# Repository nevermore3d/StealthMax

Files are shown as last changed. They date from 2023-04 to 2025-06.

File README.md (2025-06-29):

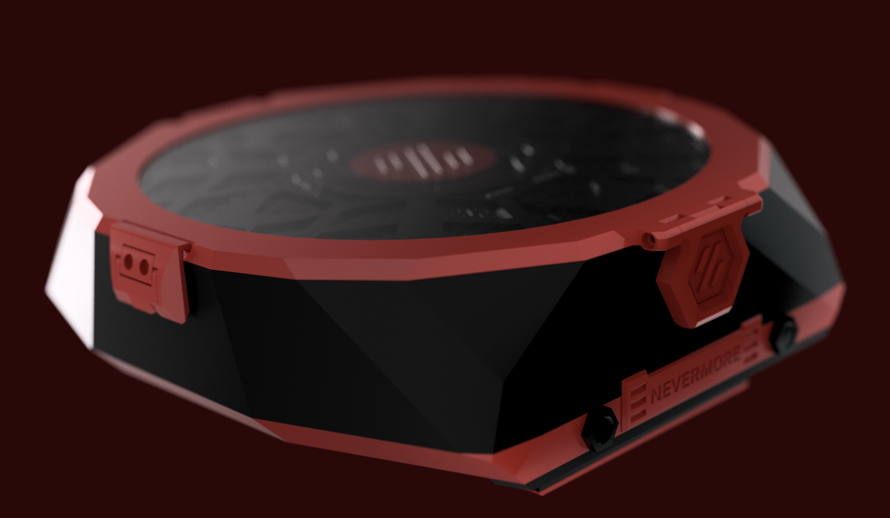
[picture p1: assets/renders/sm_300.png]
StealthMax


# Nevermore StealthMax
The Nevermore StealthMax is an air filter developed for 3D printers.
With its activated carbon and HEPA filtration, it aims to capture harmful fumes and unpleasant odors generated when melting plastics, creating a safer and more pleasant environment for makers.

 

# Table of Contents
1. [About](#1-about)<br>
   .1 [Nevermore3D](#11-nevermore3d)<br>
   .2 [StealthMax](#12-stealthmax)<br>
   .3 [Volatile Organic Compounds (VOCs) and Ultra-Fine Particles (UFPs)](#13-volatile-organic-compounds-vocs)
   
2. [Getting Started](#2-getting-started)<br>
   .1 [Overview](#21-overview)<br>
   .2 [Documentation](#22-documentation)

3. [Bill of Materials (BOM) and Sourcing Guide](#3-bill-of-materials-and-sourcing-guide)<br>
   .1 [StealthMax Kits](#31-stealthmax-kits)<br>
   .2 [Self Sourcing (BOM)](#32-self-sourcing-bom)

4. [Contributing](#4-contributing)<br>
5. [Acknowledgements](#5-acknowledgments)<br>
6. [Showroom](#6-showroom)

# (1) About

##  (1.1) Nevermore3D
Nevermore3D empower the 3D printing community with resources to create their own air filtration systems, promoting a safer and healthier printing environment.

 - ### History
   The project began in 2019 with the [Nevermore Micro](https://github.com/nevermore3d/Nevermore_Micro), a filtration system that has become widely adopted within the Voron community.<br>
   Since then, multiple filtration systems have been developed - with more to come!

    <br>
      

 - ### Nevermore Carbon and other Filtration Media
   When users reported issues of oxidizing and damaging their printers due to bad carbon, we set out to find the most suitable carbon for 3D printing. After consulting leading suppliers, Nevermore3D now offers its own premium carbon of unmatched specifications through selected [resellers](https://github.com/nevermore3d/Reseller).<br>
   Its usally one of the cheapest options in carbon performance/gram as it captures up to 2x its competition, though it might cost more per kilo compared to bulk options; Nevermore Carbon is safe to use in 3D printing environments, offers unbeatable effectiveness targeted at 3D printing VOCs specifically, and every purchase directly contributes to the ongoing development of the Nevermore3D project. Read more on how to evaluate carbon for 3D printing on our [reseller](https://github.com/nevermore3d/Reseller) page!

    - #### Nevermore Carbon
      -   Highly micro-porous and laboratory tested premium activated carbon, from a major European manufacturer
      -   Market-leading VOC adsorption fine tuned for _aromatic hydrocarbons emitted during 3D printing_ such as styrene, benzaldehyde, toluene, benzene, etc. [**CTC >=80**, benzene adsorption capacity up to **0.48g/g**]
      -   Market-leading surface area (storage capacity) of **1250m2/g**!
      -   Vacuum packed for minimal dust generation during shipping.
      -   Vacuum dedusted during the packaging process for immediate use in 3d printers
      -   Available in Regular (750ml, 0.33kg) and XL (2300ml, 1kg)

    - #### Nevermore Scorch
      -   Zeolite-based, highly microporous adsorption medium, enhanced with potassium permanganate (KMnO4).
      -   Chemically transform printer VOC toxins like styrene – a major VOC in ABS and ASA filaments – into harmless potassium benzoate (food additive).
      -   The process is not harmed by high chamber temps, but accelerated, making Nevermore Scorch ideal for heated 3D printer chambers!
      -   Colour changes from bright purple to a dullish gray as it is being spent, giving a visual indication of when it is time to swap filter media!
      -   Available in Regular (750ml, 0.66kg) and XL (2300ml, 2kg)

    - #### Nevermore Boost
      -   Pre-prepared 50/50 mix of Nevermore Carbon and Nevermore Scorch; a less-hassle, best-of-both-worlds printer filtration
      -   Combining the long-life och stellar adsorption capacity of activated carbon with Nevermore Scorch performance in hot surroundings.
      -   Ideal for most users with enclosed 3d printers printing ABS/ASA/PETG/PC in chamber temps of 50C +-10C.

    - #### Nevermore HEPA
      -   Nevermore HEPA Filters

## (1.2) StealthMax
The Nevermore StealthMax improves upon the [Nevermore Max](https://github.com/nevermore3d/Nevermore_Max) with a more warp-resistant frame, smaller size, optional exhaust for cooler printing, and easier assembly.

With its 2-liter carbon basket, it can hold 20 times as much carbon as the Nevermore Micro, and thanks to its innovative dual filtration design, the StealthMax allows for recirculation of filtered air within an enclosed printer to both maintain chamber temperature and further improve filtration efficiency and longevity.

 - #### Dual Filtration
   The StealthMax does not make any compromises and utilizes activated carbon and HEPA filtration:
      
   -   **Activated carbon filter:** This type of filter is designed to absorb volatile organic compounds (VOCs). VOCs are gases emitted during 3D printing, and they can cause irritation to the eyes, nose, and throat. An activated carbon filter can help to reduce odors and improve air quality.

   -   **HEPA (High Efficiency Particulate Air) filter:** This type of filter is effective at capturing tiny particles 2.5um in diameter and below (in 3D printing often _much_ smaller). These particles can - compared to larger PM2.5  particles - have direct toxic effects if inhaled, so a HEPA filter goes a long way to capture both small particles as well as any carbon dust, improving air quality furter in your printing space.

 - #### Recirculation
   The StealthMax and your printer's enclosure function as a closed-loop system, enabling air to recirculate through the filter multiple times. 
   This results in a significantly higher capture rate of harmful particles compared to a single-pass exhaust filter.<br>
   The effectiveness of this process is diminished if the enclosure has leaks, however, opening the exhaust slider creates a slight negative pressure inside the enclosure, thus drawing air in through leaks and maximizing the StealthMax's filtration potential.

 - #### StealthMax S (250)
   Making safer printing more accessible, the StealthMax S was designed for printing on a 250x250mm bed.<br>
   Despite its compact size, the StealthMax S retains impressive filtering capacity thanks to its 1.4-liter carbon basket as well as the benefits of dual filtration.
   [Read more](.../../assets/_unsorted/Stealthmax_S)

## (1.3) Volatile Organic Compounds (VOCs) and Ultra-Fine Particles (UFPs)
When 3D printing, especially with certain types of materials like plastics, various [volatile organic compounds (VOCs)](https://en.wikipedia.org/wiki/Volatile_organic_compound) can be emitted. The specific VOCs produced can vary depending on the type of filament or resin used and the printing conditions. Some common VOCs emitted during 3D printing include:

-  **Styrene**: Commonly emitted when printing with ABS (Acrylonitrile Butadiene Styrene) filament. Styrene exposure has been linked to respiratory issues, irritation of the eyes, nose, and throat, and in some cases, long-term exposure may increase the risk of cancer.
    
-  **Formaldehyde**: Often produced during the thermal decomposition of certain plastics, such as PLA (Polylactic Acid). Formaldehyde exposure can cause irritation of the eyes, nose, and throat, as well as respiratory issues. Prolonged exposure to high levels of formaldehyde has been linked to an increased risk of cancer.
    
-  **Acetaldehyde**: Another byproduct of thermal decomposition, commonly found in emissions from ABS and PLA printing. Acetaldehyde exposure can cause irritation of the eyes, nose, and throat, and may also affect the central nervous system.
    
-  **Acrylonitrile**: Present in emissions from ABS filament, acrylonitrile exposure has been associated with respiratory issues and may increase the risk of certain cancers.
    
-  **Ethylene glycol**: Found in emissions from certain types of resins used in stereolithography (SLA) printing, ethylene glycol exposure can cause irritation of the eyes, skin, and respiratory system.

-  **Butadiene**: Present in ABS-type filaments, as well as rubber additives, long exposures to Butadiene is a known accellerator or cardiovascular disease (heart attacks and strokes), increases the risk of certain cancers, and is suspected to impact fetal development (teratogen).
    
Volatile Organic Compounds (VOCs) can have a range of health effects that vary based on factors such as concentration, duration of exposure, and individual susceptibility. Short-term exposure to high levels of VOCs can cause respiratory tract irritation, headaches, dizziness, and nausea. Prolonged exposure to certain VOCs is associated with more severe health issues, including respiratory problems, an increased risk of cancer, and vascular diseases such as stroke and heart attacks.

Just as individual VOCs can be released into the air, clusters of VOCs, known as **Ultra-Fine Particles (UFPs)**, are also emitted. These particles begin their existence extremely small, with diameters of only 10-15 nm — for comparison, a single VOC molecule is typically about 1 nm, and the grid of a HEPA filter is 20 times larger than a newborn UFP.

If not addressed, these Ultra-Fine Particles gradually coalesce into larger droplets, eventually reaching sizes of about 50-100 nm. At this size, they can be captured by HEPA filters, unless they have already dispersed into the surrounding air. UFPs droplet agglomerates often consist of mixed, room-temperature-viscous VOC oils such as styrene, with some solid components (such as stearic acid, if your chamber is cooler than 70C or so). Unlike larger particles that may accumulate in the airways, breathed UFPs are absorbed by the body—VOC by VOC—similar to inhaled medication, and can exert the same toxic effects as the individual VOCs they contain.

Moreover, carbon porosity is not limited to micropores (carbon pores smaller than 2 nm) but also extends to mesopores (carbon pores 2-50 nm), which can adsorb UFPs before they agglomerate or soak the HEPA. Finally, any carbon dust or larger UFPs bypassing carbon filtering, can be safely collected by the dual integrated HEPA filters of the Stealthmax.

# (2) Getting Started

## (2.1) Overview
Different printers and use cases require different solutions - choose the StealthMax that fits your needs!
 - ### Regular StealthMax (300) or StealthMax S (250)?
   The StealthMax comes in two sizes:
   | | Regular StealthMax (300) | StealthMax S (250) |
   | ---| --- | --- |
   | Min. Req. Bed Size | 300x300mm | 250x250mm|
   | Carbon Capacity | 2.0 liters | 1.4 liters |
   | HEPA Filter | HEPA Filter for Xiaomi Mijia G1 | Nevermore HEPA Filter |
   | Fan | Delta BFB0712HF | Delta KFB0612HAFDB |

 - ### Back Panel Mount or Direct On Panel Mount?
   The are two options for mounting a StealthMax to your printer:
    - #### Back Panel Mount (BPM)
      The Back Panel Mount is designed to be used with Voron printers (in particular Voron 2 and Trident) by utilizing the back panel's cutout and mounting the StealthMax to the top 2020 extrusion.
    - #### Direct On Panel Mount (DOPM)
      Alternatively, the Direct On Panel Mount can be used to mount a StealthMax on pretty much any panel.
	  [Read more](.../../assets/_unsorted/Direct-On-Panel_Mount)

 - ### Basic or Smart?
    - #### Basic
      Simpler to set up, a sensorless StealthMax only requires the appropriate fan, a 12VDC power source (s. [Power Source](#power-source)) and PWM control (e.g. by using your printer's electronics or a Pico).
    - #### Smart
      Thanks to the [Nevermore Controller](#nevermore-controller), a smart StealthMax utilizes VOC, temperature and humidity sensors to monitor air quality and automatically adjust fan speed.

 - ### Add-ons
   Increase the capability of your StealthMax further and explore our range of add-ons:

    - #### CPAP
      Moves the intake closer to the hotend by attaching it directly to the gantry, maximizing VOC capture potential.

    - #### Displays
      [WORK IN PROGRESS / EARLY DEVELOPMENT]<br>
      Upgrade your StealthMax with a GC9A01 or CST816S display to monitor it's effectiveness at a glance.

    - #### Photocatalytic Oxidation (PCO) Filtration
      [WORK IN PROGRESS / EARLY DEVELOPMENT]<br>
      PCO Filtration mimics the sun's natural breakdown of VOCs. Utilizing UVC lights and a TiO2 mesh, it generates hydroxyl radicals to dismantle VOCs into harmless compounds. This method enhances efficiency by addressing stubborn VOCs, maintains cleanliness between prints, and adapts to heat conditions for optimal performance.
      [Read more](.../../assets/_unsorted/PCO)

 - ### User Mods
   Find clever solutions and unique customizations with our collection of [User Mods](/UserMods) contributed by fellow community members.

## (2.2) Documentation
 - ### Manual
   soon<sup>tm</sup><br>
   In the meantime, you may find the [DOPM focused installation documentation](https://github.com/nevermore3d/StealthMax/blob/main/Docs/DOPM/DOPM_Preparation.md) useful.

 - ### Print Guide
   Our interactive [Print Guide](https://bit.ly/NevermoreStealthMaxPrintGuide) helps you find the parts you need to print and lets you download all the required STL files at once.

 - ### Nevermore Controller
   A Raspberry Pi Pico W based controller for the Nevermore3D family of 3D printer filters created and maintained by [@SanaaHamel](https://github.com/SanaaHamel). Compatible with Klipper, it offers automatic fan control and leverages Bluetooth LE technology to reduce wiring needs and allow for multiple device connections.
   [Read more](https://github.com/SanaaHamel/nevermore-controller)

# (3) Bill of Materials and Sourcing Guide

#### Power Source
The StealthMax Kits and Bill of Materials (BOM) do not include a power source.<br>
You will need to choose between one of the following options:
-   A 12V power supply unit (PSU) with a minimum rating of 1.5 Amps.
-   Utilize a voltage-selectable fan port on your printer's electronics (if available).

## (3.1) StealthMax Kits
For those who value convenience and simplicity, kits eliminate the guesswork and ensure you have everything you need.

| Kit | StealthMax Size | Sources |  |  |  |
|---|---|---|---|---|---|
| Basic | 300 (Regular) | UK [OneTwo3D](https://www.onetwo3d.co.uk/product/nevermore-stealthmax-filter-kit-basic/?wpam_id=2) |  |  |  |
| Basic S | 250 (S) | UK [OneTwo3D](https://www.onetwo3d.co.uk/product/nevermore-stealthmax-filter-s-kit-basic/?wpam_id=2) |  |  |  |
| Smart | 300 (Regular) | UK [OneTwo3D](https://www.onetwo3d.co.uk/product/nevermore-stealthmax-filter-kit/?wpam_id=2) | US [FYSETC](https://s.click.aliexpress.com/e/_msl6FbE) | US [Central 3D Printing](https://central3dprinting.com/products/nevermore-stealthmax-kit?ref=NEVERMORE3D) | US [Mandala Rose Works](https://mandalaroseworks.com/products/nevermore-stealthmax-hardware-kit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) | Sweden [3DKATTEN](https://3dkatten.se/en/products/stealthmax-kit?_pos=2&_sid=fafe2628b&_ss=r) |
| Smart S | 250 (S) | UK [OneTwo3D](https://www.onetwo3d.co.uk/product/nevermore-stealthmax-s-filter-kit-advanced/?wpam_id=2) | US [Central 3D Printing](https://central3dprinting.com/products/nevermore-stealthmax-s-hardware-kit?ref=NEVERMORE3D) | US [Mandala Rose Works](https://mandalaroseworks.com/products/nevermore-stealthmax-s-small-hardware-kit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) |  |
| Fasteners | _both_ | UK [OneTwo3D](https://www.onetwo3d.co.uk/product/nevermore-stealthmax-fastener-kit/?wpam_id=2) | | | |
| Printed Parts | 300 (Regular) | UK [JB3D](https://jb3d.uk/product/nevermore-stealthmax/) |  |  |  |
| Printed Parts | 250 (S) | UK [JB3D](https://jb3d.uk/product/nevermore-stealthmax-s-printed-parts-kit/) |  |  |  |

Affiliate links: may earn the Nevermore3D project a small commission (at no extra cost to you).

## (3.2) Self Sourcing (BOM)
For those who find satisfaction in the journey, each meticulously sourced component adds to the story of their creation.

See our interactive [Bill of Materials / Sourcing Guide](https://bit.ly/NevermoreStealthMaxBOM) for a complete list of components.

# (4) Contributing
**We welcome your contributions!** <br>
Report any difficulties, suggest ideas, propose solutions, and create new designs or enhance existing ones.
Whether on GitHub or the [Nevermore Discord](https://discord.gg/H8tZ9fZVQ4), your input is valued and appreciated!



# (5) Acknowledgments
Special thanks for all the help, nudges, support and additions to the project, goes to:
- [@SanaaHamel](https://github.com/SanaaHamel)
- [@FatalBulletHit](https://github.com/FatalBulletHit)
- @TubaToothpasties
- [@Blamm](https://github.com/bartlammers)
- [@Backslash](https://github.com/UnPure)
- [@Exerqtor](https://github.com/Exerqtor)
- [@AdamV3D](https://github.com/AdamV3D)
- [@rajenki](https://github.com/rajenki)

# (6) Showroom
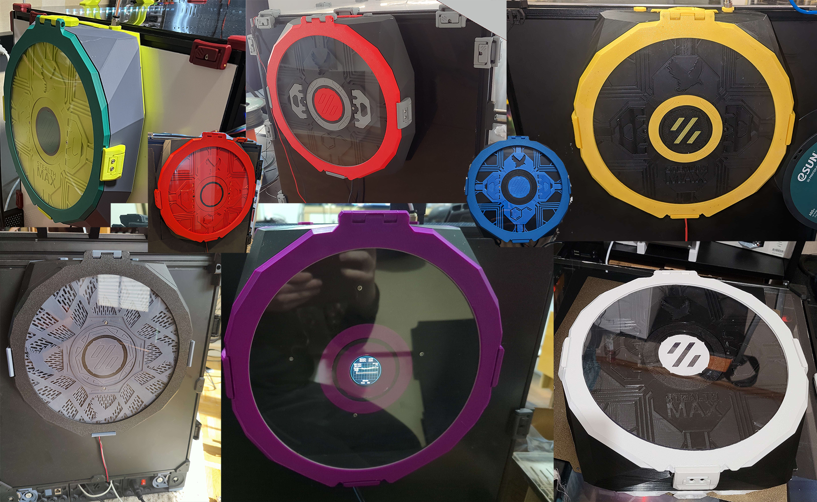
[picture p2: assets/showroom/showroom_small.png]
StealthMax Showroom

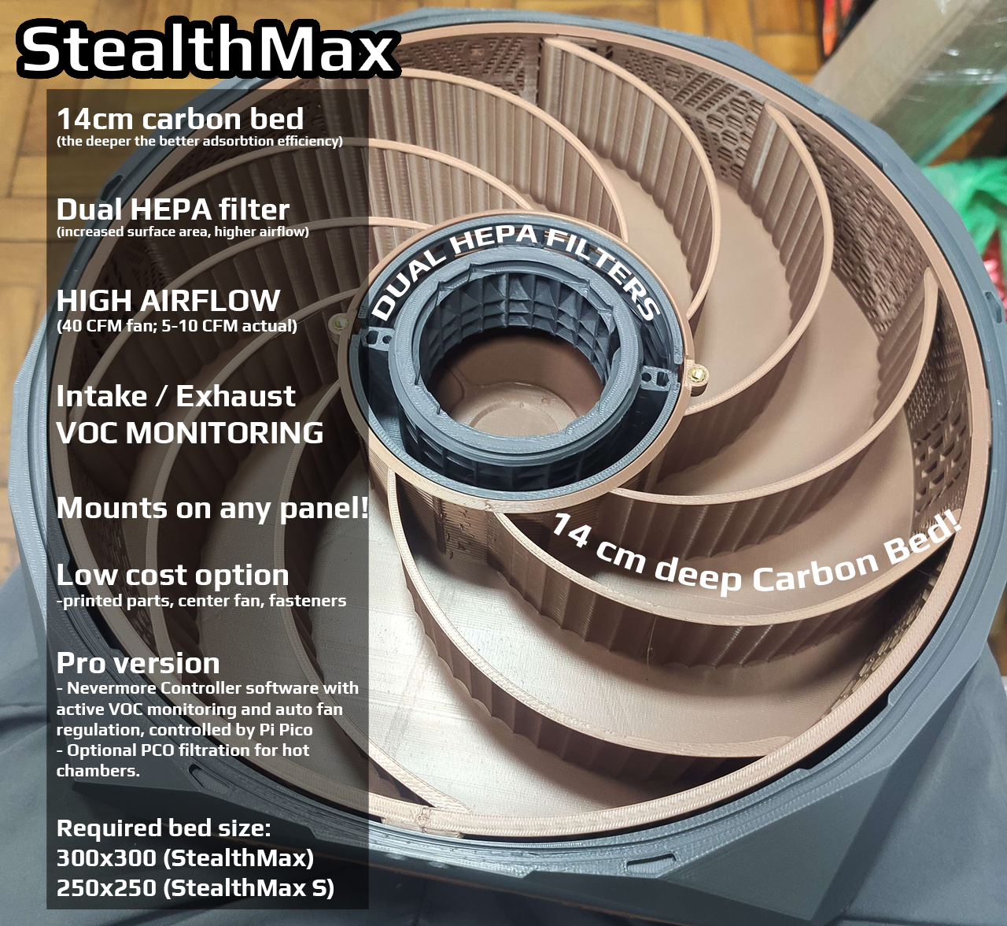
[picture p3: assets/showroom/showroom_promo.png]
StealthMax Promo


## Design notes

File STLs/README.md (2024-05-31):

# Print Guide
Check out our interactive [Print Guide](https://bit.ly/NevermoreStealthMaxPrintGuide)!

For printing tips and tricks, see the [Nevermore StealthMax Wiki](https://github.com/nevermore3d/StealthMax/wiki).

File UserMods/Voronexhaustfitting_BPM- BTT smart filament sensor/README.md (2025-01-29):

Added a bracket for the BTT smart filament sensor V2.  
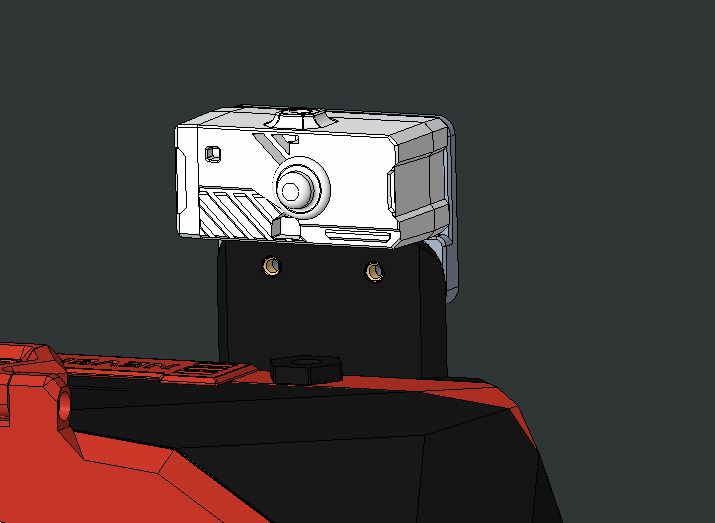
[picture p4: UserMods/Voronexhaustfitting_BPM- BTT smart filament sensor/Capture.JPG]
assembly
  
additionally need 2pcs M3 heat set insert and 5pcs M3 SHCS screws.

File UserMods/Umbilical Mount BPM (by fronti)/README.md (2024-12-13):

I couldn't get a decent umbilical passthrough working for my Stealthmax S, so i merged the Back Panel Mount with [Another Umbilical Toolhead](https://www.printables.com/model/411846-another-toolhead-umbilical-for-voron-24).

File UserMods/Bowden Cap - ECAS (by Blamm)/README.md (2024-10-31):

ECAS Bowden Cap

A custom version of the [Bowden Cap](/STLs/1_FlowChamber/1.3b_BowdenCap_Open.stl) designed to accomodate an ECAS coupler.
To be used for alternative cable routing through the Bowden Cap together with the [Cable Entry Cap (Closed)](/STLs/1_FlowChamber/1.4b_CableEntryCap_Closed.stl).

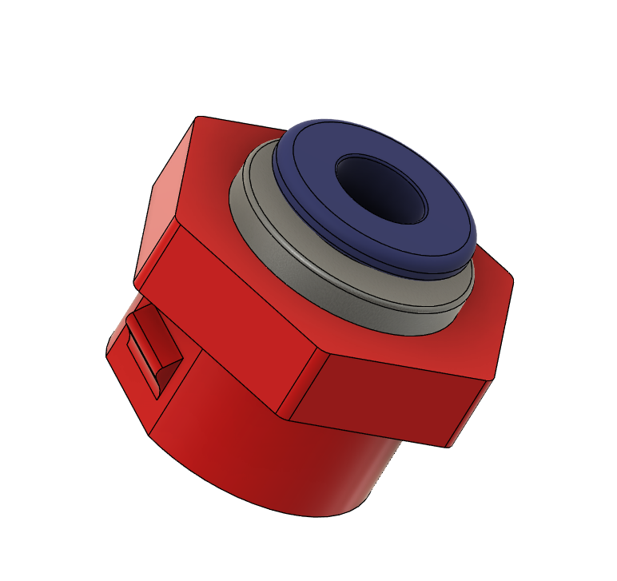
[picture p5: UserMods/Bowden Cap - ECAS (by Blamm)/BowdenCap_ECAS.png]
ECAS Bowden Cap


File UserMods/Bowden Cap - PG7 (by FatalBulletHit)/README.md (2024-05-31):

A custom version of the [Bowden Cap](/STLs/1_FlowChamber/1.3b_BowdenCap_Open.stl) designed to accomodate a PG7 cable gland with strain relief.<br>
To be used for alternative cable routing through the Bowden Cap together with the [Cable Entry Cap (Closed)](/STLs/1_FlowChamber/1.4b_CableEntryCap_Closed.stl).

Sources: [Bimed cable gland, PG7](https://www.traceparts.com/en/product/automationdirect-bimed-cable-gland-pg7-thread-type-polyamide-black-accepts-3-to-65mm-diameter-cable-ip68-with-strain-relief-pac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)

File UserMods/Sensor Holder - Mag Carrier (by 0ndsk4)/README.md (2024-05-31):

Idea was to have a detachable screen for the SMS type layout with no center hub. Only problem is 4-pin is not enough (if not a I2c screen that can daisy chain on the sensor connection).
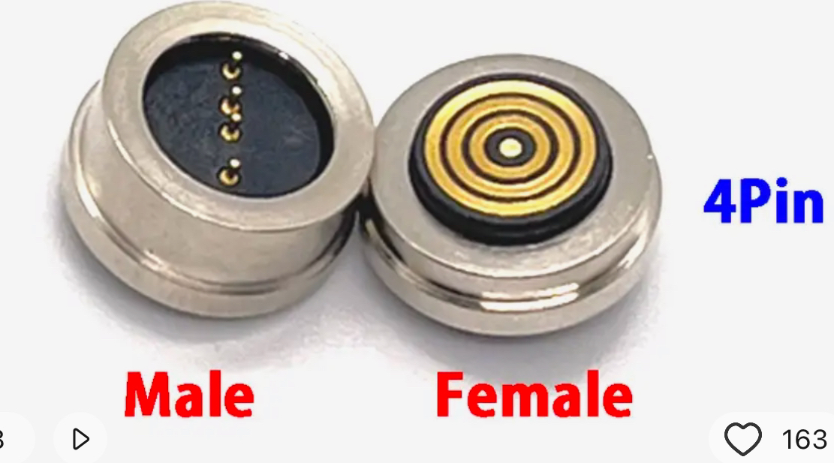
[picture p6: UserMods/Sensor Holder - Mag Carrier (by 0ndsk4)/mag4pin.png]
Magnetic 4 Pin Connector


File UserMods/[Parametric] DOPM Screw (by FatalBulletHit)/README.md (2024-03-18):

A parametric version of the default [Direct On Panel Mount Screw](/STLs/0_Mount/0b_DirectOnPanelMount/0b.1_DirectOnPanelMountScrew_DOPM.stl) for panels thicker than 3mm.

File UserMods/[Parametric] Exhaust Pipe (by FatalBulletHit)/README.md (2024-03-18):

A parametric version of the default [Exhaust Pipe](/STLs/0_Mount/0b_DirectOnPanelMount/0b.2_ExhaustPipe_DOPM.stl) for panels thicker than 3mm.

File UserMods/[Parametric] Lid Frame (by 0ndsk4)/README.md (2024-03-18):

A parametric version of the default [Lid Frame](/STLs/3_Lid/StealthMax/M_3.0_LidFrame.stl) and [Lid Panel Holder](/STLs/3_Lid/StealthMax/M_3.1_LidPanelHolder.stl) for non standard lid panels.

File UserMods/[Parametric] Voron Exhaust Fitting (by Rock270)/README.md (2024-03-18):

**Parametric exhaust fitting by Rock270**

This is a parametric clone of the default [Voron Exhaust Fitting (Back Panel Mount)](/STLs/0_Mount/0a_BackPanelMount/StealthMax/M_0a.0_VoronExhaustFitting_BPM.stl) for use on panels of thicknesses larger than 4mm. If you wish to use this, instead of printing "M_0a.0_VoronExhaustFitting_BPM.stl", print one "M_VoronExhaustFitting_BPM_Xmm" with the desired panel thickness.

If you wish to use a panel thickness not supplied, simply open "Parametric Exhaust Fitting BPM (by Rock270)" and modify the "panel_thickness" parameter.

Use the following information to get your new screw sizes.

Current affected screws
```
M3x10 x4
M3x12 x7
M3x25 x2
```

Each screw length is to be increased by panel_thickness-4.

New screws
```
4x: M3x(6+panel_thickness) (Threads into heat set inserts in the flow chamber, followed by empty air. Probably ok to be long by a few mm)
7x: M3x(8+panel_thickness) (Threads into 11mm holes in the flow chamber, probably ok to be short by a few mm)
2x: M3x(21+panel_thickness) (Important, these hold the filter/panel to frame. Try to get these in the correct length)
```

Example:
I want a 14mm panel. I will need:
```
4x: M3x20 SHCS
7x: M3x22 SHCS
2x: M3x35 SHCS
```
In the default configuration, the M3x12 screws thread directly into an 11mm hole in the voron exhaust fitting. As 22mm is an odd screw size, M3x20 SHCS screws will suffice for these screws. 35mm and 20mm are common screw lengths so no changes are needed.

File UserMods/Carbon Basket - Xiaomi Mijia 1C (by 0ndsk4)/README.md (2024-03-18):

A basket for the Xiaomi Mijia 1C HEPA filter. Enjoy with caution, has the tendency to break apart if tabs are not removed:
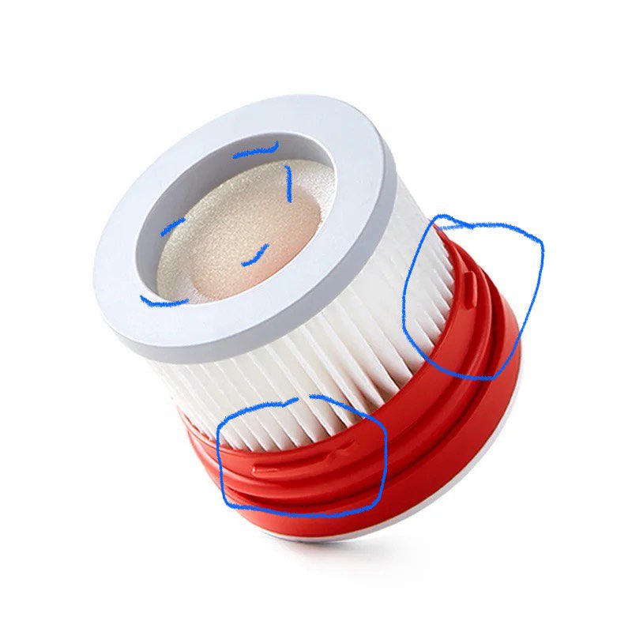
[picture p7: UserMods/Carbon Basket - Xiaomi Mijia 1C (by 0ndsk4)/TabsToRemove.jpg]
TabsToRemove


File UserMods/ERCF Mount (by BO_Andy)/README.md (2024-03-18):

A mount for the [Enraged Rabbit Carrot Feeder MMU](https://github.com/Enraged-Rabbit-Community/ERCF_v2) that allows the MMU to be positioned above a back panel mounted StealthMax.

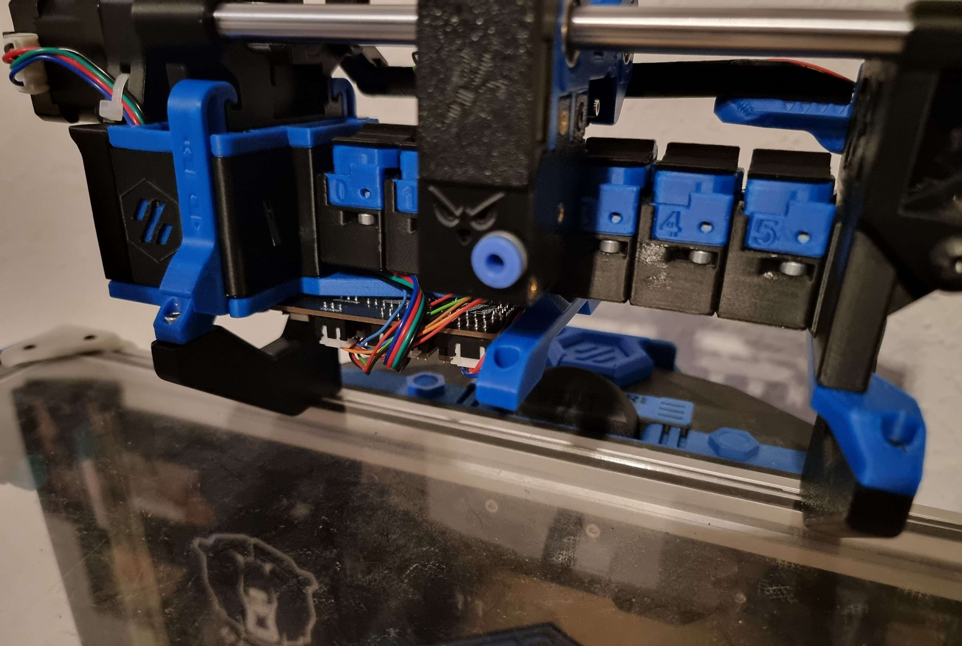
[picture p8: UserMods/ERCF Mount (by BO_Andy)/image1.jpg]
ERCF_Mount

<BR>
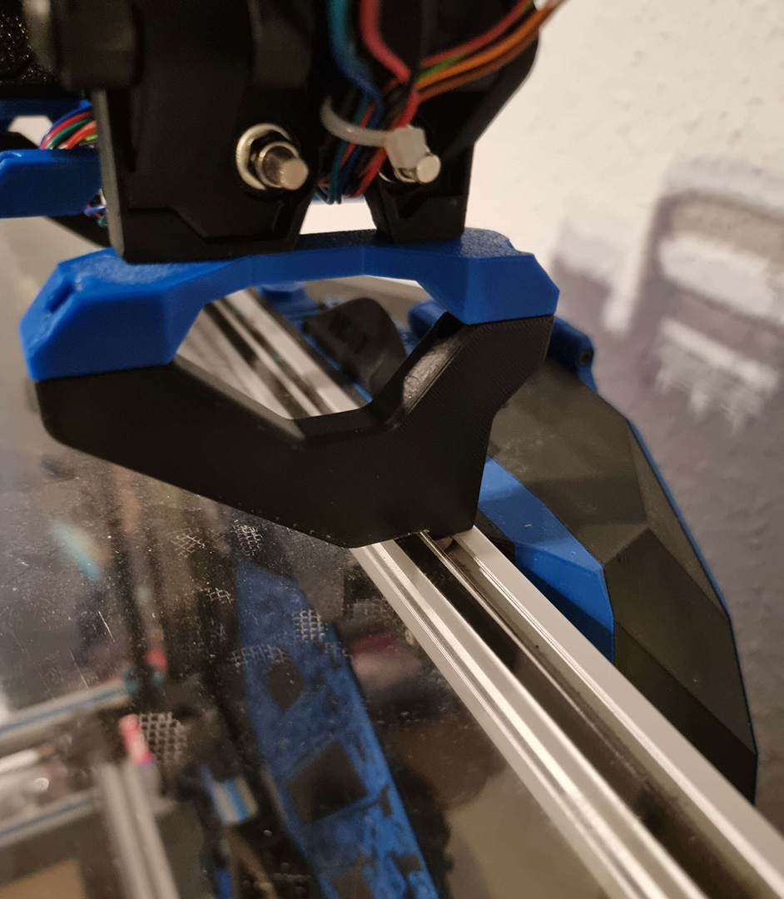
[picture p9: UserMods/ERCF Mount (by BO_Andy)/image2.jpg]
ERCF_Mount


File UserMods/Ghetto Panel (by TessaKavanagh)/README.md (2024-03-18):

A printed alternative to the acrylic panel used in the lid.

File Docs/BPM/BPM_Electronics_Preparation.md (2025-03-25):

# Back Panel Mount (BPM) Smart Electronics Preparation

These are instructions for the StealthMax (300) Smart Back Panel Mount (BPM). The majority of this part is borrowed from the DOPM documentation but with replaced images for continuity.

## Parts Required

Printed parts:
- 1x [1.4a_CableEntryCap_M8Barrel.stl](../../STLs/1_FlowChamber/1.4a_CableEntryCap_M8Barrel.stl)

Hardware:
- Raspberry Pi Pico W
- Female Dupont pins
- Male JST-PH 2.0 pins
- 1x M8 threaded DC connector
- 1x Matek Systems MBEC6S/MBEC2A
- 2x BME280
- 2x SGP40/SGP30
- 3x right angle 4-pin male header
- 1x right angle 5-pin male header
- 2x straight 4-pin male header
- 5x 4-pin female DuPont connector housing
- 1x 4-pin JST-PH 2.0 male pin/female connector housing

Tools:
- DuPont crimping tool
- JST crimping tool

## Back Panel Mount (BPM) Smart Electronics Preparation

1. With the Raspberry Pi Pico W accessible, start by flashing the latest controller firmware on it according to the [Nevermore Controller Setup Guide](https://github.com/SanaaHamel/nevermore-controller#guide-setup). In short:
   - Download the latest Nevermore Controller uf2 binary.
   - Connect the Raspberry Pi Pico W via USB Micro to a computer while holding down the BOOTSEL button.
   - Copy the downloaded .uf2 binary to the RPI-RP2 drive.
     - The Raspberry Pi Pico W will automatically reboot afterward.
   - SSH into your printer's Klipper host (e.g. a regular Raspberry Pi).
   - Install the Nevermore Controller Klipper module.
     - Restart your Klipper host if you enabled Bluetooth during the installation process.
   - Add the [minimal example configuration](https://github.com/SanaaHamel/nevermore-controller#klipper-config-minimal) to your printer.cfg.
   - We'll add the Nevermore macros from the Nevermore Controller Setup Guide to the relevant print start/end macros, and calibrate the sensors at a later stage.

1. Remove the nut from the M8 threaded DC connector and solder 75mm red and black 24 AWG wires to it. Apply a small section of heat shrink tubing to both leads, then slide the cables through the [1.4a_CableEntryCap_M8Barrel.stl](/STLs/1_FlowChamber/1.4a_CableEntryCap_M8Barrel.stl) and thread in the M8 threaded DC connector securely. Adding heatshrink over the soldered joints would be a good idea at this point.
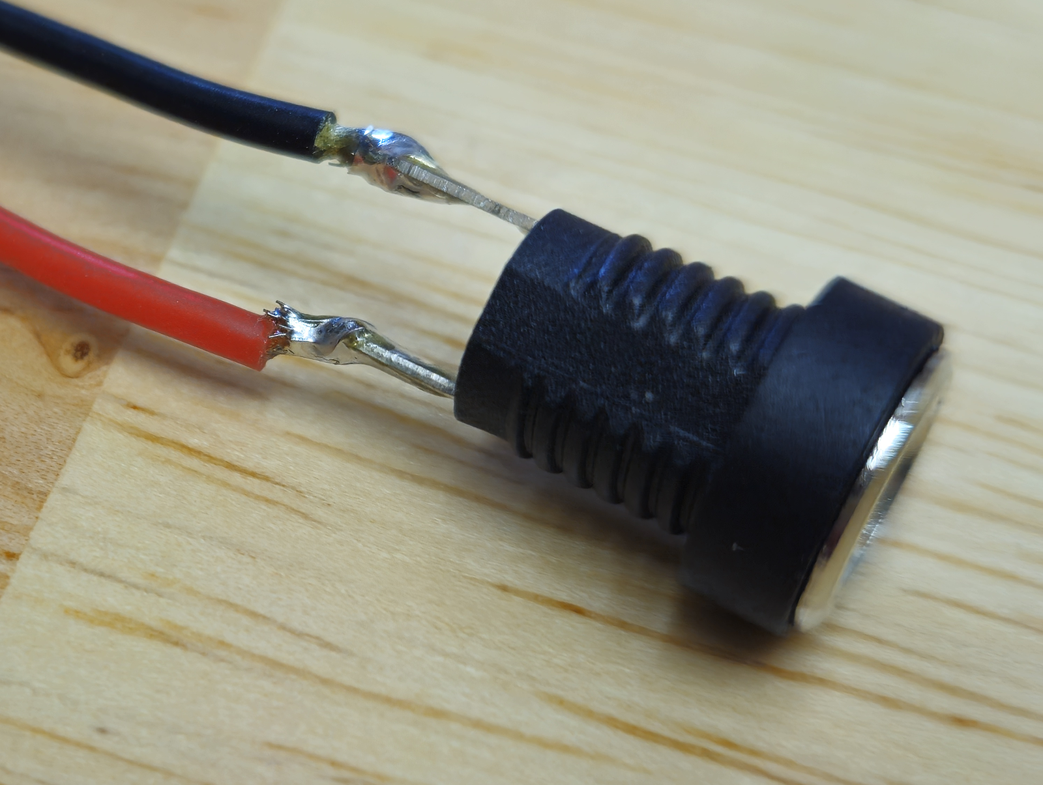
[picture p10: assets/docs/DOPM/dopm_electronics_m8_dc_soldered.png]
M8 threaded DC connector soldered

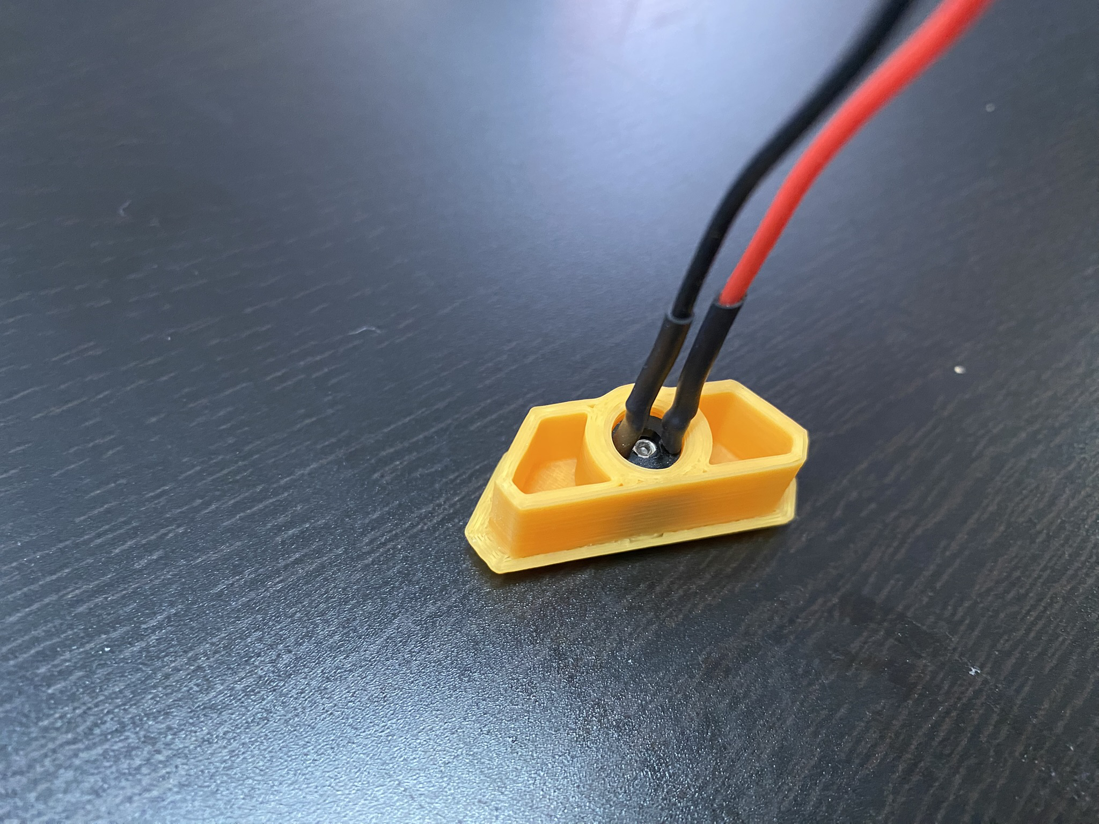
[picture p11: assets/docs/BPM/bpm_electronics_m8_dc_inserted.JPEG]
M8 threaded DC connector inserted


1. Solder a right angle 4-pin male header to the Matek Systems MBEC6S/MBEC2A buck converter.
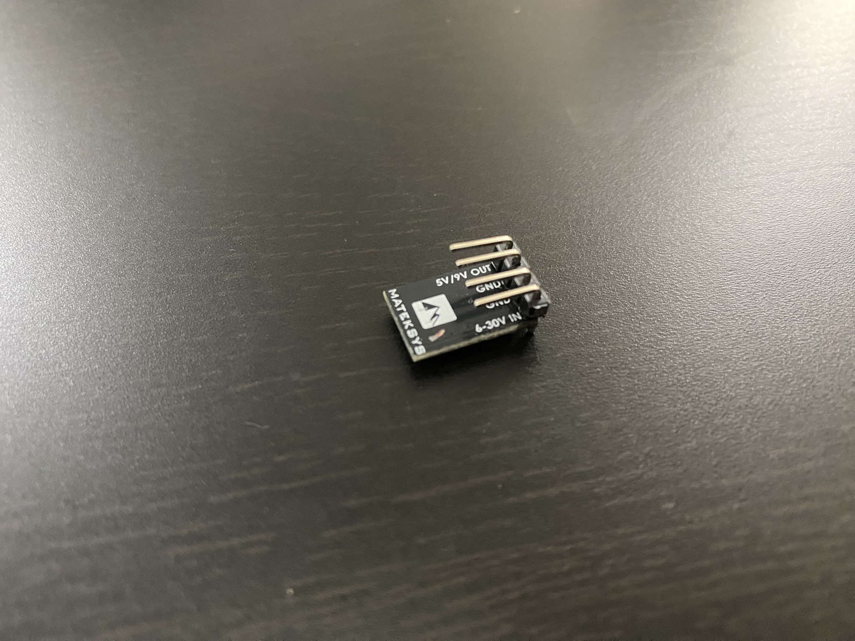
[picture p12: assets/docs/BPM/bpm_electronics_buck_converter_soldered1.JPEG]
Matek Systems MBEC6S/MBEC2A buck converter soldered

Matek Systems MBEC6S/MBEC2A buck converter soldered

1. Solder the straight 4-pin male header to each of the BME280 PCBs.
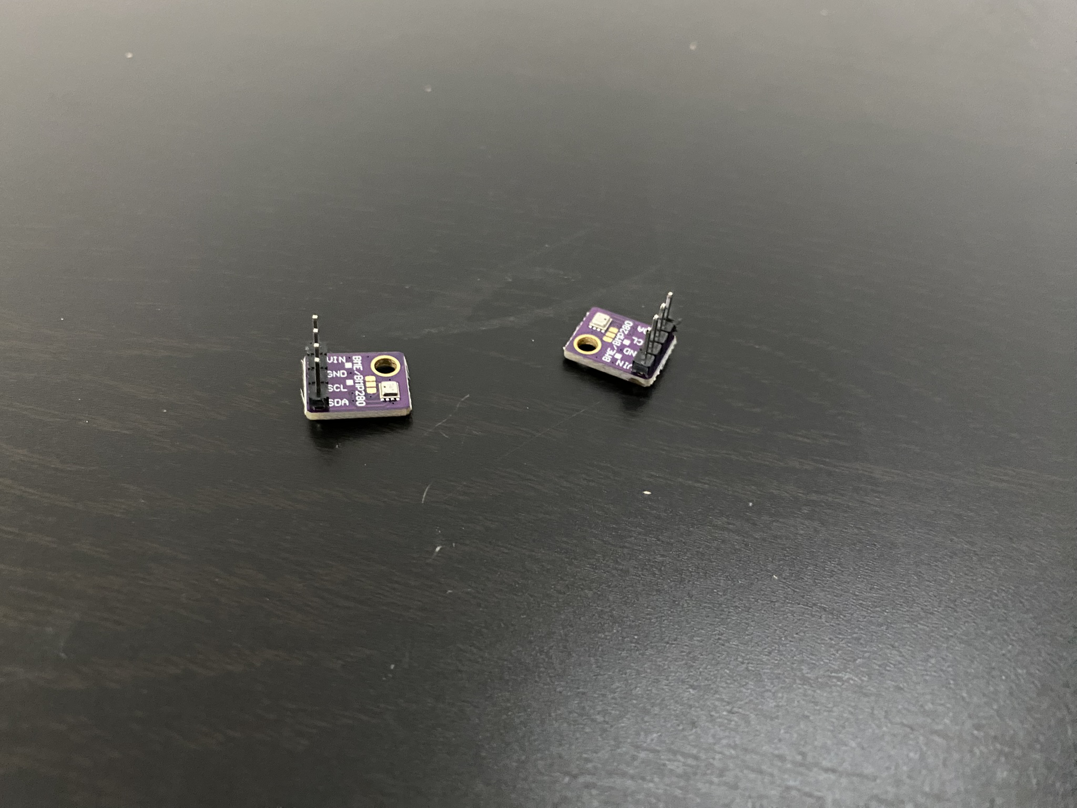
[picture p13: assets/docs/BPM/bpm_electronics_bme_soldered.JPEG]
BME280 PCBs soldered


1. Add the SGP40/SGP30 PCBs on top of each of the pins soldered to the BME280 PCBs and solder it from the other side. Take extra care to not leave excess solder here, as it may interfere with the DuPont connector later.
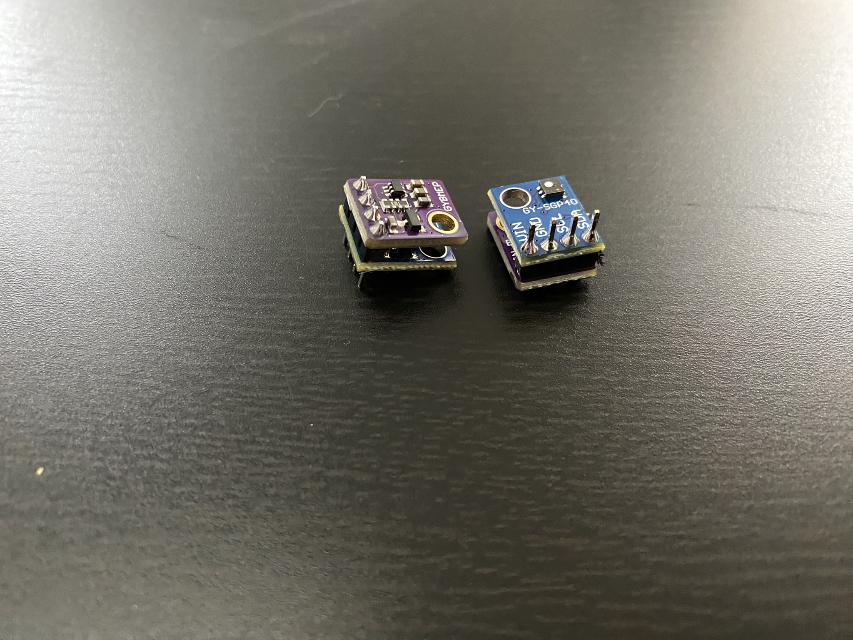
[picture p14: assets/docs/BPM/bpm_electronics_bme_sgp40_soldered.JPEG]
SGP40 PCBs soldered

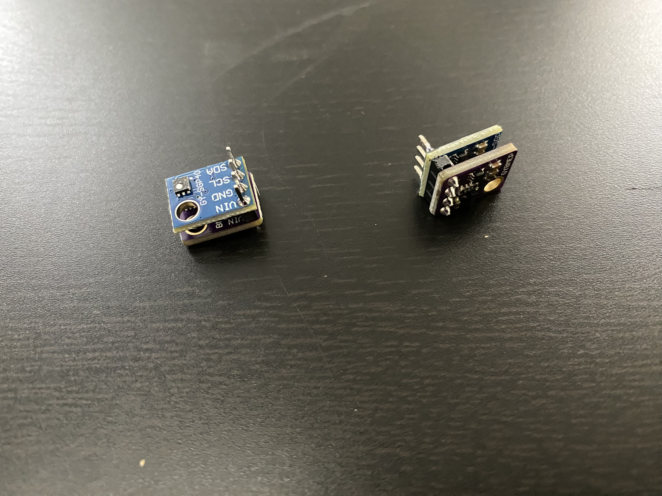
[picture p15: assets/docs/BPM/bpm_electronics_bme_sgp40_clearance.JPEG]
BME280 SGP40 pins clearance


1. Solder 2x right angle 4-pin male header and 1x right angle 5-pin male header to the Raspberry Pi Pico W.
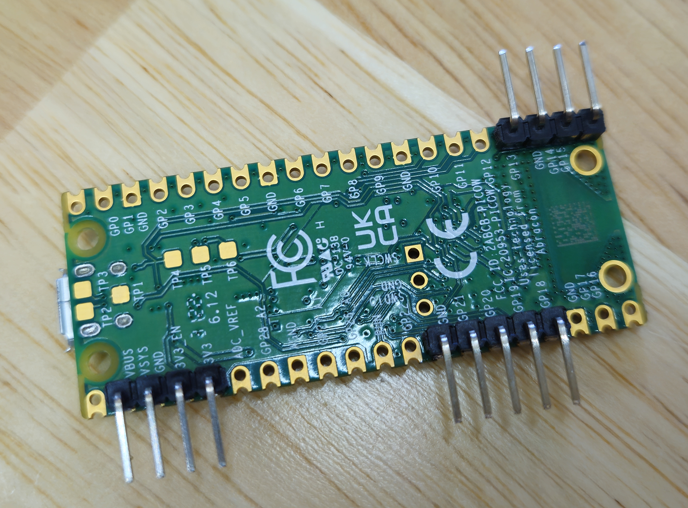
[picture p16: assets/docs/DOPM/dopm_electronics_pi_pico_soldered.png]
Raspberry Pi Pico W soldered


1. Crimp 4 DuPont female pins to the 325mm yellow, pink, black, and green 26 AWG wires. Insert the crimped wires into a 4-pin DuPont connector housing.
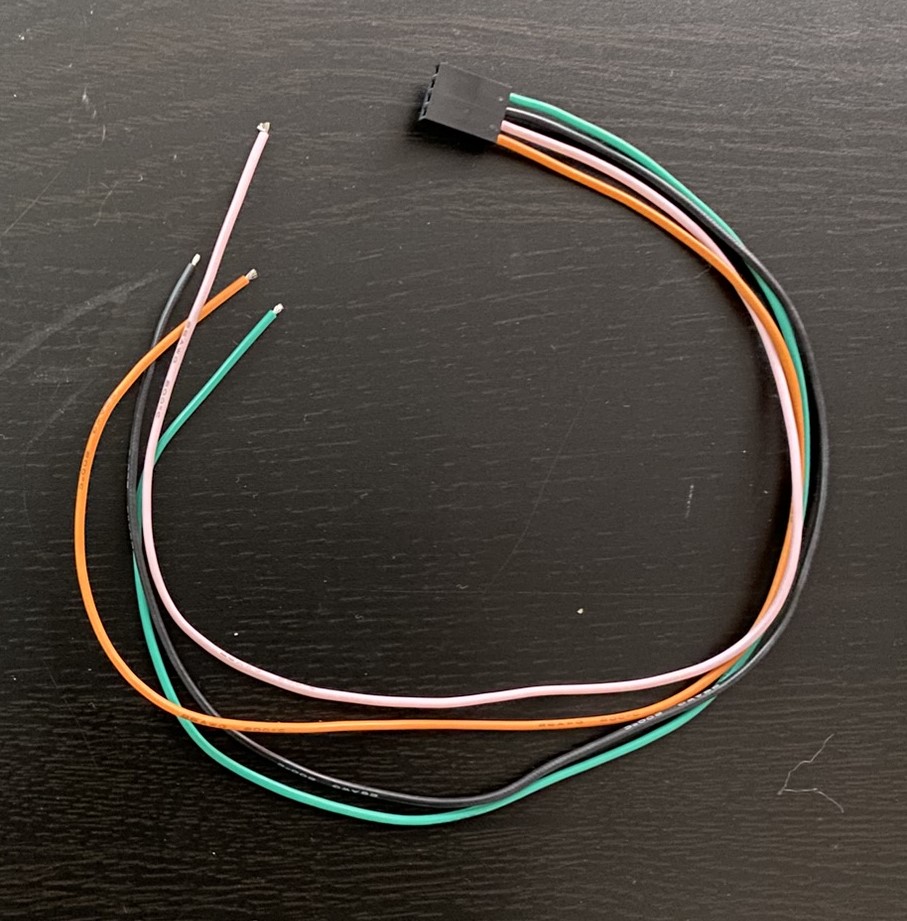
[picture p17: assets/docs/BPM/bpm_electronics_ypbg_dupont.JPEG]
Yellow/Pink/Black/Green DuPont connector


1. Crimp 4 DuPont female pins to the 300mm blue, gray, black, and green 26 AWG wires. Insert the crimped wires into a 4-pin DuPont connector housing.
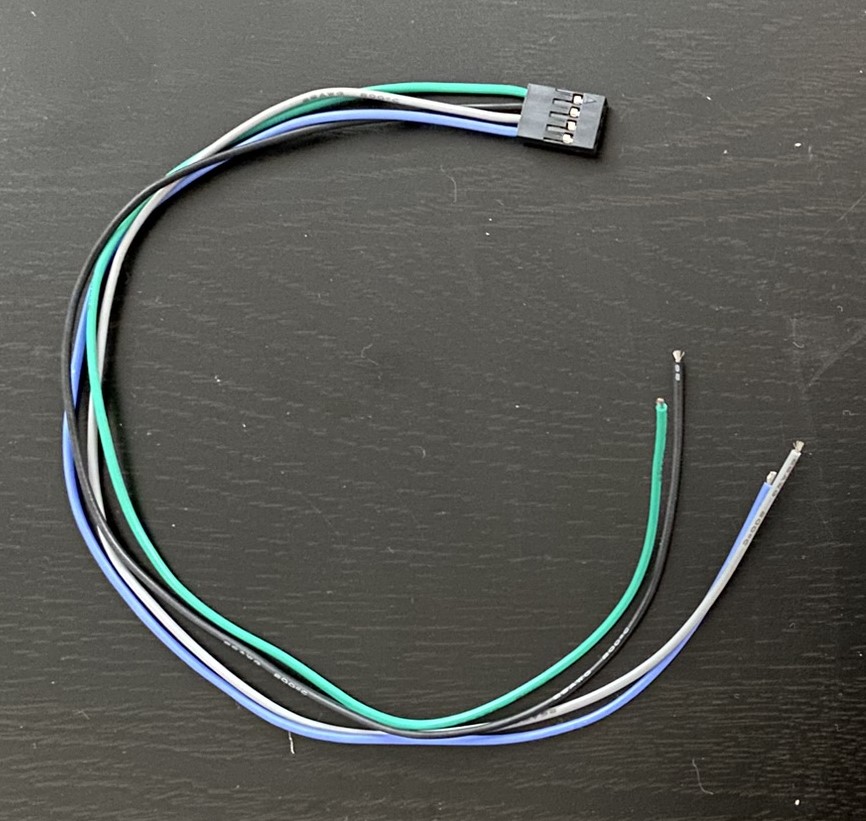
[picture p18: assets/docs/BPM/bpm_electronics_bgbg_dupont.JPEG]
Blue/Gray/Black/Green DuPont connector


1. Crimp 2 DuPont female pins to the other end of the blue and gray wires from step 7, and yellow and pink wires from step 8. Do not crimp the black and green wires yet on either cable harness.
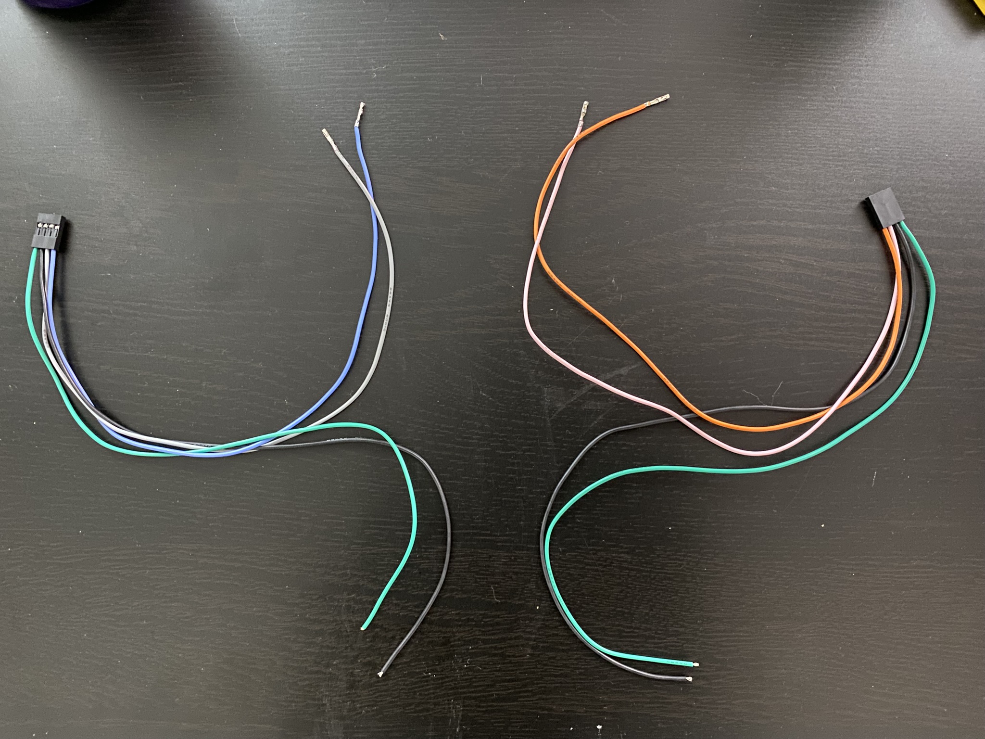
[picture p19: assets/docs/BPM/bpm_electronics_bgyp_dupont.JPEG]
Blue/Gray/Yellow/Pink DuPont pins


1.  Crimp 2 DuPont female pins to the 100mm violet and brown 26 AWG wires.
2.  Crimp 4 JST-PH 2.0 male pins to the 100mm violet and brown 26 AWG wires, and 200mm black and red 24 AWG wires. Insert the crimped violet and brown wires into a 4-pin DuPont connector housing, and the crimped violet, brown, red, and black wires into a 4-pin JST-PH 2.0 connector housing. There is a good example of this in the DOPM guide.
    - If you do not have JST-PH 2.0 male pins/female housing, solder the violet, brown, red, and black wires directly to a JST-PH 2.0 male housing, or a pre-crimped JST-PH 2.0 male pins/female housing assembly. If soldering, heatshrink is recommended to prevent shorts. (This is what this guide will show)
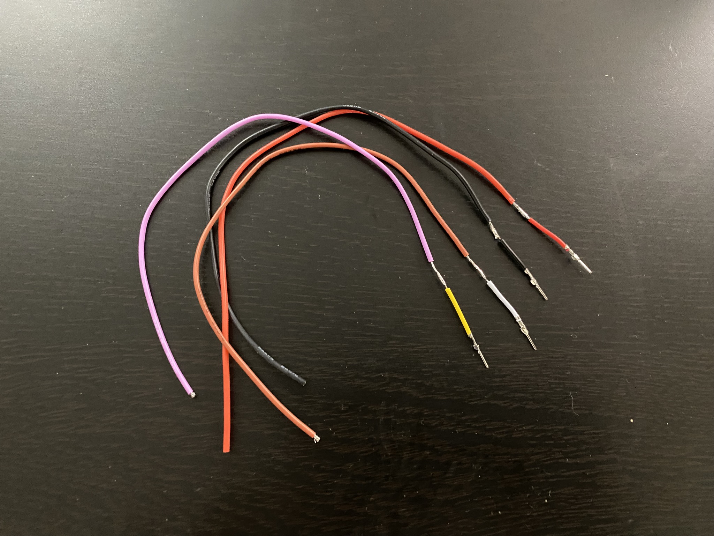
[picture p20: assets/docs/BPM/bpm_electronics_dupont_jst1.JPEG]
DuPont JST-PH harness Soldering

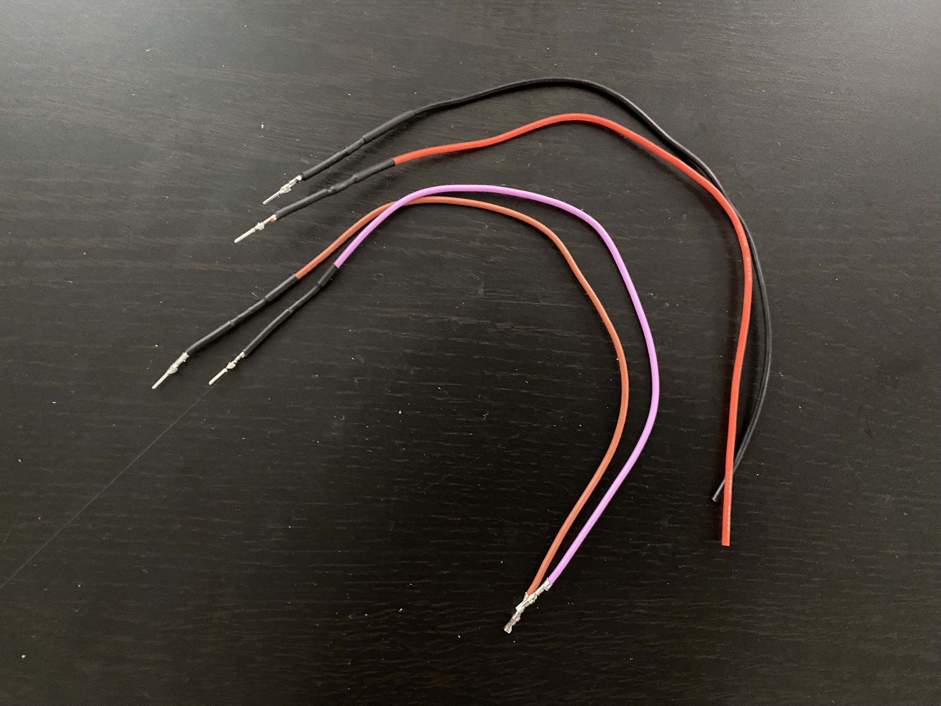
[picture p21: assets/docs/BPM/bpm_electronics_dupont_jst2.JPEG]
DuPont JST-PH harness Heatshrink

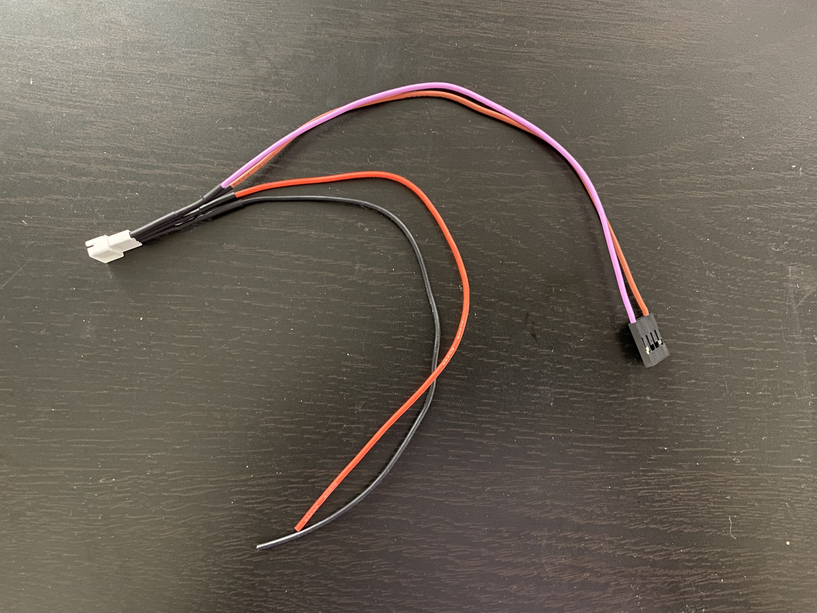
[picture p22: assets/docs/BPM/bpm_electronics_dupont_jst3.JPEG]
DuPont JST-PH harness


1.  Crimp 2 DuPont female pins to the red and black wires from step 11 and the red and black wires from step 2. Two wires into one DuPont pin is a tight fit, but it can be done with some patience.
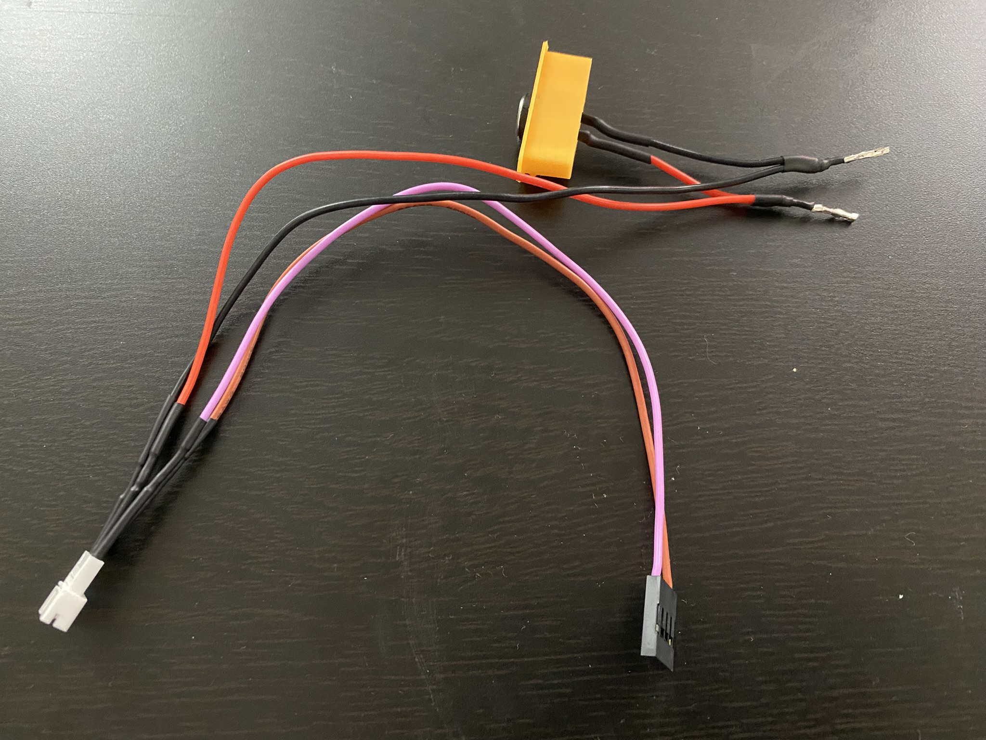
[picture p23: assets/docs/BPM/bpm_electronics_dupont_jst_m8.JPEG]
DuPont JST-PH M8 harness


1.  Insert the double-crimped red and black wires into a 4-pin DuPont connector housing.
    
1.  4 DuPont female pins to the 50mm red and black 24 AWG wires (both ends). Insert the crimped wires into a 4-pin DuPont connector housing and the other ends into the remaining slots of the DuPont connector housing of step 13. 
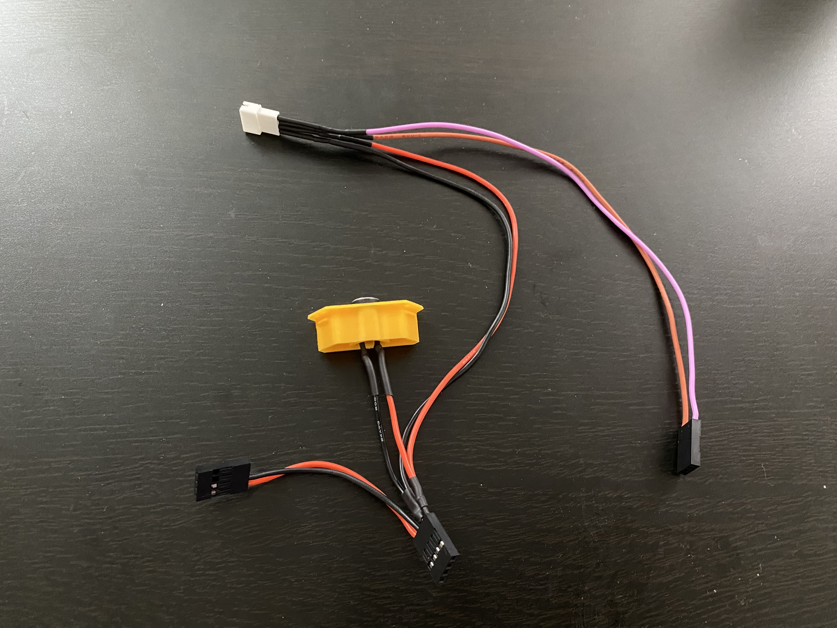
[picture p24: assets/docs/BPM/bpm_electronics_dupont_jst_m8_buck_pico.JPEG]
Dupont JST-PH M8 buck converter Pi Pico harness


[Next: Back Panel Mount (BPM) Flow Chamber Assembly >](BPM_Flow_Chamber_Assembly.md)

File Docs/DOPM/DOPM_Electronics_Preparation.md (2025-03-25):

# Direct On Panel Mount (DOPM) Smart Electronics Preparation

These are instructions for the StealthMax (300) Smart Direct On Panel Mount (DOPM).

## Parts Required

Printed parts:
- 1x [1.4a_CableEntryCap_M8Barrel.stl](/STLs/1_FlowChamber/1.4a_CableEntryCap_M8Barrel.stl)

Hardware:
- Raspberry Pi Pico W
- Female Dupont pins
- Male JST-PH 2.0 pins
- 1x M8 threaded DC connector
- 1x Matek Systems MBEC6S/MBEC2A
- 2x BME280
- 2x SGP40/SGP30
- 3x right angle 4-pin male header
- 1x right angle 5-pin male header
- 2x straight 4-pin male header
- 5x 4-pin female DuPont connector housing
- 1x 4-pin JST-PH 2.0 male pin/female connector housing

Tools:
- DuPont crimping tool
- JST crimping tool

## Direct On Panel Mount (DOPM) Smart Electronics Preparation

1. With the Raspberry Pi Pico W accessible, start by flashing the latest controller firmware on it according to the [Nevermore Controller Setup Guide](https://github.com/SanaaHamel/nevermore-controller#guide-setup). In short:
   - Download the latest Nevermore Controller uf2 binary.
   - Connect the Raspberry Pi Pico W via USB Micro to a computer while holding down the BOOTSEL button.
   - Copy the downloaded .uf2 binary to the RPI-RP2 drive.
     - The Raspberry Pi Pico W will automatically reboot afterward.
   - SSH into your printer's Klipper host (e.g. a regular Raspberry Pi).
   - Install the Nevermore Controller Klipper module.
     - Restart your Klipper host if you enabled Bluetooth during the installation process.
   - Add the [minimal example configuration](https://github.com/SanaaHamel/nevermore-controller#klipper-config-minimal) to your printer.cfg.
   - We'll add the Nevermore macros from the Nevermore Controller Setup Guide to the relevant print start/end macros, and calibrate the sensors at a later stage.

2. Remove the nut from the M8 threaded DC connector and solder 75mm red and black 24 AWG wires to it. Apply a small section of heat shrink tubing to both leads, then slide the cables through the [1.4a_CableEntryCap_M8Barrel.stl](/STLs/1_FlowChamber/1.4a_CableEntryCap_M8Barrel.stl) and thread in the M8 threaded DC connector securely.
M8 threaded DC connector soldered
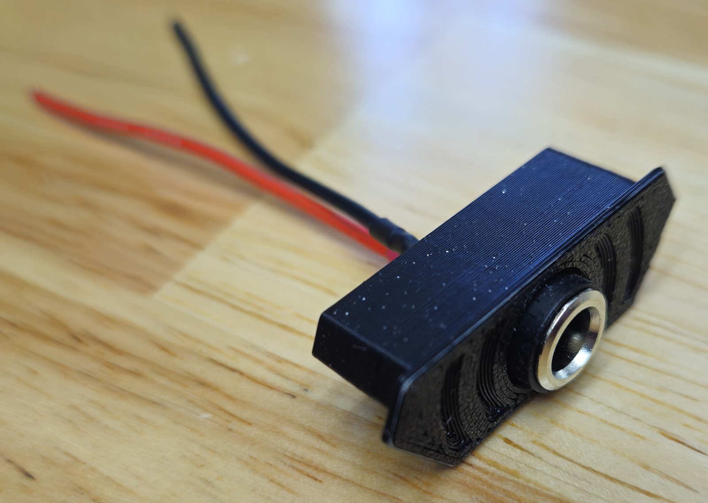
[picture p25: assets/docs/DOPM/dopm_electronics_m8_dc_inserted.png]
M8 threaded DC connector inserted


3. Solder a right angle 4-pin male header to the Matek Systems MBEC6S/MBEC2A buck converter.
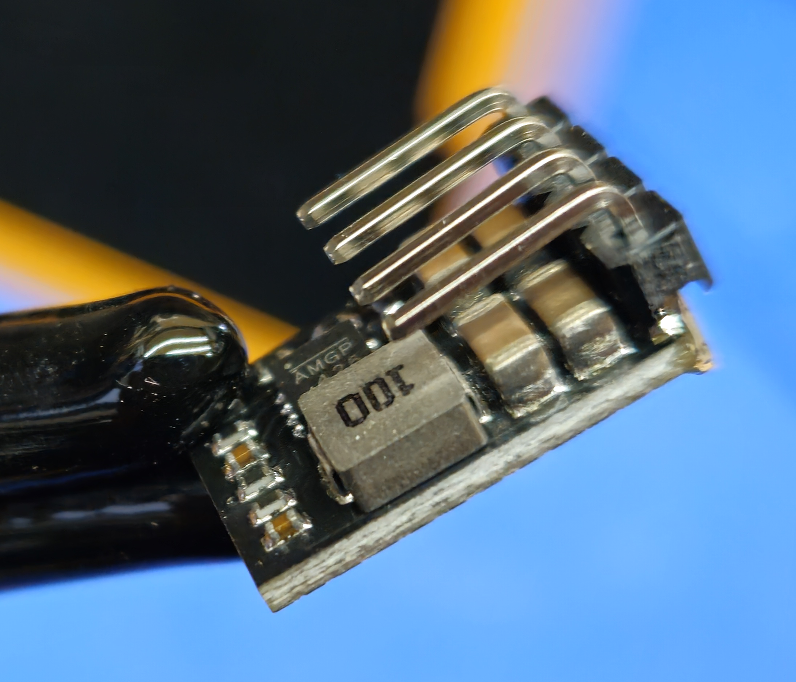
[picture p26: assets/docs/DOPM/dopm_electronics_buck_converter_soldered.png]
Matek Systems MBEC6S/MBEC2A buck converter soldered


4. Solder the straight 4-pin male header to each of the BME280 PCBs.
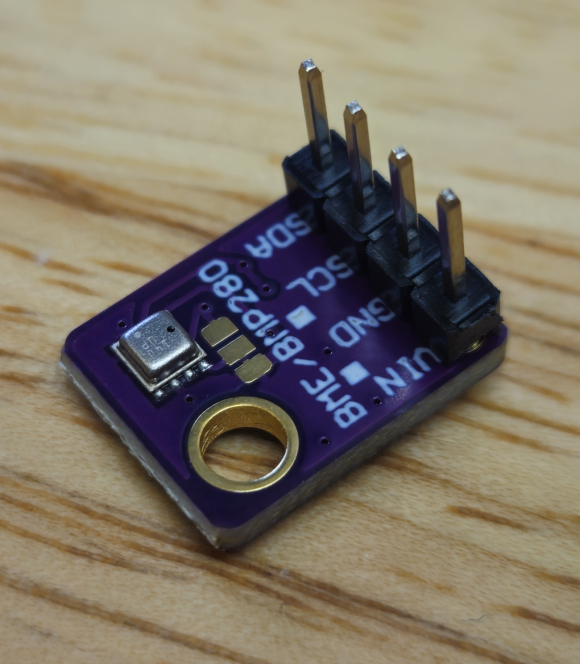
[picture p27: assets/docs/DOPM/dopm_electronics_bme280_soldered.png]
BME280 PCBs soldered


5. Add the SGP40/SGP30 PCBs on top of each of the pins soldered to the BME280 PCBs and solder it from the other side. Take extra care to not leave excess solder here, as it may interfere with the DuPont connector later.
SGP40 PCBs soldered
BME280 SGP40 pins clearance

6. Solder 2x right angle 4-pin male header and 1x right angle 5-pin male header to the Raspberry Pi Pico W.
Raspberry Pi Pico W soldered

7. Crimp 4 DuPont female pins to the 325mm yellow, pink, black, and green 26 AWG wires. Insert the crimped wires into a 4-pin DuPont connector housing.
Yellow/Pink/Black/Green DuPont connector

8. Crimp 4 DuPont female pins to the 300mm blue, gray, black, and green 26 AWG wires. Insert the crimped wires into a 4-pin DuPont connector housing.
Blue/Gray/Black/Green DuPont connector

9. Crimp 2 DuPont female pins to the other end of the blue and gray wires from step 7, and yellow and pink wires from step 8. Do not crimp the black and green wires yet on either cable harness.
Blue/Gray/Yellow/Pink DuPont pins

10. Crimp 2 DuPont female pins to the 100mm violet and brown 26 AWG wires.
11. Crimp 4 JST-PH 2.0 male pins to the 100mm violet and brown 26 AWG wires, and 200mm black and red 24 AWG wires. Insert the crimped violet and brown wires into a 4-pin DuPont connector housing, and the crimped violet, brown, red, and black wires into a 4-pin JST-PH 2.0 connector housing. 
    - If you do not have JST-PH 2.0 male pins/female housing, solder the violet, brown, red, and black wires directly to a JST-PH 2.0 male housing, or a pre-crimped JST-PH 2.0 male pins/female housing assembly.
DuPont JST-PH harness

12. Crimp 2 DuPont female pins to the red and black wires from step 11 and the red and black wires from step 2. Two wires into one DuPont pin is a tight fit, but it can be done with some patience.
DuPont JST-PH M8 harness

13. Insert the double-crimped red and black wires into a 4-pin DuPont connector housing.
DuPont JST-PH M8 buck converter harness
    
14. Crimp 4 DuPont female pins to the 50mm red and black 24 AWG wires (both ends). Insert the crimped wires into a 4-pin DuPont connector housing and the other ends into the remaining slots of the DuPont connector housing of step 13. 
Dupont JST-PH M8 buck converter Pi Pico harness

[Next: Direct On Panel Mount (DOPM) Flow Chamber Assembly >](DOPM_Flow_Chamber_Assembly.md)

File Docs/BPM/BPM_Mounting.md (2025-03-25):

# Back Panel Mount (BPM) Main Chamber Assembly Continued

These are instructions for the StealthMax (300) Smart Back Panel Mount (BPM). 

## Parts Required

Printed parts:
- 1x [Main Chamber Assembly](../../Docs/BPM/BPM_Main_Chamber_Assembly_Continued.md)
- 1x [M_0a.0_VoronExhaustFitting_BPM.stl](../../STLs/0_Mount/0a_BackPanelMount/StealthMax/M_0a.0_VoronExhaustFitting_BPM.stl)
- 1x [0a.1_BackPanelMount_BPM.stl](../../STLs/0_Mount/0a_BackPanelMount/0a.1_BackPanelMount_BPM.stl)
- 1x [0a.2_BackPanelMountCover_BPM.stl](../../STLs/0_Mount/0a_BackPanelMount/0a.2_BackPanelMountCover_BPM.stl)

Hardware:
- 2x M3x25 SHCS
- 7x M3x12 SHCS
- 2x M3 Hammerhead Nut (could sub M3 roll in)
- 4x M3x10 BHCS
- 2x M3x6 BHCS
- 2x M3x20 SHCS

## Back Panel Mount (BPM) Main Chamber Assembly Continued

1. Remove the carbon basket assembly from the the main chamber. You may also find it easier to remove the lid assembly as well.

1. Insert two M3x25 SHCS into the holes marked in the [main chamber assembly](../../Docs/BPM/BPM_Main_Chamber_Assembly_Continued.md). Thread them in so the tiniest bit is poking through the other side.
Main chamber attachment screws

1. Align the [M_0a.0_VoronExhaustFitting_BPM.stl](../../STLs/0_Mount/0a_BackPanelMount/StealthMax/M_0a.0_VoronExhaustFitting_BPM.stl)'s grooves on the [main chamber assembly](../../Docs/BPM/BPM_Main_Chamber_Assembly_Continued.md) and screw into place with 7x M3x12 SHCS. Screw the M3x25 BHCS from the previous step all the way through.
Main chamber exhaust fitting

1. Loosely screw on the M3 hammerhead nuts to the exposed end of the M3x25 SHCS.
Main chamber mounting nuts

1. Place the [main chamber assembly](../../Docs/BPM/BPM_Main_Chamber_Assembly_Continued.md) on the back rear extrusion of the Voron 2.4. The [M_0a.0_VoronExhaustFitting_BPM.stl](../../STLs/0_Mount/0a_BackPanelMount/StealthMax/M_0a.0_VoronExhaustFitting_BPM.stl) should fit cleanly in the hole in rear panel. Make sure the the hammerhead nuts are inside the extrusion and screw the M3x25 SHCS into place. The [main chamber assembly](../../Docs/BPM/BPM_Main_Chamber_Assembly_Continued.md) should now be attached to the back extrusion.
Main chamber mounted outside view
Main chamber mounted inside view

1. Attach the [0a.1_BackPanelMount_BPM.stl](../../STLs/0_Mount/0a_BackPanelMount/0a.1_BackPanelMount_BPM.stl) to the [M_0a.0_VoronExhaustFitting_BPM.stl](../../STLs/0_Mount/0a_BackPanelMount/StealthMax/M_0a.0_VoronExhaustFitting_BPM.stl) with 4 M3x10 BHCS as shown in the picture.
Back Panel Mount M3x10

1. Add two M3x6 BHCS to hold the [0a.1_BackPanelMount_BPM.stl](../../STLs/0_Mount/0a_BackPanelMount/0a.1_BackPanelMount_BPM.stl) to the [M_0a.0_VoronExhaustFitting_BPM.stl](../../STLs/0_Mount/0a_BackPanelMount/StealthMax/M_0a.0_VoronExhaustFitting_BPM.stl).
Back Panel Mount M3x6

1. Route your PTFE tubing for the filament path through the PC4-M10 fitting in the [main chamber assembly](../../Docs/BPM/BPM_Main_Chamber_Assembly_Continued.md) to your desired length to reach the toolhead. This should be one piece since the fitting only acts as a stopper preventing the tube from coming loose. Make sure this goes through the little slot in the [0a.1_BackPanelMount_BPM.stl](../../STLs/0_Mount/0a_BackPanelMount/0a.1_BackPanelMount_BPM.stl).
PTFE routing through Stealthmax

1. Secure the [0a.2_BackPanelMountCover_BPM.stl](../../STLs/0_Mount/0a_BackPanelMount/0a.2_BackPanelMountCover_BPM.stl) with 2 M3x20 SHCS.
Back panel mount cover mounting

1. You're done! Now is a good time to fill up your carbon basket and [calibrate your sensors](https://github.com/SanaaHamel/nevermore-controller/blob/main/doc/voc.adoc#baseline-calibration).

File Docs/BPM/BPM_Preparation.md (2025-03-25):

# Back Panel Mount (BPM) Preparation

These are instructions for the StealthMax (300) Back Panel Mount (BPM). I would highly reccomend reading through the DOPM documentation for more pictures as a majority of the assembly will be similar between the two.

## Support removal

Start by removing the built-in support material on these parts (indicated by green color). 

### Main Chamber ([M_2.0_MainChamber.stl](../../STLs/2_MainChamber/StealthMax/M_2.0_MainChamber.stl))
BPM Main Chamber Supports

### Lid Frame ([M_3.0_LidFrame.stl](../../STLs/3_Lid/StealthMax/M_3.0_LidFrame.stl))
BPM Lid Frame Supports

### Flow Chamber ([M_1a.0_FlowChamber_BPM.stl](../../STLs/1_FlowChamber/1a_BackPanelMount/StealthMax/M_1a.0_FlowChamber_BPM.stl))
BPM Lid Frame Supports

## Heat-Set Inserts

There are 28 heat-set inserts in total to be inserted on these parts (indicated by the blue circles).

### Lid Front Hinge x2 ([3.2_LidFrontHinge.stl](../../STLs/3_Lid/3.2_LidFrontHinge.stl))
BPM Lid Front Hinge Heat-Set Inserts

### Voron Exhaust Fitting x2 ([M_0a.0_VoronExhaustFitting_BPM.stl](../../STLs/0_Mount/0a_BackPanelMount/StealthMax/M_0a.0_VoronExhaustFitting_BPM.stl))
BPM Removable Air Duct Heat-Set Insert

### Flow Chamber x16 ([M_1a.0_FlowChamber_BPM.stl](../../STLs/1_FlowChamber/1a_BackPanelMount/StealthMax/M_1a.0_FlowChamber_BPM.stl))
BPM Flow Chamber Heat-Set Inserts

### Main Chamber x6 ([M_2.0_MainChamber.stl](../../STLs/2_MainChamber/StealthMax/M_2.0_MainChamber.stl))
BPM Main Chamber Heat-Set Inserts

### Carbon Basket x2 ([M_2.1_CarbonBasket.stl](../../STLs/2_MainChamber/StealthMax/M_2.1_CarbonBasket.stl))
BPM Carbon Basket Heat-Set Inserts

[Next: Lid Assembly >](Lid_Assembly.md)

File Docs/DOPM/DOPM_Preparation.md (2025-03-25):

# Direct On Panel Mount (DOPM) Preparation

These are instructions for the StealthMax (300) Direct On Panel Mount (DOPM).

## Support removal

Start by removing the built-in support material on these parts (indicated by green color). 

**IMPORTANT NOTE:** Do not remove the five cross pieces on [M_1b.0_FlowChamber_DOPM.stl](/STLs/1_FlowChamber/1b_DirectOnPanelMount/StealthMax/M_1b.0_FlowChamber_DOPM.stl) in the center of each 40mm hole until you have drilled the corresponding holes on your panel of choice. Refer to the [Direct On Panel Mount instructions](../../assets/_unsorted/Direct-On-Panel_Mount/README.md) for more information.

### Main Chamber ([M_2.0_MainChamber.stl](/STLs/2_MainChamber/StealthMax/M_2.0_MainChamber.stl))
DOPM Main Chamber Supports

### Removable Air Duct ([M_1b.1_RemovableAirDuct_DOPM.stl](/STLs/1_FlowChamber/1b_DirectOnPanelMount/StealthMax/M_1b.1_RemovableAirDuct_DOPM.stl))
DOPM Removable Air Duct Supports

### Lid Frame ([M_3.0_LidFrame.stl](/STLs/3_Lid/StealthMax/M_3.0_LidFrame.stl))
DOPM Lid Frame Supports

### Flow Chamber ([M_1b.0_FlowChamber_DOPM.stl](/STLs/1_FlowChamber/1b_DirectOnPanelMount/StealthMax/M_1b.0_FlowChamber_DOPM.stl))

**IMPORTANT NOTE:** Do not remove the five cross pieces on [M_1b.0_FlowChamber_DOPM.stl](/STLs/1_FlowChamber/1b_DirectOnPanelMount/StealthMax/M_1b.0_FlowChamber_DOPM.stl) in the center of each 40mm hole until you have drilled the corresponding holes on your panel of choice. Refer to the [Direct On Panel Mount instructions](../../assets/_unsorted/Direct-On-Panel_Mount/README.md) for more information.

DOPM Lid Frame Supports

## Heat-Set Inserts

There are 26 heat-set inserts in total to be inserted on these parts (indicated by the red circles).

### Lid Front Hinge x2 ([3.2_LidFrontHinge.stl](/STLs/3_Lid/3.2_LidFrontHinge.stl))
DOPM Lid Front Hinge Heat-Set Inserts

### Removable Air Duct x1 ([M_1b.1_RemovableAirDuct_DOPM.stl](/STLs/1_FlowChamber/1b_DirectOnPanelMount/StealthMax/M_1b.1_RemovableAirDuct_DOPM.stl))
DOPM Removable Air Duct Heat-Set Insert

### Chamber Exhaust Connection x2 ([M_1b.1_RemovableAirDuct_DOPM.stl](/STLs/1_FlowChamber/1b_DirectOnPanelMount/StealthMax/M_1b.1_RemovableAirDuct_DOPM.stl))
DOPM Chamber Exhaust Connection Heat-Set Inserts

### Flow Chamber x13 ([M_1b.0_FlowChamber_DOPM.stl](/STLs/1_FlowChamber/1b_DirectOnPanelMount/StealthMax/M_1b.0_FlowChamber_DOPM.stl))
DOPM Flow Chamber Heat-Set Inserts
DOPM Flow Chamber Heat-Set Inserts

### Main Chamber x6 ([M_2.0_MainChamber.stl](/STLs/2_MainChamber/StealthMax/M_2.0_MainChamber.stl))
DOPM Main Chamber Heat-Set Inserts
DOPM Main Chamber Heat-Set Inserts

### Carbon Basket x2 ([M_2.1_CarbonBasket.stl](/STLs/2_MainChamber/StealthMax/M_2.1_CarbonBasket.stl))
DOPM Carbon Basket Heat-Set Inserts

[Next: Lid Assembly >](Lid_Assembly.md)

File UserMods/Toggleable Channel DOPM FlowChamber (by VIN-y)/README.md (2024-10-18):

# Video

Check out this Short to see it in action: [YouTube Short](https://www.youtube.com/shorts/8Elc7c05F7s) 

# Images













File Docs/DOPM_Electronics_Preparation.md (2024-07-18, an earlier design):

# Direct On Panel Mount (DOPM) Smart Electronics Preparation

These are instructions for the StealthMax (300) Smart Direct On Panel Mount (DOPM).

## Parts Required

Printed parts:
- 1x [1.4a_CableEntryCap_M8Barrel.stl](/STLs/1_FlowChamber/1.4a_CableEntryCap_M8Barrel.stl)

Hardware:
- Raspberry Pi Pico W
- Female Dupont pins
- Male JST-PH 2.0 pins
- 1x M8 threaded DC connector
- 1x Matek Systems MBEC6S/MBEC2A
- 2x BME280
- 2x SGP40/SGP30
- 3x right angle 4-pin male header
- 1x right angle 5-pin male header
- 2x straight 4-pin male header
- 5x 4-pin female DuPont connector housing
- 1x 4-pin JST-PH 2.0 male pin/female connector housing

Tools:
- DuPont crimping tool
- JST crimping tool

## Direct On Panel Mount (DOPM) Smart Electronics Preparation

1. With the Raspberry Pi Pico W accessible, start by flashing the latest controller firmware on it according to the [Nevermore Controller Setup Guide](https://github.com/SanaaHamel/nevermore-controller#guide-setup). In short:
   - Download the latest Nevermore Controller uf2 binary.
   - Connect the Raspberry Pi Pico W via USB Micro to a computer while holding down the BOOTSEL button.
   - Copy the downloaded .uf2 binary to the RPI-RP2 drive.
     - The Raspberry Pi Pico W will automatically reboot afterward.
   - SSH into your printer's Klipper host (e.g. a regular Raspberry Pi).
   - Install the Nevermore Controller Klipper module.
     - Restart your Klipper host if you enabled Bluetooth during the installation process.
   - Add the [minimal example configuration](https://github.com/SanaaHamel/nevermore-controller#klipper-config-minimal) to your printer.cfg.
   - We'll add the Nevermore macros from the Nevermore Controller Setup Guide to the relevant print start/end macros, and calibrate the sensors at a later stage.

2. Remove the nut from the M8 threaded DC connector and solder 75mm red and black 24 AWG wires to it. Apply a small section of heat shrink tubing to both leads, then slide the cables through the [1.4a_CableEntryCap_M8Barrel.stl](/STLs/1_FlowChamber/1.4a_CableEntryCap_M8Barrel.stl) and thread in the M8 threaded DC connector securely.
M8 threaded DC connector soldered
M8 threaded DC connector inserted

3. Solder a right angle 4-pin male header to the Matek Systems MBEC6S/MBEC2A buck converter.
Matek Systems MBEC6S/MBEC2A buck converter soldered

4. Solder the straight 4-pin male header to each of the BME280 PCBs.
BME280 PCBs soldered

5. Add the SGP40/SGP30 PCBs on top of each of the pins soldered to the BME280 PCBs and solder it from the other side. Take extra care to not leave excess solder here, as it may interfere with the DuPont connector later.
SGP40 PCBs soldered
BME280 SGP40 pins clearance

6. Solder 2x right angle 4-pin male header and 1x right angle 5-pin male header to the Raspberry Pi Pico W.
Raspberry Pi Pico W soldered

7. Crimp 4 DuPont female pins to the 325mm yellow, pink, black, and green 26 AWG wires. Insert the crimped wires into a 4-pin DuPont connector housing.
Yellow/Pink/Black/Green DuPont connector

8. Crimp 4 DuPont female pins to the 300mm blue, gray, black, and green 26 AWG wires. Insert the crimped wires into a 4-pin DuPont connector housing.
Blue/Gray/Black/Green DuPont connector

9. Crimp 2 DuPont female pins to the other end of the blue and gray wires from step 7, and yellow and pink wires from step 8. Do not crimp the black and green wires yet on either cable harness.
Blue/Gray/Yellow/Pink DuPont pins

10. Crimp 2 DuPont female pins to the 100mm violet and brown 26 AWG wires.
11. Crimp 4 JST-PH 2.0 male pins to the 100mm violet and brown 26 AWG wires, and 200mm black and red 24 AWG wires. Insert the crimped violet and brown wires into a 4-pin DuPont connector housing, and the crimped violet, brown, red, and black wires into a 4-pin JST-PH 2.0 connector housing. 
    - If you do not have JST-PH 2.0 male pins/female housing, solder the violet, brown, red, and black wires directly to a JST-PH 2.0 male housing, or a pre-crimped JST-PH 2.0 male pins/female housing assembly.
DuPont JST-PH harness

12. Crimp 2 DuPont female pins to the red and black wires from step 11 and the red and black wires from step 2. Two wires into one DuPont pin is a tight fit, but it can be done with some patience.
DuPont JST-PH M8 harness

13. Insert the double-crimped red and black wires into a 4-pin DuPont connector housing.
DuPont JST-PH M8 buck converter harness
    
14. Crimp 4 DuPont female pins to the 50mm red and black 24 AWG wires (both ends). Insert the crimped wires into a 4-pin DuPont connector housing and the other ends into the remaining slots of the DuPont connector housing of step 13. 
Dupont JST-PH M8 buck converter Pi Pico harness

[Next: Direct On Panel Mount (DOPM) Flow Chamber Assembly >](DOPM_Flow_Chamber_Assembly.md)

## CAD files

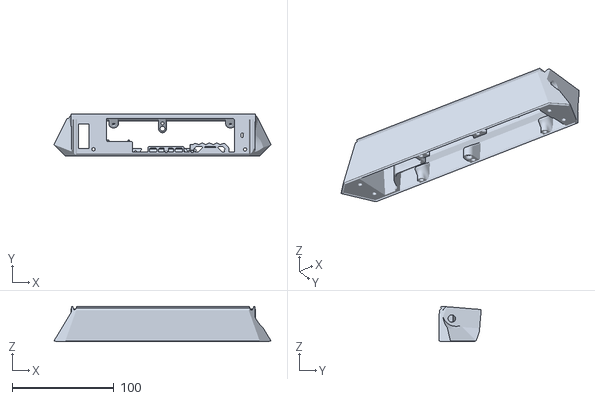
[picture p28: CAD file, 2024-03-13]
STLs/4_AddOns/4.1_PCOFiltration/4.1.1_PCOChamberMain.stl
213.5 x 41.7 x 34.9

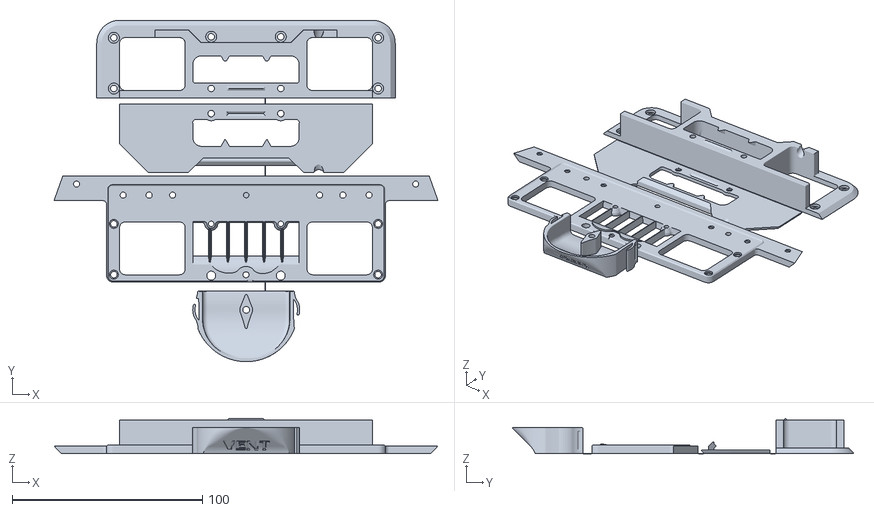
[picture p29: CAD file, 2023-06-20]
STL/4-Voron_Chamber_Connection_and_Exhaust.stl
202.0 x 179.5 x 18.5

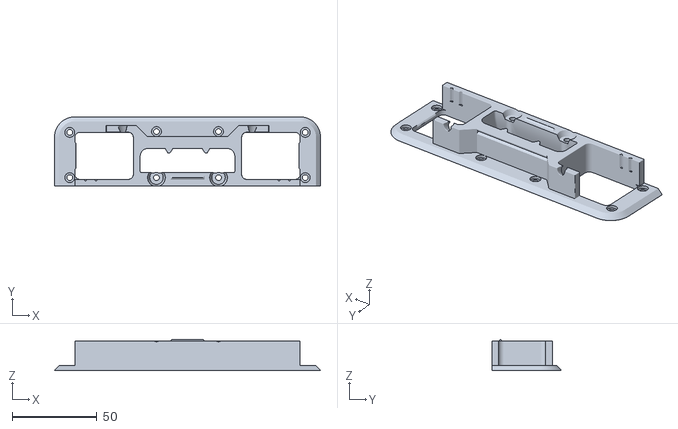
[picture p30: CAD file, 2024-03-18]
STLs/0_Mount/0a_BackPanelMount/0a.1_BackPanelMount_BPM.stl
157.0 x 40.9 x 18.5

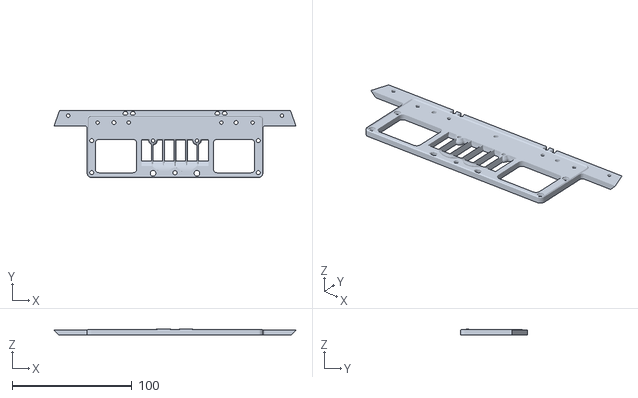
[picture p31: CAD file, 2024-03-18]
STLs/0_Mount/0a_BackPanelMount/StealthMax/M_0a.0_VoronExhaustFitting_BPM.stl
202.0 x 55.8 x 5.00

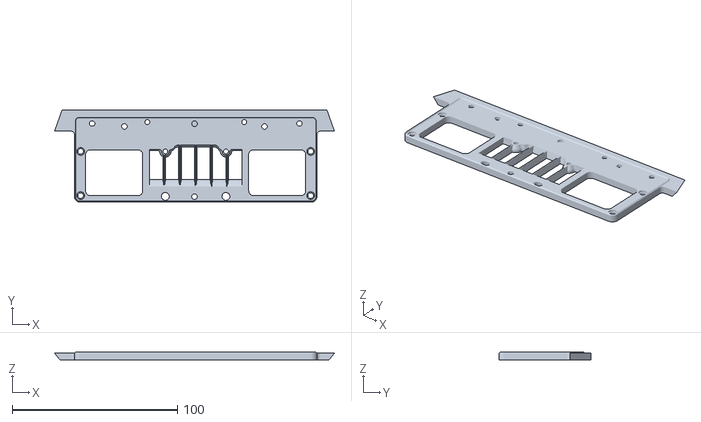
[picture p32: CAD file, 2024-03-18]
STLs/0_Mount/0a_BackPanelMount/StealthMax_S/S_0a.0_VoronExhaustFitting_BPM.stl
169.2 x 55.8 x 4.62

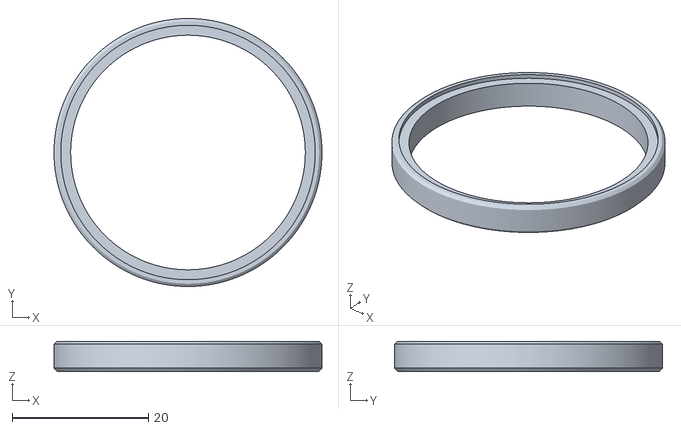
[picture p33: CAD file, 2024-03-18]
STLs/0_Mount/0b_DirectOnPanelMount/0b.2_ExhaustPipe_DOPM.stl
39.3 x 39.3 x 4.40

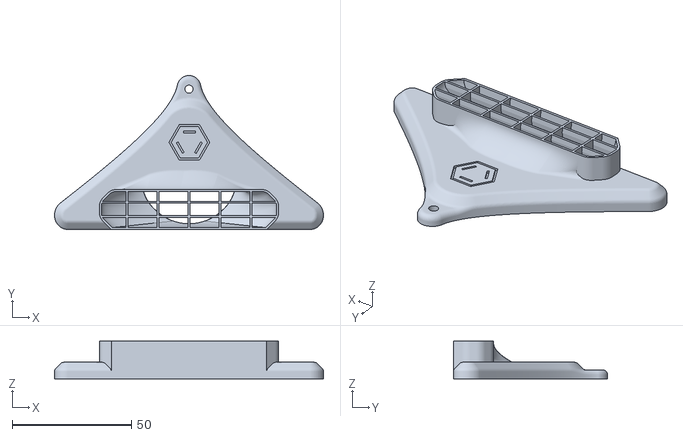
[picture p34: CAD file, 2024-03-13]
STLs/0_Mount/0b_DirectOnPanelMount/StealthMax/M_0b.0_ChamberExhaustConnection_DOPM.stl
112.6 x 64.4 x 15.7

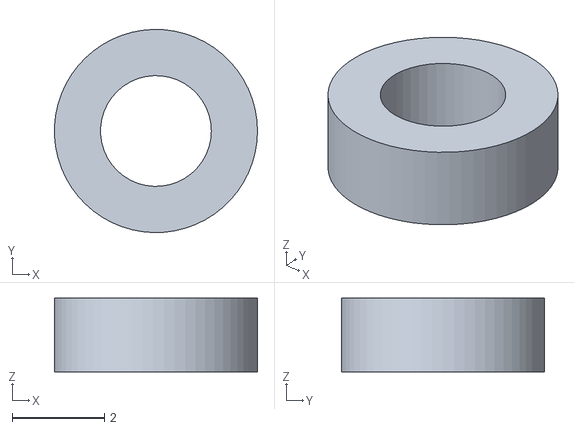
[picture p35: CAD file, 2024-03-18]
STLs/1_FlowChamber/1.6_PCBSpacer.stl
4.40 x 4.40 x 1.60

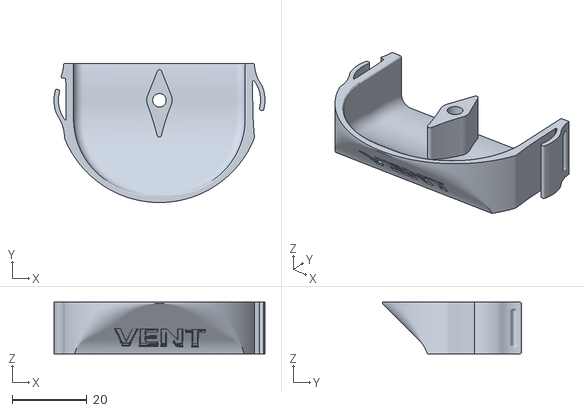
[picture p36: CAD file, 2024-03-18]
STLs/1_FlowChamber/1a_BackPanelMount/StealthMax/M_1a.1_AirExhaustWheel_BPM.stl
56.3 x 37.1 x 13.8

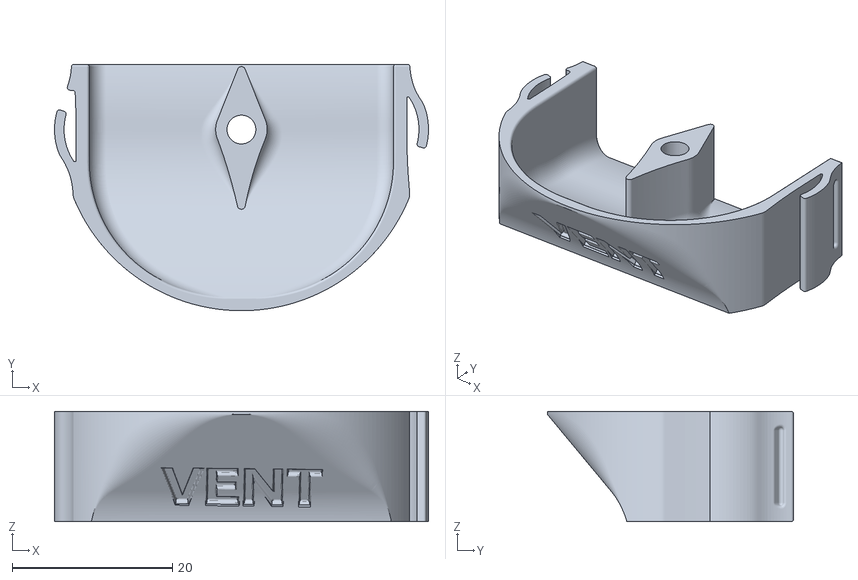
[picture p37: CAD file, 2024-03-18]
STLs/1_FlowChamber/1a_BackPanelMount/StealthMax_S/S_1a.1_AirExhaustWheel_BPM.stl
46.7 x 30.8 x 13.8

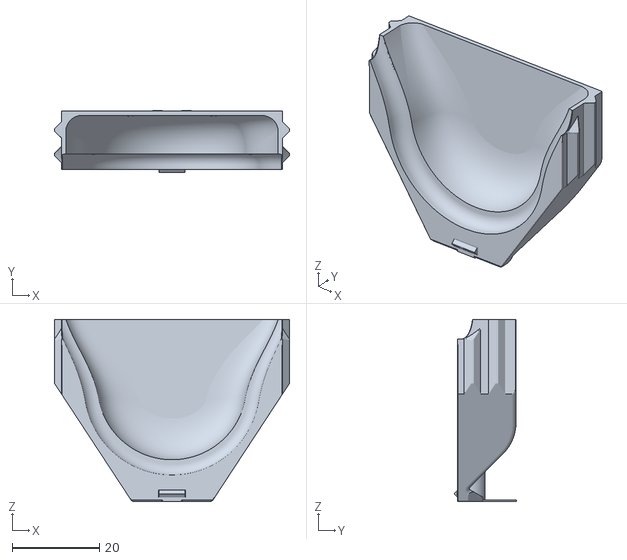
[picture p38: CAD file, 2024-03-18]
STLs/1_FlowChamber/1b_DirectOnPanelMount/StealthMax/M_1b.1_RemovableAirDuct_DOPM.stl
54.0 x 14.3 x 41.9

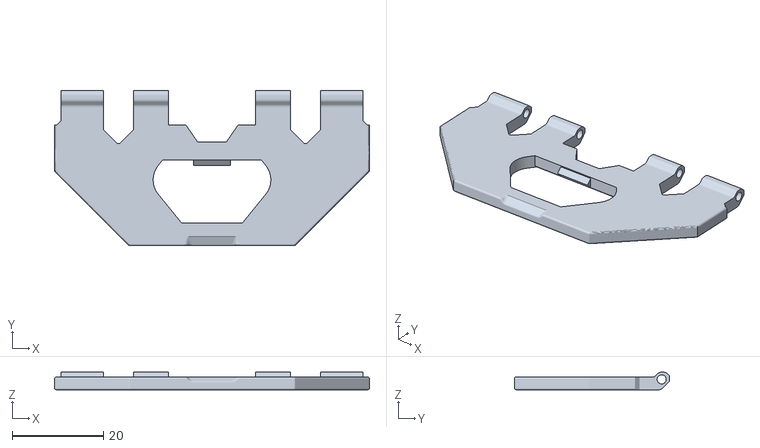
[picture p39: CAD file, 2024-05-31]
STLs/2_MainChamber/2.9_CarbonBasketLidHandle_Spare.stl
69.0 x 34.0 x 3.85

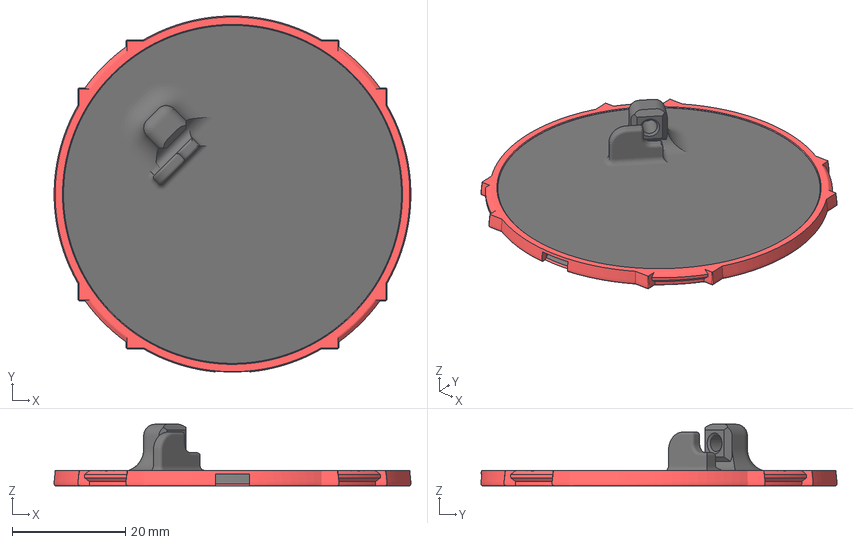
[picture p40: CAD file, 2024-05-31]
STLs/2_MainChamber/StealthMax/M_2.5b_LogoCap_MMU.3mf
63.1 x 63.0 x 10.9 mm

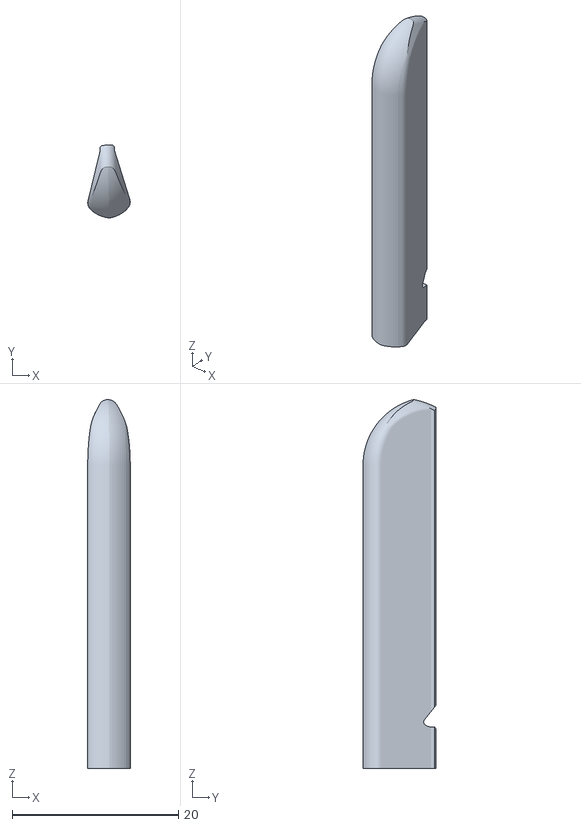
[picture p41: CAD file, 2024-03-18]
STLs/2_MainChamber/StealthMax_S/S_2.4_HEPASeaterStick.stl
5.12 x 8.77 x 44.3

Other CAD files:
STLs/1_FlowChamber/1b_DirectOnPanelMount/StealthMax_S/S_1b.0_FlowChamber_DOPM.stl
STLs/3_Lid/3.3_LidLatch.stl
STLs/3_Lid/StealthMax/M_3.0_LidFrame.stl
STLs/3_Lid/StealthMax_S/S_3.0_LidFrame.stl
STLs/0_Mount/0a_BackPanelMount/0a.2_BackPanelMountCover_BPM.stl
STLs/1_FlowChamber/1.2_AirExhaustSlider.stl
STLs/1_FlowChamber/1.3a_BowdenCap_Closed.stl
STLs/1_FlowChamber/1.3b_BowdenCap_Open.stl
STLs/1_FlowChamber/1.4a_CableEntryCap_M8Barrel.stl
STLs/1_FlowChamber/1.4b_CableEntryCap_MicroFit3.stl
STLs/1_FlowChamber/1.4c_CableEntryCap_Closed.stl
STLs/1_FlowChamber/1.5_FanWirePin_Spare.stl
STLs/1_FlowChamber/1b_DirectOnPanelMount/StealthMax_S/S_1b.1_RemovableAirDuct_DOPM.stl
STLs/2_MainChamber/StealthMax/M_2.2a_CarbonBasketLid.stl
STLs/2_MainChamber/StealthMax/M_2.2b_CarbonBasketLid_noHandles.stl
STLs/2_MainChamber/StealthMax/M_2.2c_CarbonBasketLid_MMU.3mf
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

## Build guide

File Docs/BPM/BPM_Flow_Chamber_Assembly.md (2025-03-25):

# Back Panel Mount (BPM) Flow Chamber Assembly

These are instructions for the StealthMax (300) Smart Back Panel Mount (BPM). The majority of this part is borrowed from the DOPM documentation but with replaced images for continuity.

## Parts Required

Printed parts:
- 1x [M_1a.0_FlowChamber_BPM.stl](../../STLs/1_FlowChamber/1a_BackPanelMount/StealthMax/M_1a.0_FlowChamber_BPM.stl)
- 4x [1.6_PCBSpacer.stl](../../STLs/1_FlowChamber/1.6_PCBSpacer.stl)
- 1x [M_1a.1_AirExhaustWheel_BPM.stl](../../STLs/1_FlowChamber/1a_BackPanelMount/StealthMax/M_1a.1_AirExhaustWheel_BPM.stl)
- 1x [1.2_AirExhaustSlider.stl](../../STLs/1_FlowChamber/1.2_AirExhaustSlider.stl)
- Optional: 1x [1.5_FanWirePin_Spare.stl](../../STLs/1_FlowChamber/1.5_FanWirePin_Spare.stl)

Hardware:
- Raspberry Pi Pico W
- Female Dupont pins
- 1x 5-pin female DuPont connector housing
- 1x Delta BFB0712HF (fan)
- 1x M3x10 (or M3x8) BHCS
- 3x M2x4 FHCS

## Back Panel Mount (BPM) Smart Electronics

1. Route the power harness from preparation step 14 through the [M_1a.0_FlowChamber_BPM.stl](../../STLs/1_FlowChamber/1a_BackPanelMount/StealthMax/M_1a.0_FlowChamber_BPM.stl) as follows, and connect the Matek Systems MBEC6S/MBEC2A buck converter. Double check the buck wiring as doing incorrectly could fry the pico.
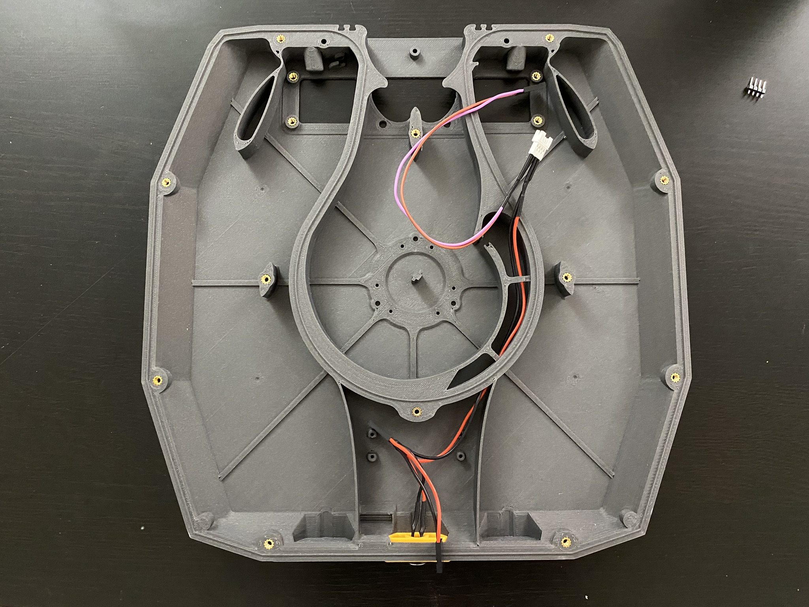
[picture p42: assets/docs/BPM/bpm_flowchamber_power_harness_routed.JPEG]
BPM power harness routed


1. Push in the [1.4a_CableEntryCap_M8Barrel.stl](../../STLs/1_FlowChamber/1.4a_CableEntryCap_M8Barrel.stl) into the slot.
   - If the cable entry cap doesn't push in easily, carefully shave off 0.3-0.5mm of plastic from the [M_1a.0_FlowChamber_BPM.stl](../../STLs/1_FlowChamber/1a_BackPanelMount/StealthMax/M_1a.0_FlowChamber_BPM.stl) on both sides of the inside of the hole.
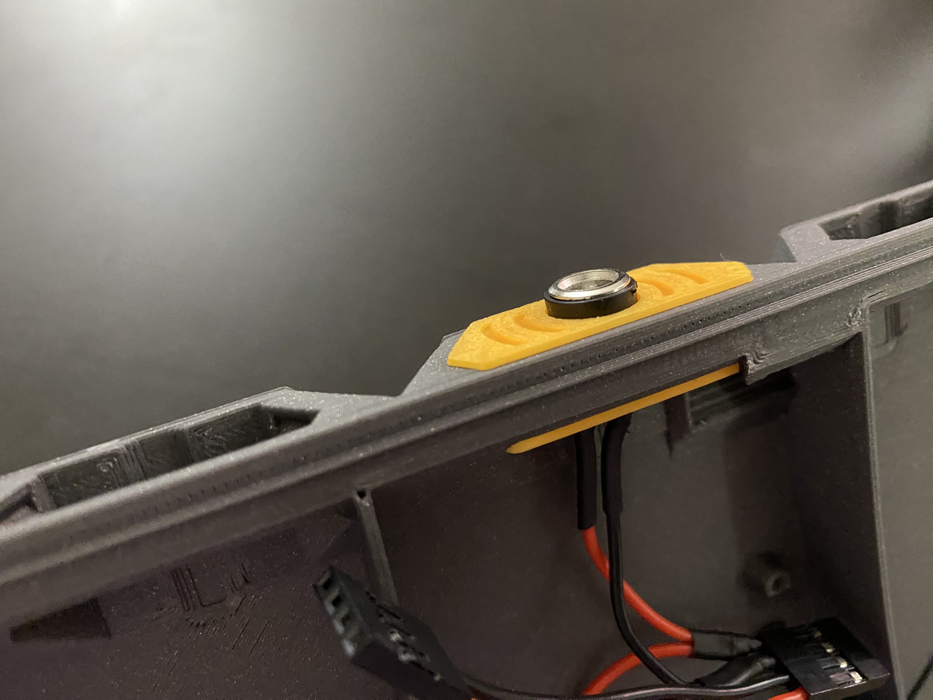
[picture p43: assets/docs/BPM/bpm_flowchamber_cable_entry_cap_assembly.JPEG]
BPM cable entry cap assembly


1. Route the sensor-in harness from [electronics preparation](../../Docs/BPM/BPM_Electronics_Preparation.md) step 7 through the [M_1a.0_FlowChamber_BPM.stl](../../STLs/1_FlowChamber/1a_BackPanelMount/StealthMax/M_1a.0_FlowChamber_BPM.stl) as follows.
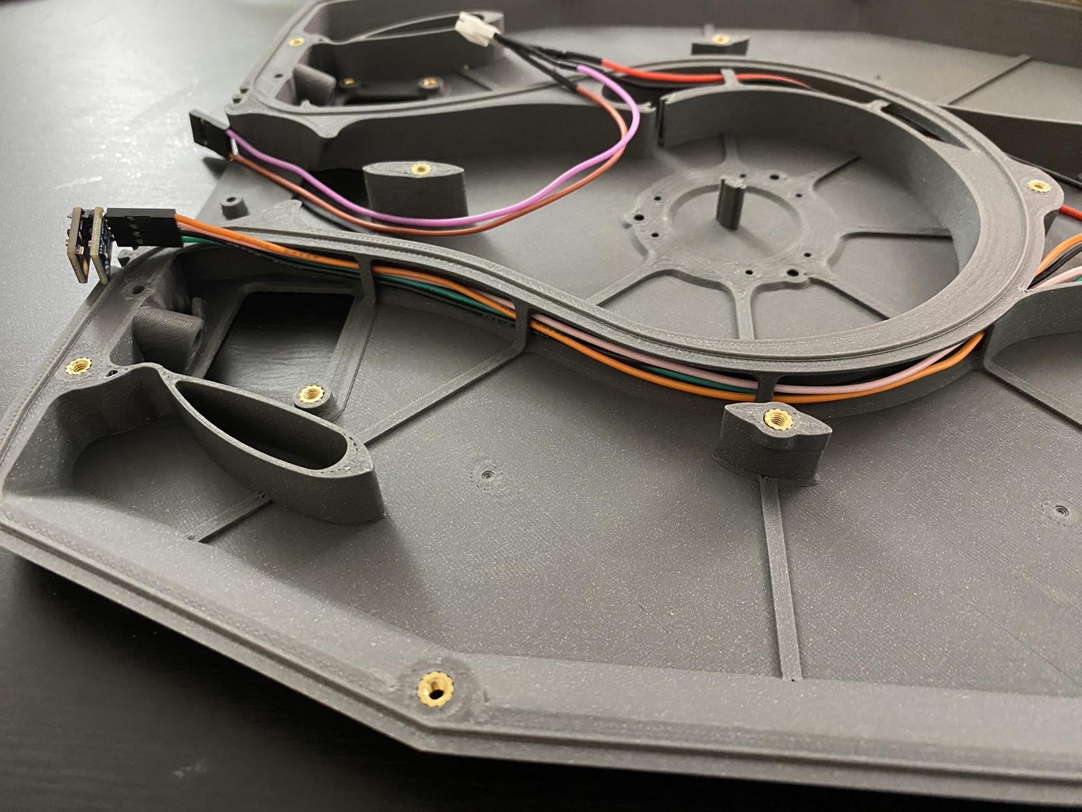
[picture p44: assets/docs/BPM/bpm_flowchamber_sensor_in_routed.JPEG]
BPM sensor-in harness routed


1. Route the sensor-out harness from [electronics preparation](../../Docs/BPM/BPM_Electronics_Preparation.md) step 8 through the [M_1a.0_FlowChamber_BPM.stl](../../STLs/1_FlowChamber/1a_BackPanelMount/StealthMax/M_1a.0_FlowChamber_BPM.stl) as follows.
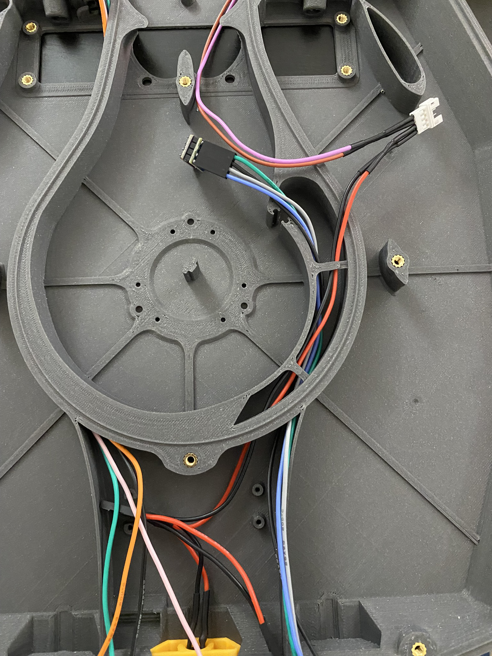
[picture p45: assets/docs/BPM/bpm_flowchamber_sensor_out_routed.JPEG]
BPM sensor-out harness routed


1. Crimp 2 DuPont female pins to the remaining uncrimped black and green wires from step 9. Two wires into one DuPont pin is a tight fit, but it can be done with some patience.
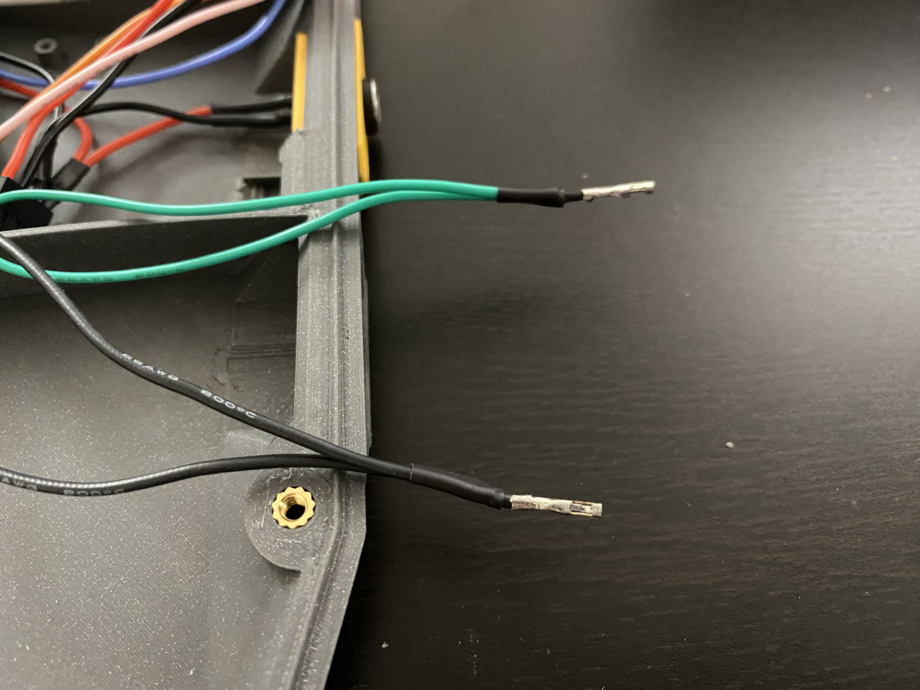
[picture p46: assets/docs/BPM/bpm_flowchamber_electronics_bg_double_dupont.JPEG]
BPM Black/Green DuPont connector


1. Insert the double-crimped green wires into the 4-pin DuPont connector from [electronics preparation](../../Docs/BPM/BPM_Electronics_Preparation.md) step 14, and the double-crimped black wires into a 5-pin DuPont connector, together with the pink, yellow, gray, and blue wires of the sensor-in and sensor-out harnesses.
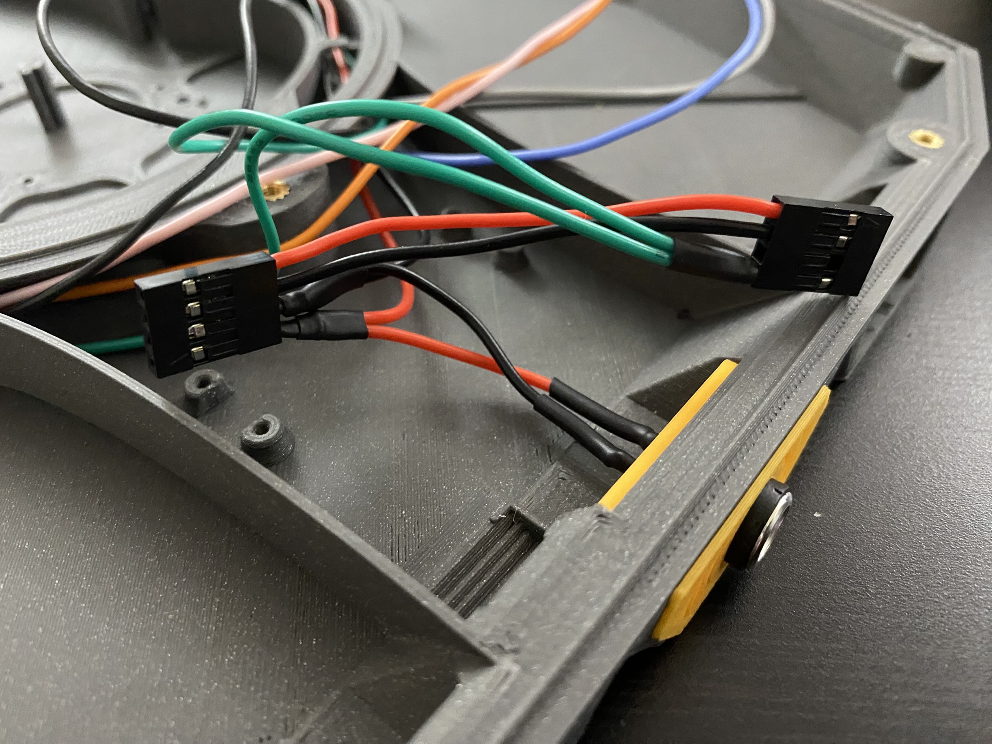
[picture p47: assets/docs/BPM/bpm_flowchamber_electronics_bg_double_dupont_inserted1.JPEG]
BPM Black/Green DuPont connector

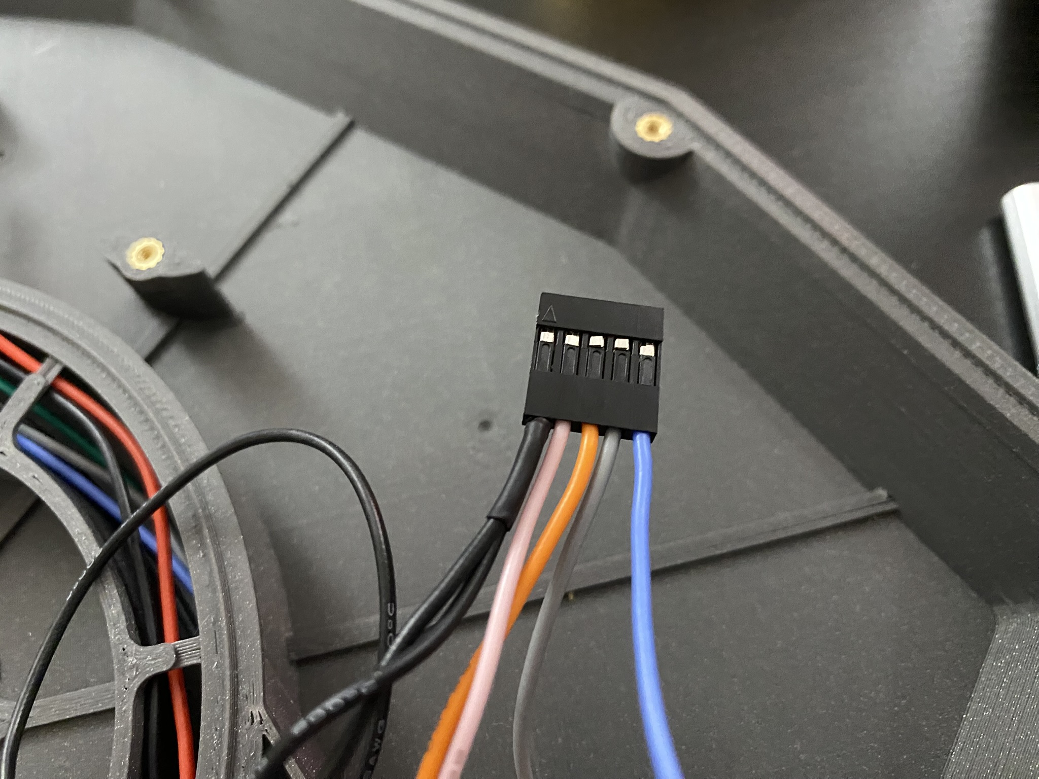
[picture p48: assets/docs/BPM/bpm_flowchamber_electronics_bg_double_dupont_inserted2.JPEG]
BPM Black/Green DuPont connector


1. Connect the 2 4-pin and single 5-pin DuPont connector to the Raspberry Pi Pico W and route the cables underneath the Pico W while fastening the Pico W to the [M_1a.0_FlowChamber_BPM.stl](../../STLs/1_FlowChamber/1a_BackPanelMount/StealthMax/M_1a.0_FlowChamber_BPM.stl) using 4 [1.6_PCBSpacer.stl](../../STLs/1_FlowChamber/1.6_PCBSpacer.stl) and 4 M2x6 self-tapping screws. Do not overtighten, as you are threading directly into plastic.
   - It helps to tape down the wires so they all sit flush underneath the Pico W. Fastening the Pico W can be a bit finicky, so be patient.
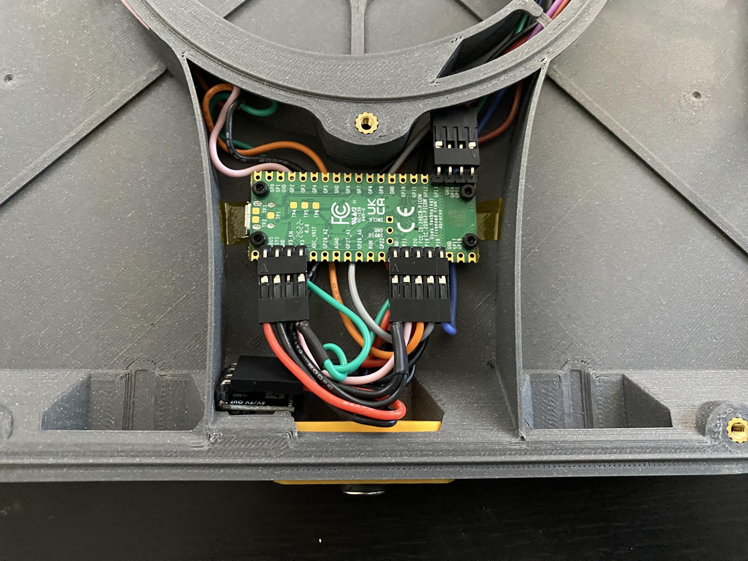
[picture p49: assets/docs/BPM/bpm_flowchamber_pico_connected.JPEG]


1. Fasten the sensor-in PCBs to the [M_1a.0_FlowChamber_BPM.stl](../../STLs/1_FlowChamber/1a_BackPanelMount/StealthMax/M_1a.0_FlowChamber_BPM.stl) using an M3x10 (or M3x8) BHCS. Do not overtighten, as you are threading directly into plastic.
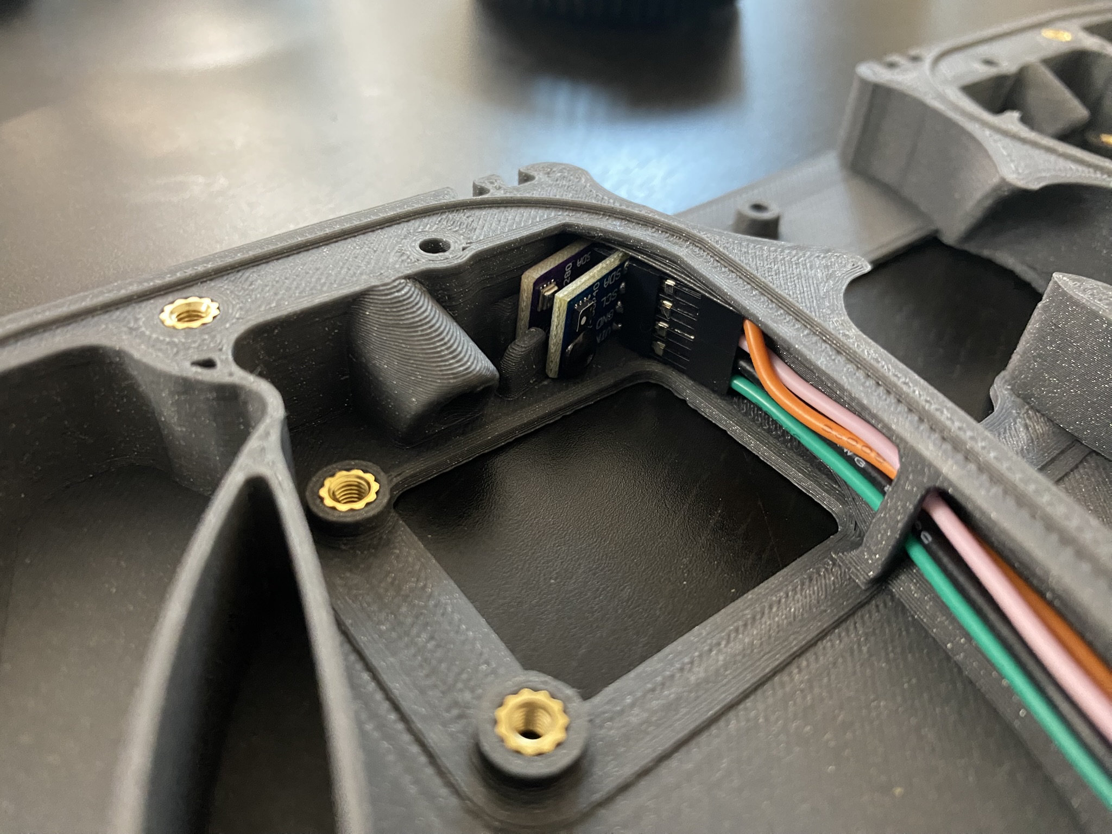
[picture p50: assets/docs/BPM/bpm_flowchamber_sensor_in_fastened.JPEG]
BPM sensor-in fastened


1. At this point break off the fan wire pin from the center of the [M_1a.0_FlowChamber_BPM.stl](../../STLs/1_FlowChamber/1a_BackPanelMount/StealthMax/M_1a.0_FlowChamber_BPM.stl). It should come off easily.
   -  If you misplaced the printed fan wire pin, you can reprint it: [1.5_FanWirePin_Spare.stl](../../STLs/1_FlowChamber/1.5_FanWirePin_Spare.stl).
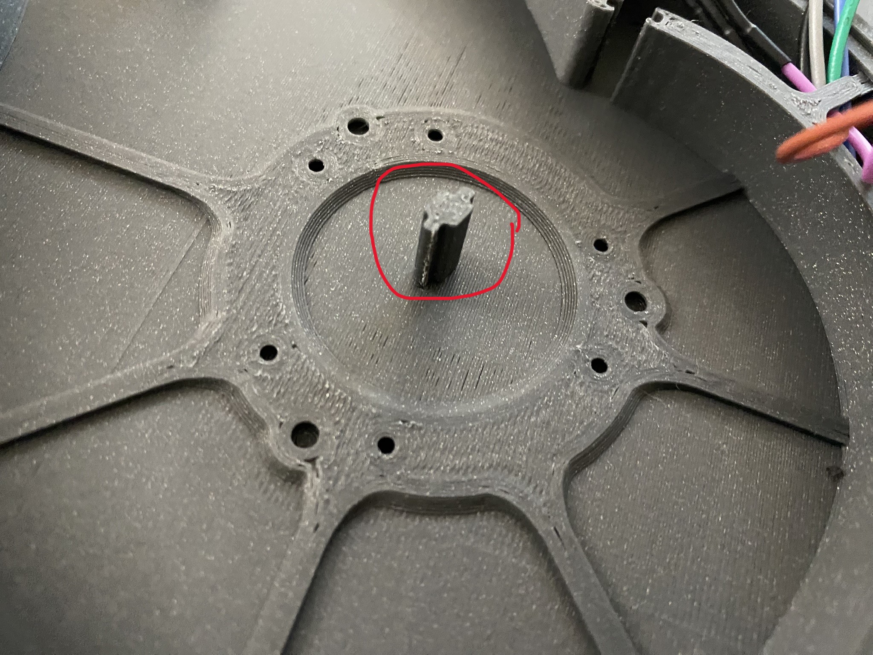
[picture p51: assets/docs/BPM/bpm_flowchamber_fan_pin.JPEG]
BPM Fan Wire Pin


1. Place the Delta BFB0712HF fan in the center of the [M_1a.0_FlowChamber_BPM.stl](../../STLs/1_FlowChamber/1a_BackPanelMount/StealthMax/M_1a.0_FlowChamber_BPM.stl) and hold it down securely while flipping over the flow chamber to attach the Delta BFB0712HF fan using 3x M2x4 FHCS. Do not overtighten, as M2 screws are very fragile.
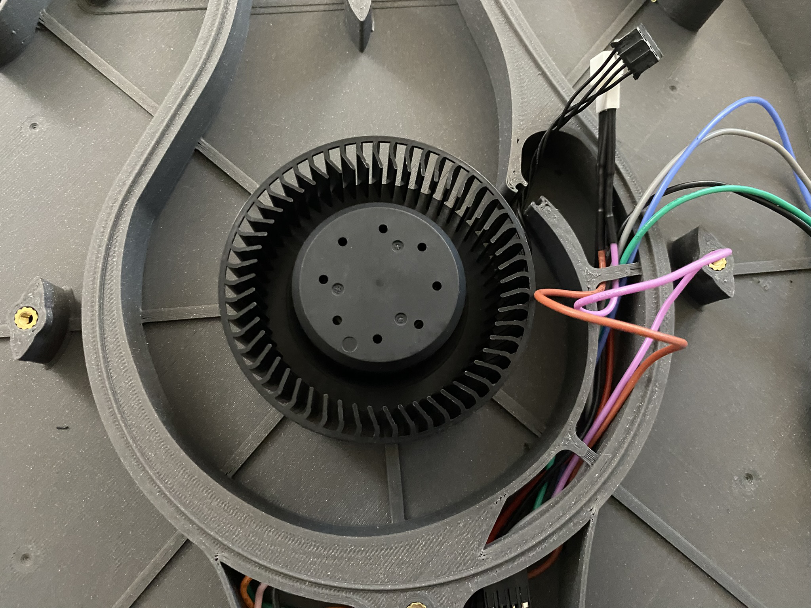
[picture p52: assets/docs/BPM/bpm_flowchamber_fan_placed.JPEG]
BPM Delta BFB0712HF fan placed

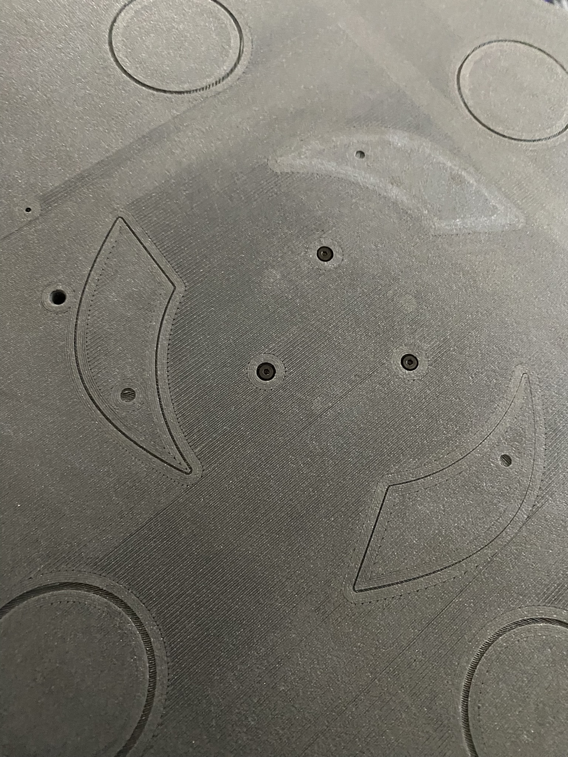
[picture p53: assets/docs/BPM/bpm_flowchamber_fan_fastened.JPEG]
BPM Delta BFB0712HF fan fastened


1.  Connect the Delta BFB0712HF fan connector to the 4-pin JST-PH 2.0 male pin/female connector.
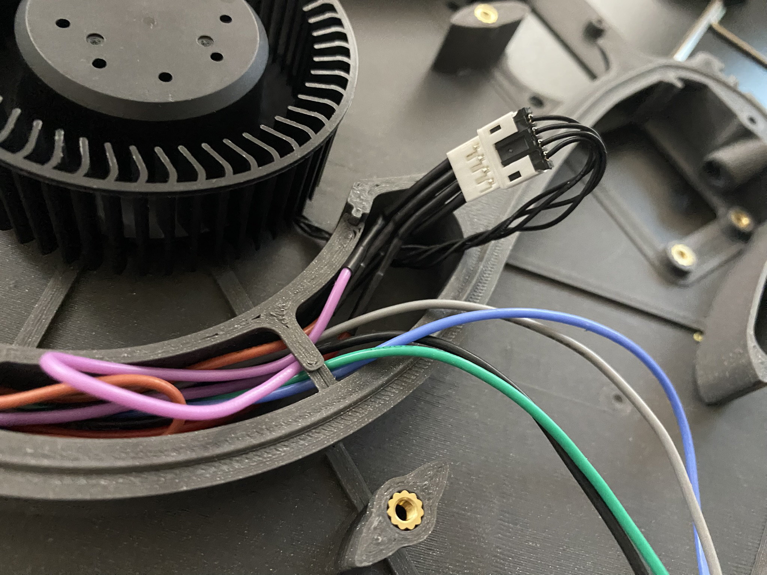
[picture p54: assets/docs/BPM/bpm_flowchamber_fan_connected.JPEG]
BPM Delta BFB0712HF fan connected


1.  Route the Delta BFB0712HF fan cable through the passage on the [M_1a.0_FlowChamber_BPM.stl](../../STLs/1_FlowChamber/1a_BackPanelMount/StealthMax/M_1a.0_FlowChamber_BPM.stl) and secure it down using the fan wire pin that was printed in the center of the flow chamber. Do not push down on the fan wire pin too hard, as you may damage the cable.
   - If you misplaced the printed fan wire pin, you can reprint it: [1.5_FanWirePin_Spare.stl](../../STLs/1_FlowChamber/1.5_FanWirePin_Spare.stl).
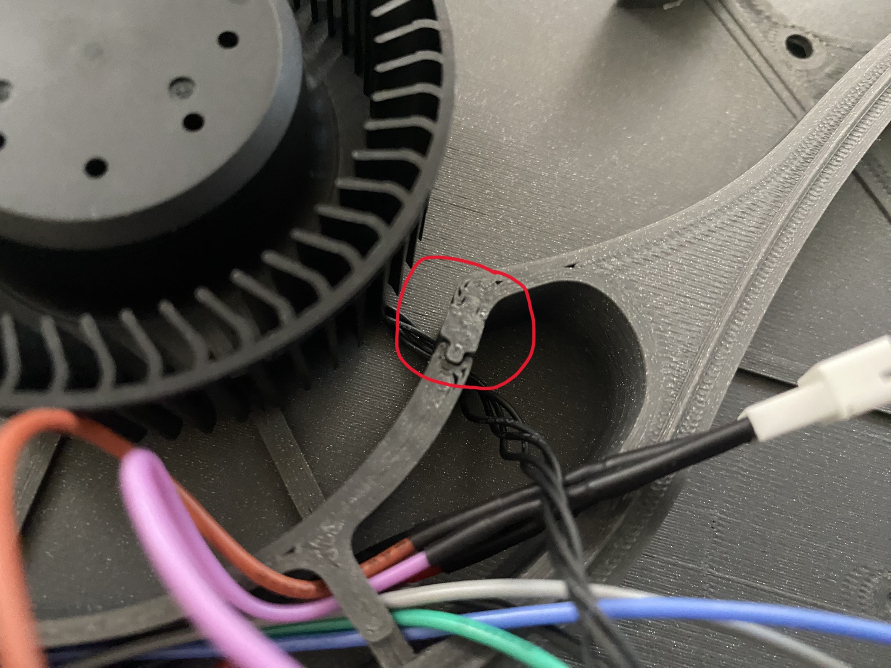
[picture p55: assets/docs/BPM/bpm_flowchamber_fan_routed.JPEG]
BPM Delta BFB0712HF fan routed


1.  Insert the [M_1a.1_AirExhaustWheel_BPM.stl](../../STLs/1_FlowChamber/1a_BackPanelMount/StealthMax/M_1a.1_AirExhaustWheel_BPM.stl) into the [M_1a.0_FlowChamber_BPM.stl](../../STLs/1_FlowChamber/1a_BackPanelMount/StealthMax/M_1a.0_FlowChamber_BPM.stl).
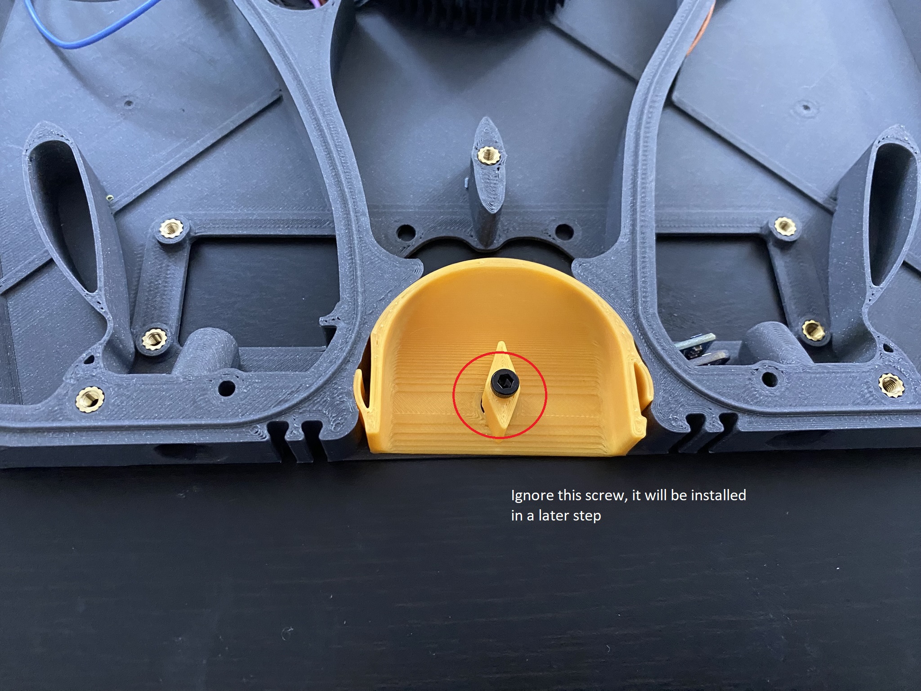
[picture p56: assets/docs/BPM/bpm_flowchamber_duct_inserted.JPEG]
BPM air exhaust wheel inserted


1.  Slide the [1.2_AirExhaustSlider.stl](../../STLs/1_FlowChamber/1.2_AirExhaustSlider.stl) into the [M_1a.0_FlowChamber_BPM.stl](../../STLs/1_FlowChamber/1a_BackPanelMount/StealthMax/M_1a.0_FlowChamber_BPM.stl). IGNORE THE SCREW PLACED IN THIS PICTURE. It will be placed in a later step. The image is incorrect.
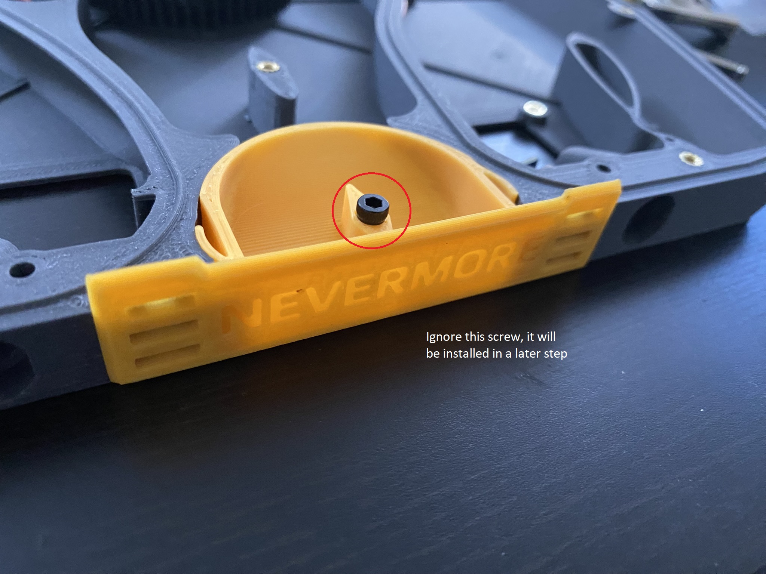
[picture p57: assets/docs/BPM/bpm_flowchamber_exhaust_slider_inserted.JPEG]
BPM exhaust slider inserted


1.  Double-check that all the electronics and wiring before proceeding to the next step. See DOPM docs for a good picture.

[Next: Carbon Basket Assembly >](Carbon_Basket_Assembly.md)

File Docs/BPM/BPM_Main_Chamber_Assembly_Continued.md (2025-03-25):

# Back Panel Mount (BPM) Main Chamber Assembly Continued

These are instructions for the StealthMax (300) Smart Back Panel Mount (BPM). The majority of this part is borrowed from the DOPM documentation but with replaced images for continuity.

## Parts Required

Printed parts:
- 1x [M_2.0_MainChamber.stl](../../STLs/2_MainChamber/StealthMax/M_2.0_MainChamber.stl)
- 1x [M_3.0_LidFrame.stl](../../STLs/3_Lid/StealthMax/M_3.0_LidFrame.stl)
- 1x [M_2.7_IntakeSensorStackAccessLatch.stl](../../STLs/3_Lid/StealthMax/M_3.0_LidFrame.stl)
- 1x [M_2.8_BowdenTubeAccessLatch.stl](../../STLs/2_MainChamber/StealthMax/M_2.8_BowdenTubeAccessLatch.stl)
- 1x [M_2.6a_PicoAccessLatch.stl](../../STLs/2_MainChamber/StealthMax/M_2.6a_PicoAccessLatch.stl)
- 1x [M_2.5a_LogoCap.stl](../../STLs/2_MainChamber/StealthMax/M_2.5a_LogoCap.stl)
- 1x [M_2.3_HEPACover.stl](../../STLs/2_MainChamber/StealthMax/M_2.3_HEPACover.stl)
- 1x [1.3a_BowdenCap_Closed.stl](../../STLs/1_FlowChamber/1.3a_BowdenCap_Closed.stl)
- 1x [1.3b_BowdenCap_Open.stl](../../STLs/1_FlowChamber/1.3b_BowdenCap_Open.stl)

Hardware:
- 16x M3x6 BHCS
- 1x M3x10 (or M3x8) BHCS
- 1x M3x16 SHCS
- 1x PC4-M10 fitting
- 2x HEPA filters (for Xiaomi Mijia G1)

## Back Panel Mount (BPM) Main Chamber Assembly Continued

1. Route the sensor-out harness through the bottom of [M_2.0_MainChamber.stl](../../STLs/2_MainChamber/StealthMax/M_2.0_MainChamber.stl) and into the center area.
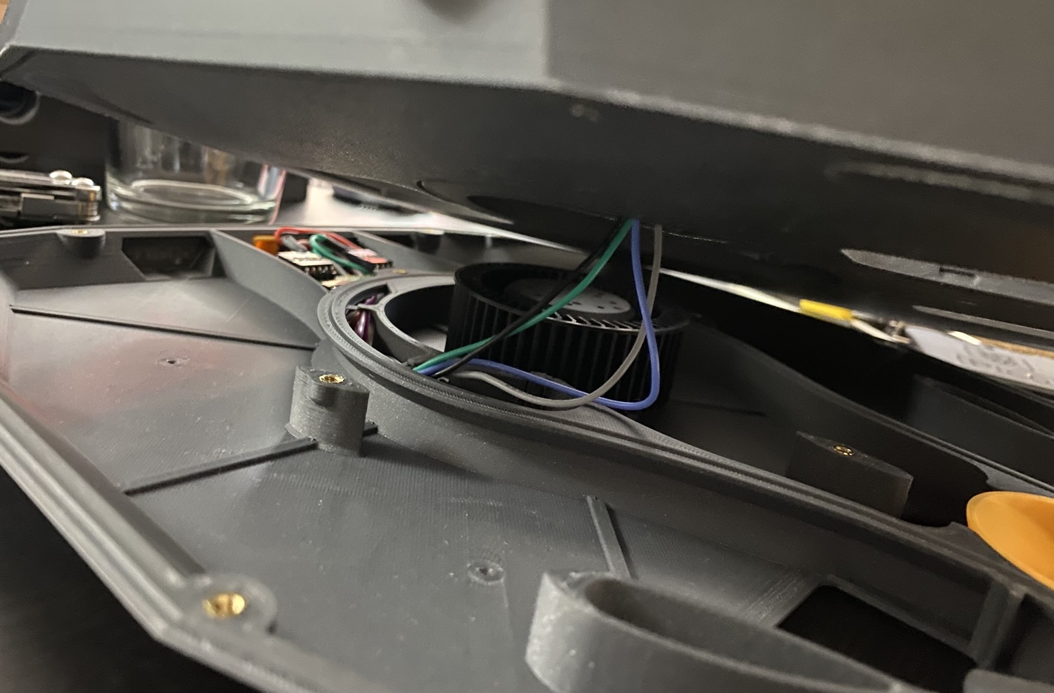
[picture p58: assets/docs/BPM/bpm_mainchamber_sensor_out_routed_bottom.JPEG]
Main chamber sensor-out routed bottom

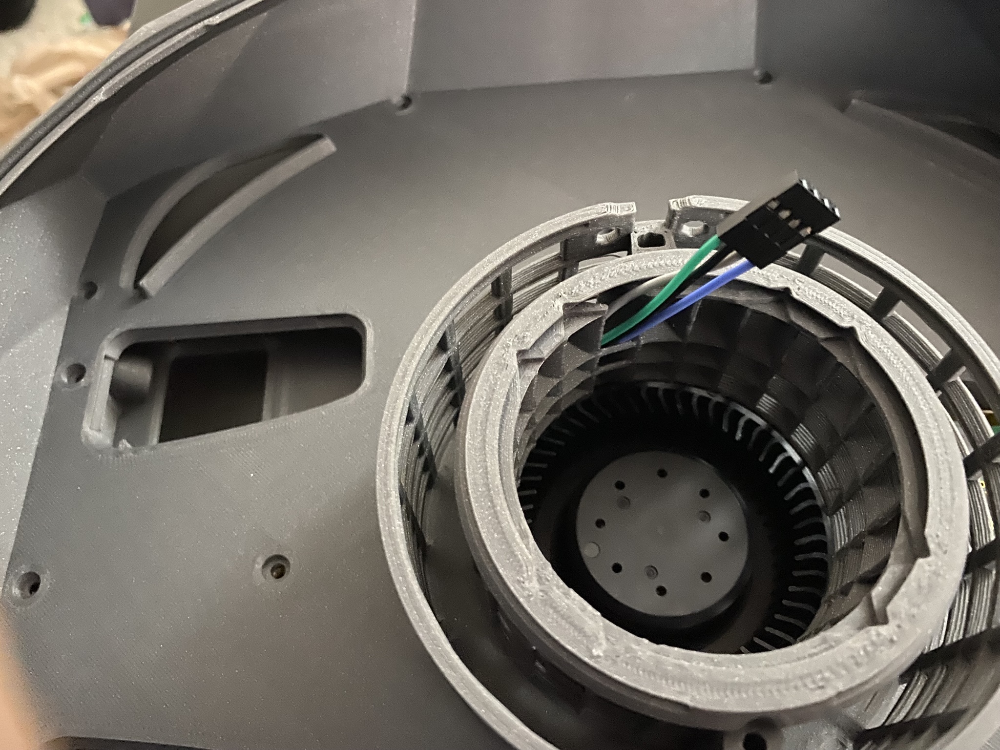
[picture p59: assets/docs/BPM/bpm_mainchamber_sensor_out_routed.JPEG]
Main chamber sensor-out routed


2. Insert the [M_2.7_IntakeSensorStackAccessLatch.stl](../../STLs/2_MainChamber/StealthMax/M_2.7_IntakeSensorStackAccessLatch.stl), [M_2.8_BowdenTubeAccessLatch.stl](../../STLs/2_MainChamber/StealthMax/M_2.8_BowdenTubeAccessLatch.stl), and [M_2.6a_PicoAccessLatch.stl](../../STLs/2_MainChamber/StealthMax/M_2.6a_PicoAccessLatch.stl), and fasten the [M_2.0_MainChamber.stl](../../STLs/2_MainChamber/StealthMax/M_2.0_MainChamber.stl) to the [M_1a.0_FlowChamber_BPM.stl](../../STLs/1_FlowChamber/1a_BackPanelMount/StealthMax/M_1a.0_FlowChamber_BPM.stl) using 12 M3x6 BHCS.
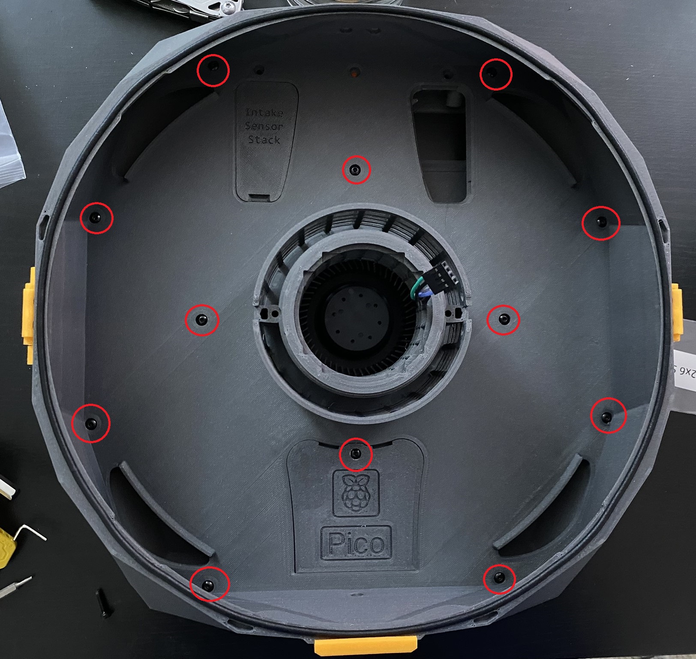
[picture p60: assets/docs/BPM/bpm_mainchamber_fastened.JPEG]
Main chamber fastened


1. Fasten the [M_1a.1_AirExhaustWheel_BPM.stl](../../STLs/1_FlowChamber/1a_BackPanelMount/StealthMax/M_1a.1_AirExhaustWheel_BPM.stl) in place with M3x16
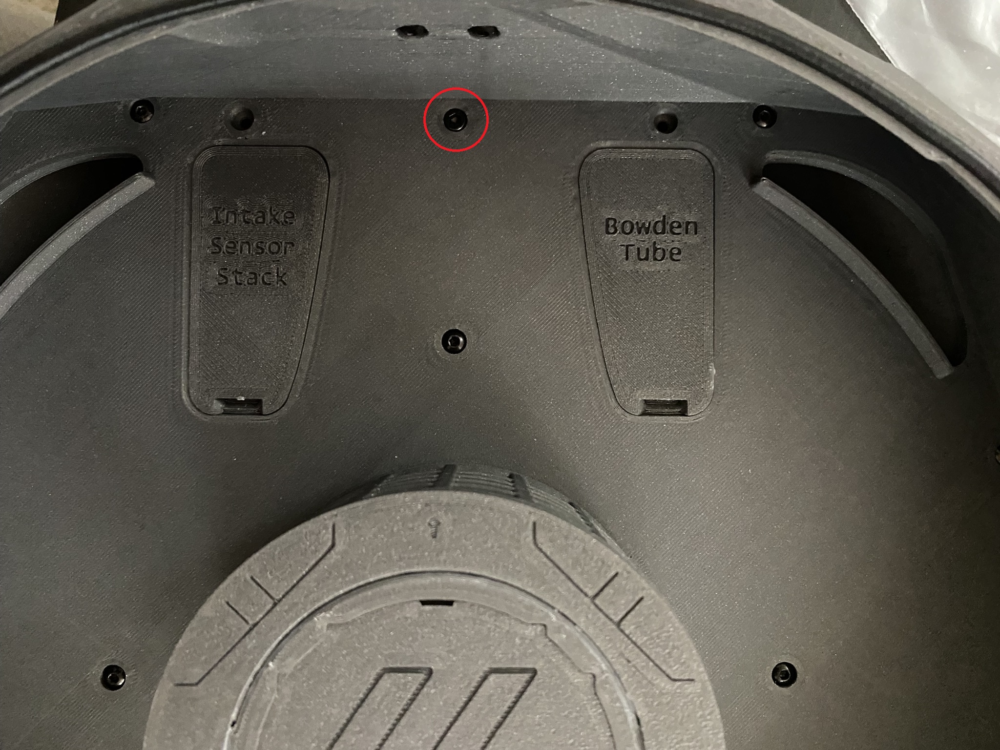
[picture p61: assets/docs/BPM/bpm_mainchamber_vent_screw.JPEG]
Main chamber


1. Gentle loosen the [3.2_LidFrontHinge.stl](../../STLs/3_Lid/3.2_LidFrontHinge.stl) attached to the [M_3.0_LidFrame.stl](../../STLs/3_Lid/StealthMax/M_3.0_LidFrame.stl) so it can freely move.
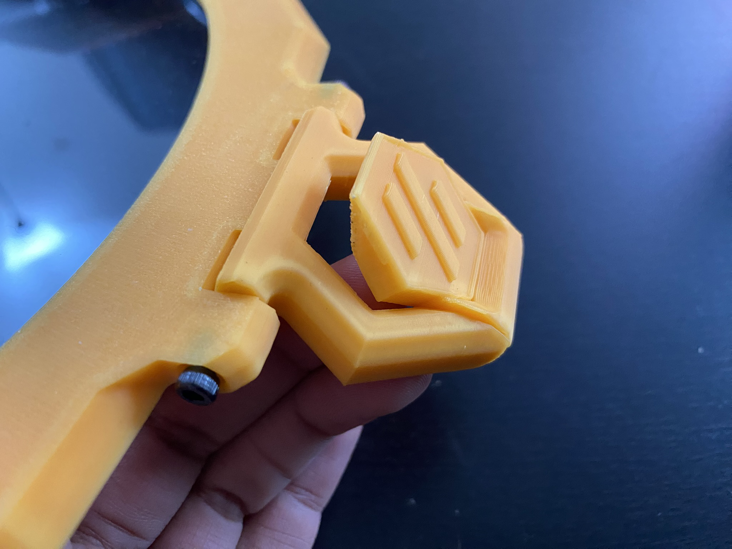
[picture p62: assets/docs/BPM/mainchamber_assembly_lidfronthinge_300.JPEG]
Main chamber front hinge


1. Fasten the [3.2_LidFrontHinge.stl](../../STLs/3_Lid/3.2_LidFrontHinge.stl) to the [M_2.0_MainChamber.stl](../../STLs/2_MainChamber/StealthMax/M_2.0_MainChamber.stl) using 2x M3x6 BHCS.
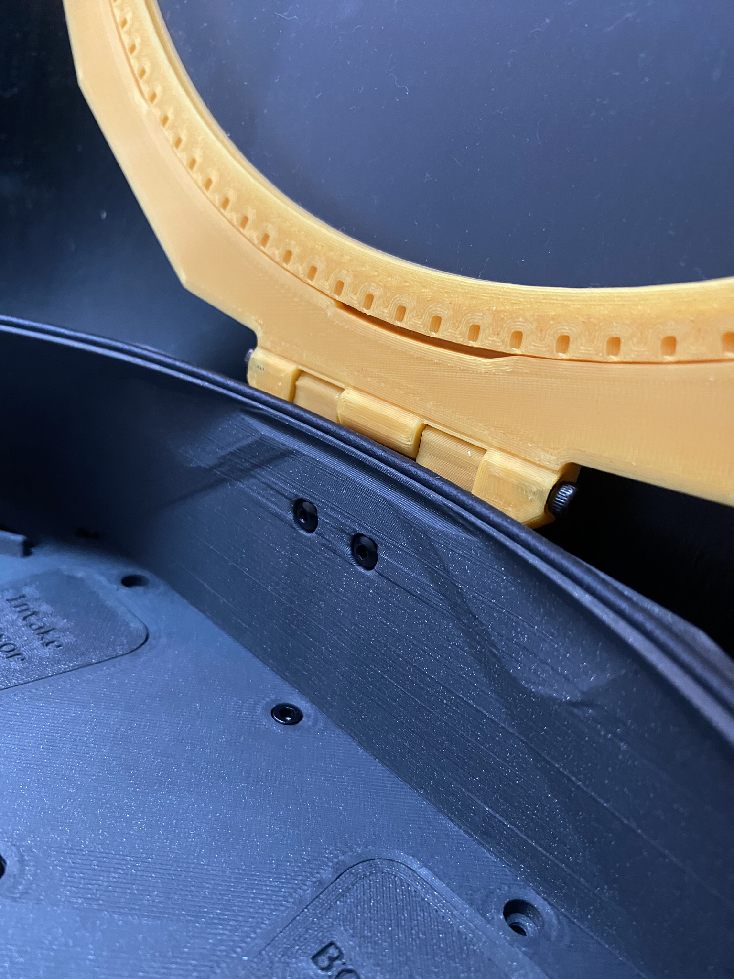
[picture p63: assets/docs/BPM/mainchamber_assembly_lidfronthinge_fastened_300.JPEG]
Main chamber front hinge fastened


1. Insert the [M_2.1_CarbonBasket.stl](../../STLs/2_MainChamber/StealthMax/M_2.1_CarbonBasket.stl) into the [M_2.0_MainChamber.stl](../../STLs/2_MainChamber/StealthMax/M_2.0_MainChamber.stl) at an angle, aligning the protrusions of the carbon basket with the notches of the main chamber. Then rotate the carbon basket to lock it in place.
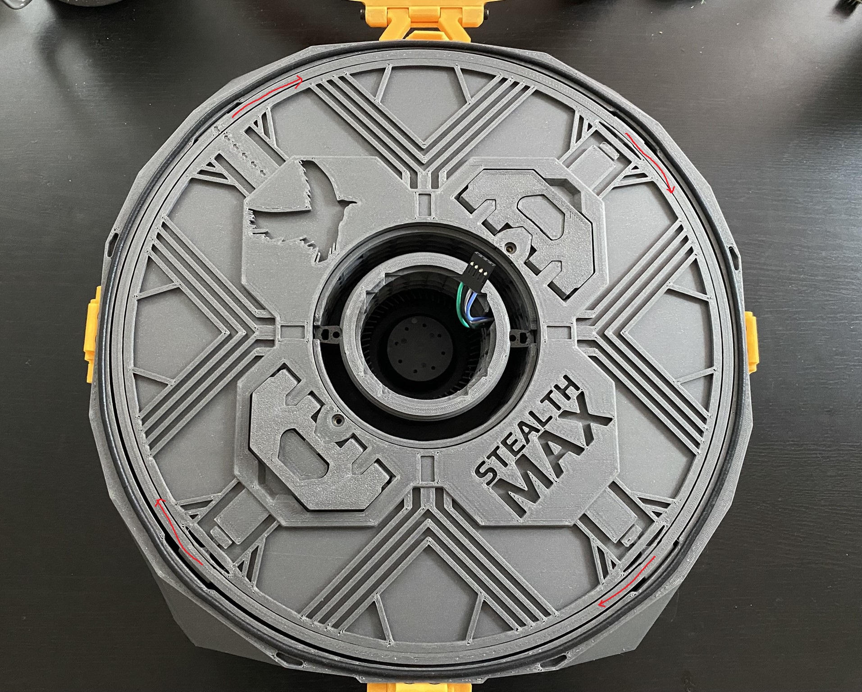
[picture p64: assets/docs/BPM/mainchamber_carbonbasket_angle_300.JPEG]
Main chamber carbon basket inserted angle

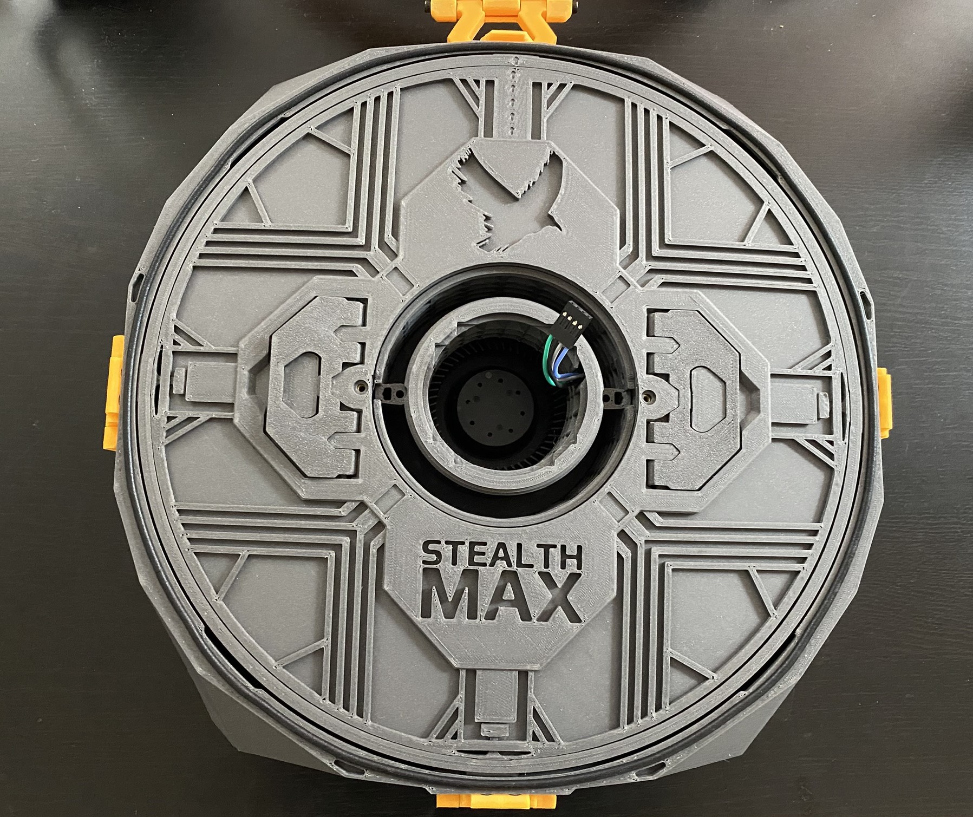
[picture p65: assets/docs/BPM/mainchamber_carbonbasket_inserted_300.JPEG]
Main chamber carbon basket inserted


1. Fasten the sensor-out PCBs to the [M_2.5a_LogoCap.stl](../../STLs/2_MainChamber/StealthMax/M_2.5a_LogoCap.stl) using an M3x10 (or M3x8) BHCS. Do not overtighten, as you are threading directly into plastic.
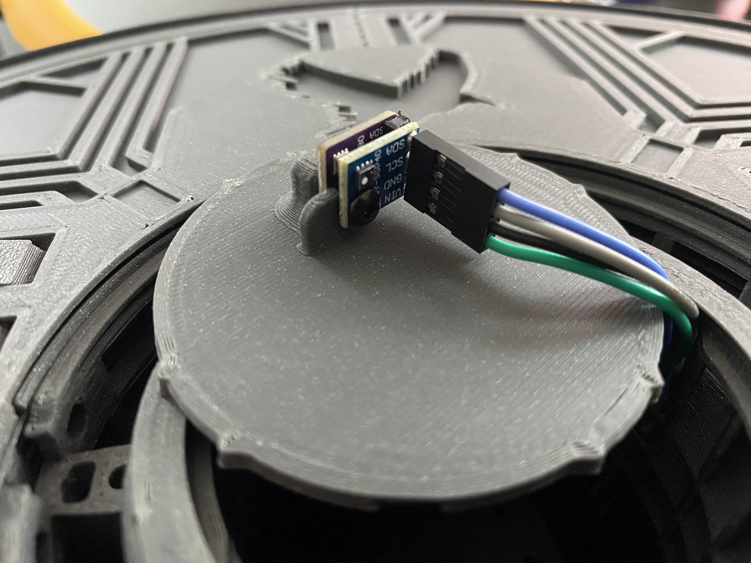
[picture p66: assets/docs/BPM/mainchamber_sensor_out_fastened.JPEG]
Sensor-out fastened


1. Flip the [M_2.5a_LogoCap.stl](../../STLs/2_MainChamber/StealthMax/M_2.5a_LogoCap.stl) and insert it into the center of the [M_2.0_MainChamber.stl](../../STLs/2_MainChamber/StealthMax/M_2.0_MainChamber.stl).
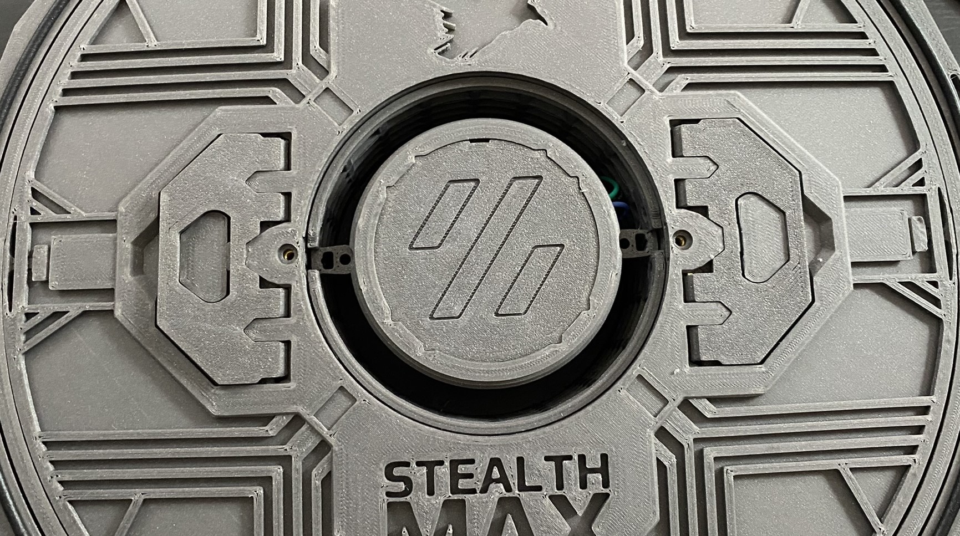
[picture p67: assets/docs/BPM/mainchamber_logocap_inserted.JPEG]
Main chamber logo cap inserted


1. Insert the 2x HEPA filters (for Xiaomi Mijia G1) into the center area of the [M_2.0_MainChamber.stl](../../STLs/2_MainChamber/StealthMax/M_2.0_MainChamber.stl).
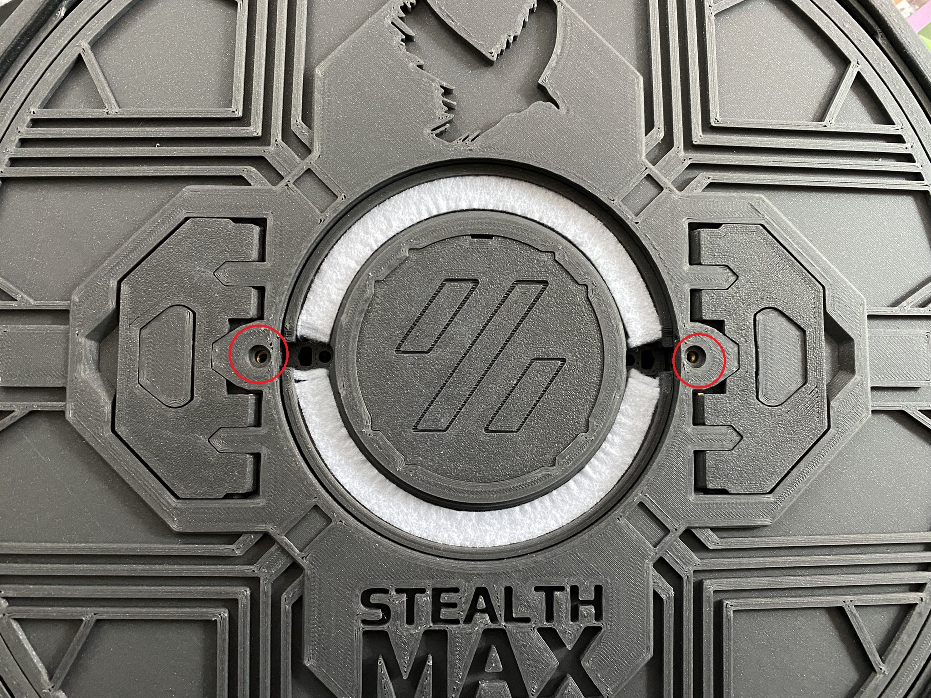
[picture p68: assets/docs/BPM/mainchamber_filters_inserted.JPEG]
Main chamber both filters inserted


1. Snap in the [M_2.3_HEPACover.stl](../../STLs/2_MainChamber/StealthMax/M_2.3_HEPACover.stl) and fasten the [M_2.2b_CarbonBasketLid_noHandles.stl](../../STLs/2_MainChamber/StealthMax/M_2.2b_CarbonBasketLid_noHandles.stl) to the [M_2.1_CarbonBasket.stl](../../STLs/2_MainChamber/StealthMax/M_2.1_CarbonBasket.stl) with 2x M3x6 BHCS.
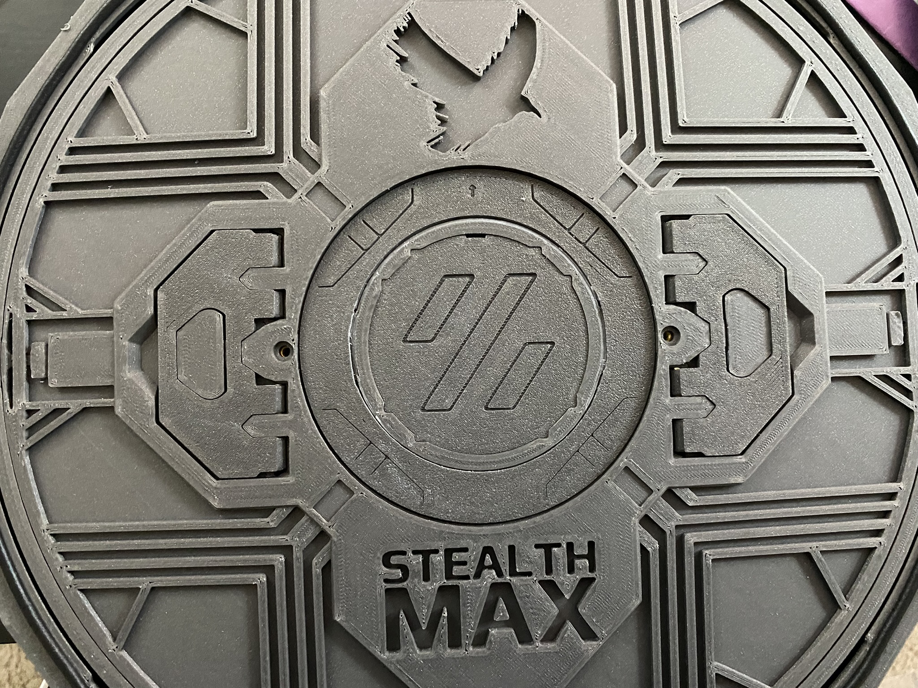
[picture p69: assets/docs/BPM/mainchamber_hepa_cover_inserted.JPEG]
Main chamber HEPA cover inserted


1. Screw in the PC4-M10 fitting to [1.3b_BowdenCap_Open.stl](../../STLs/1_FlowChamber/1.3b_BowdenCap_Open.stl). Snap in the [1.3a_BowdenCap_Closed.stl](../../STLs/1_FlowChamber/1.3a_BowdenCap_Closed.stl) and [1.3b_BowdenCap_Open.stl](../../STLs/1_FlowChamber/1.3b_BowdenCap_Open.stl) to the front of the [M_1a.0_FlowChamber_BPM.stl](../../STLs/1_FlowChamber/1a_BackPanelMount/StealthMax/M_1a.0_FlowChamber_BPM.stl). The positioning will depend on which way you route the bowden for the filament path.
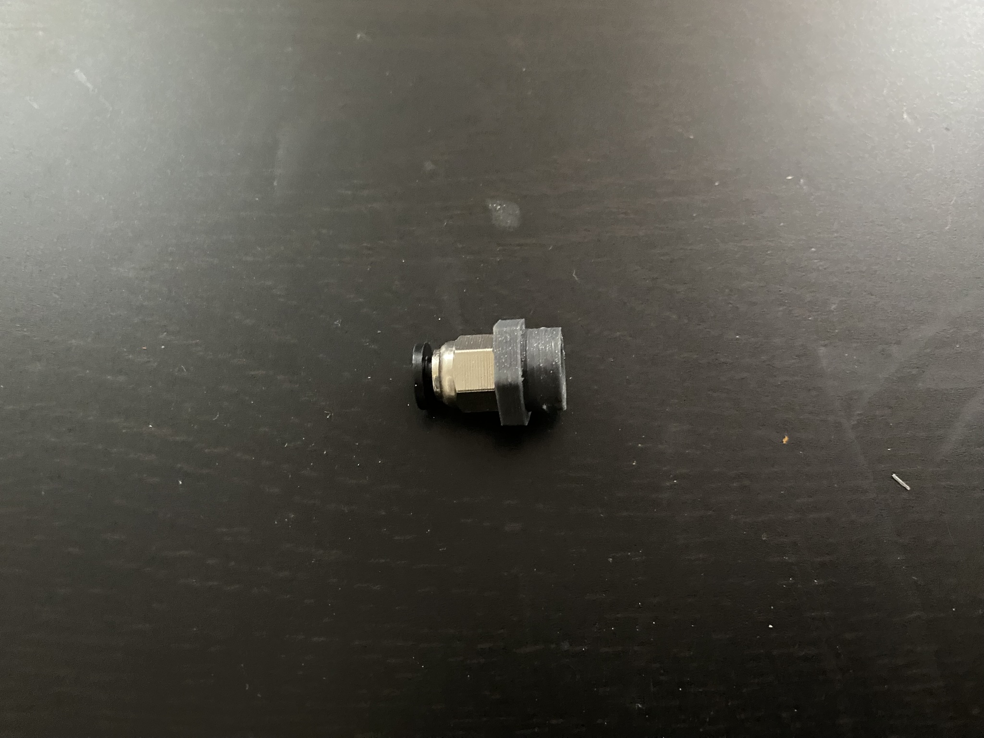
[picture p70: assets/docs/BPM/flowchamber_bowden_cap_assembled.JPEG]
Flow chamber bowden caps inserted

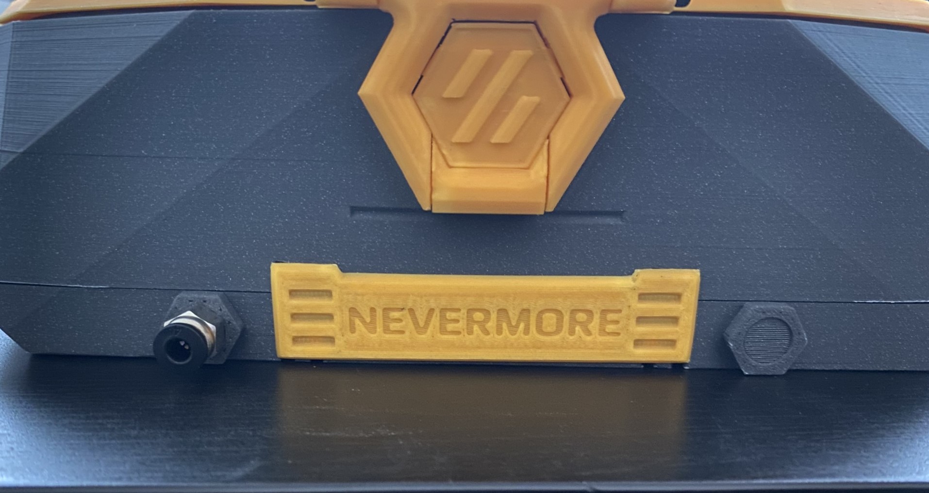
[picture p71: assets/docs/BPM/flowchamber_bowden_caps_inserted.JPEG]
Flow chamber bowden caps inserted


1.  STOP: Connect the StealthMax to power and continue software configuration according to the [Nevermore Controller Setup Guide](https://github.com/SanaaHamel/nevermore-controller#guide-setup). 
    1.  If one of your sensors is unplugged, better to know now than once it's mounted.

1. Once all software is configured, continue to the next step for back panel mounting.

[Next: Back Panel Mount (BPM) Mounting >](BPM_Mounting.md)

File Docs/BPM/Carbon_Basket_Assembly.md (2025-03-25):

# Carbon Basket Assembly

These are instructions for the StealthMax (300) Back Panel Mount (BPM) or Direct On Panel Mount (DOPM). The majority of this part is borrowed from the DOPM documentation but with replaced images for continuity.

## Parts Required

Printed parts:
- 1x [M_2.1_CarbonBasket.stl](../../STLs/2_MainChamber/StealthMax/M_2.1_CarbonBasket.stl)
- 1x [M_2.2b_CarbonBasketLid_noHandles.stl](../../STLs/2_MainChamber/StealthMax/M_2.2b_CarbonBasketLid_noHandles.stl)
- 2x [2.9_CarbonBasketLidHandle_Spare.stl](../../STLs/2_MainChamber/2.9_CarbonBasketLidHandle_Spare.stl)

Hardware:
- 1.75mm 3D printing filament

## Carbon Basket Assembly

1. Insert a [2.9_CarbonBasketLidHandle_Spare.stl](../../STLs/2_MainChamber/2.9_CarbonBasketLidHandle_Spare.stl) into a corresponding slot on [M_2.2b_CarbonBasketLid_noHandles.stl](../../STLs/2_MainChamber/StealthMax/M_2.2b_CarbonBasketLid_noHandles.stl) and flip it over.
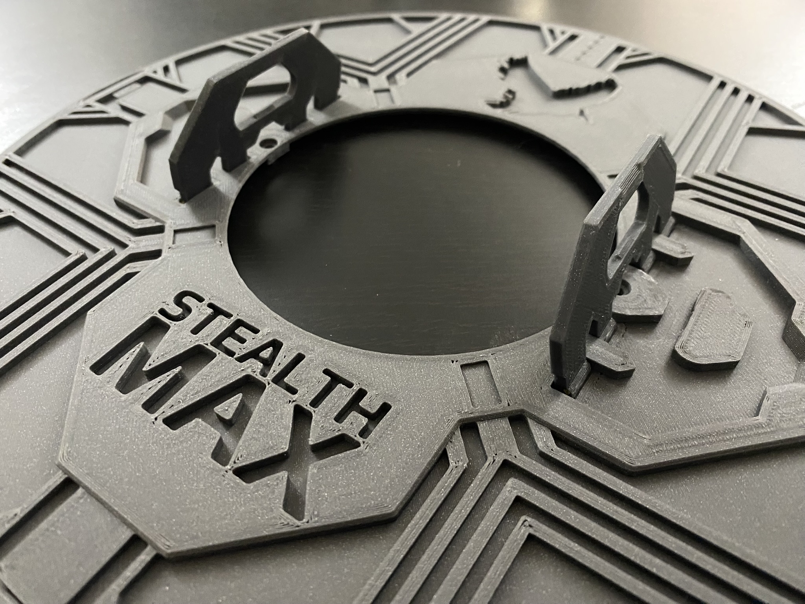
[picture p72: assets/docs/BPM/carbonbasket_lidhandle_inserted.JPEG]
Carbon basket lid handle inserted


1. Use some 1.75mm 3D printing filament to lock the handle in place from the back, cutting off the excess.
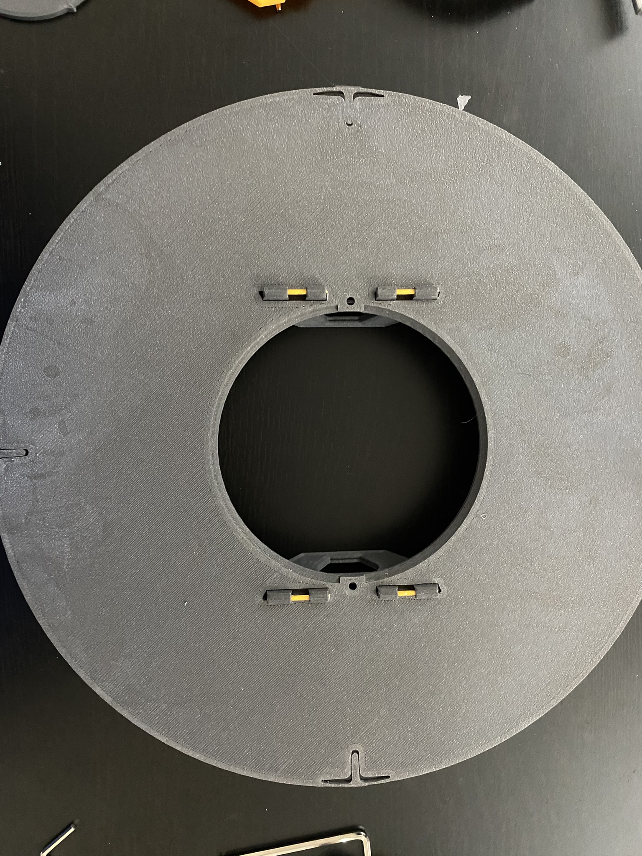
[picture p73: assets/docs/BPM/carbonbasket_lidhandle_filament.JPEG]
Carbon basket lid handle filament inserted


1. Insert the [M_2.2b_CarbonBasketLid_noHandles.stl](../../STLs/2_MainChamber/StealthMax/M_2.2b_CarbonBasketLid_noHandles.stl) on top of the [M_2.1_CarbonBasket.stl](../../STLs/2_MainChamber/StealthMax/M_2.1_CarbonBasket.stl) using the orientation indicators for alignment.
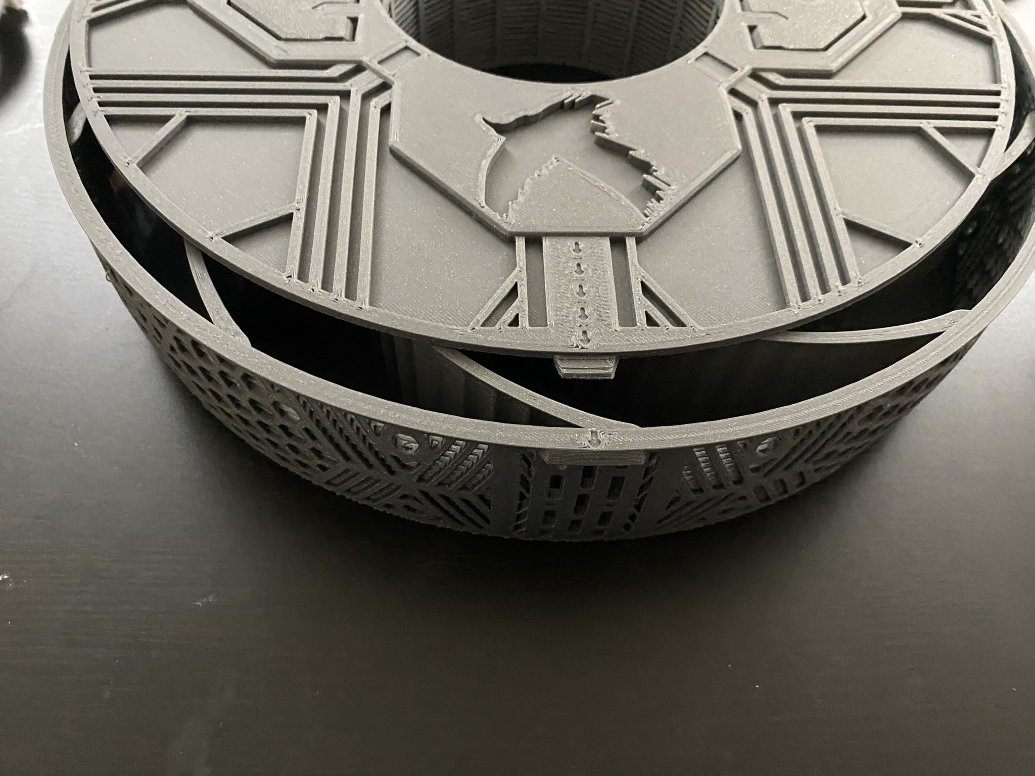
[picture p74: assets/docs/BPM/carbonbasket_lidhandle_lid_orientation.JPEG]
Carbon basket lid orientation

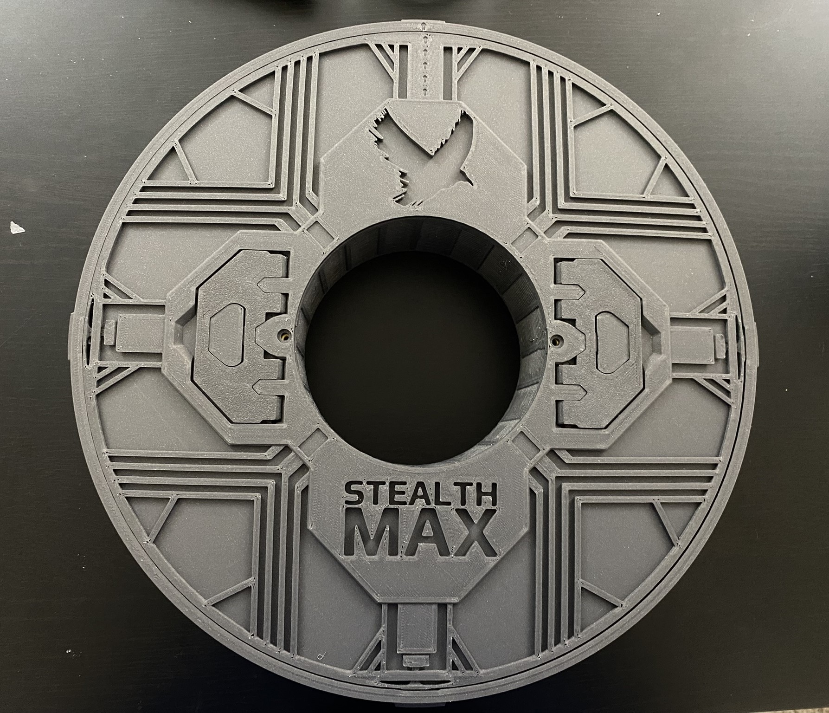
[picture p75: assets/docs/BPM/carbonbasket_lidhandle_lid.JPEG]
Carbon basket lid inserted


[Next: Back Panel Mount (BPM) Main Chamber Assembly Continued >](BPM_Main_Chamber_Assembly_Continued.md)

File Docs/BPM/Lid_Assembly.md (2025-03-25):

# Lid Assembly

These are instructions for the StealthMax (300) Back Panel Mount (BPM) or Direct On Panel Mount (DOPM). The majority of this part is borrowed from the DOPM documentation but with replaced images for continuity.

## Parts Required

Printed parts:
- 1x [M_3.0_LidFrame.stl](../../STLs/3_Lid/StealthMax/M_3.0_LidFrame.stl)
- 1x [M_3.1_LidPanelHolder.stl](../../STLs/3_Lid/StealthMax/M_3.1_LidPanelHolder.stl)
- 1x [3.2_LidFrontHinge.stl](../../STLs/3_Lid/3.2_LidFrontHinge.stl)

Hardware:
- 1x 250x3mm round acrylic panel (or Ghetto Panel mod)
- 2x M3x25 SHCS

## Lid Assembly

1. Attach [3.2_LidFrontHinge.stl](../../STLs/3_Lid/3.2_LidFrontHinge.stl) to the hinge location on [M_3.1_LidPanelHolder.stl](../../STLs/3_Lid/StealthMax/M_3.1_LidPanelHolder.stl) using 2x M3x25 SHCS. Do not overtighten, as you are threading directly into plastic.

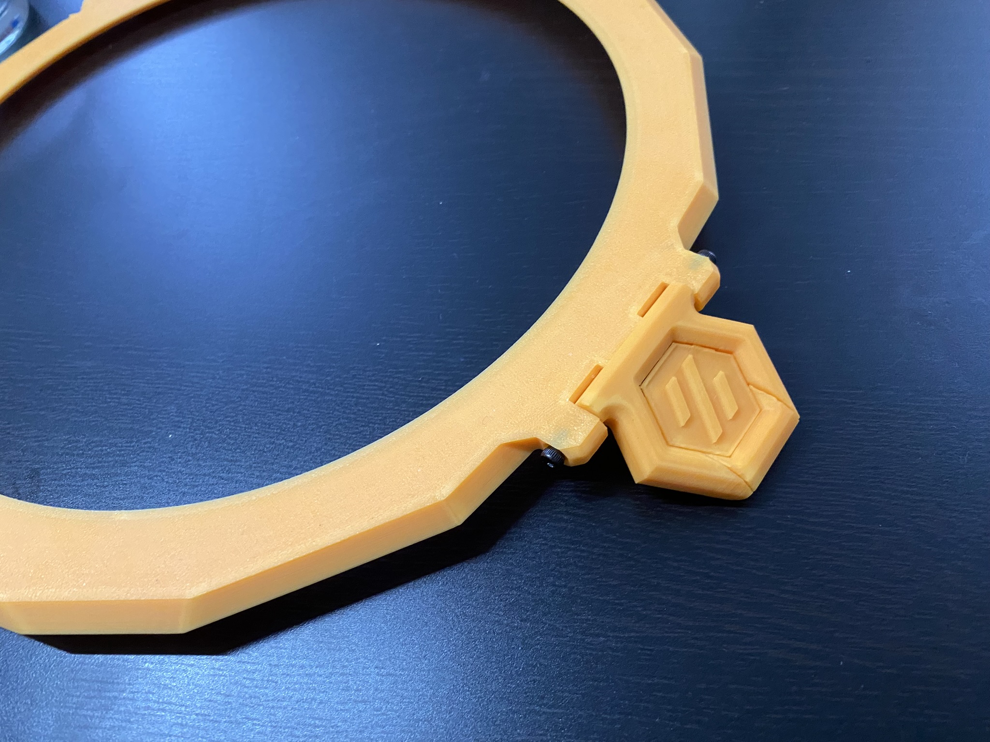
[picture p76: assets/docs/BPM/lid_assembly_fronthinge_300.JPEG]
Lid Front Hinge attach to Lid Panel Holder


2. Flip [M_3.1_LidPanelHolder.stl](../../STLs/3_Lid/StealthMax/M_3.1_LidPanelHolder.stl) over and fully insert the 250x3mm round acrylic panel (or Ghetto Panel mod) in the center.

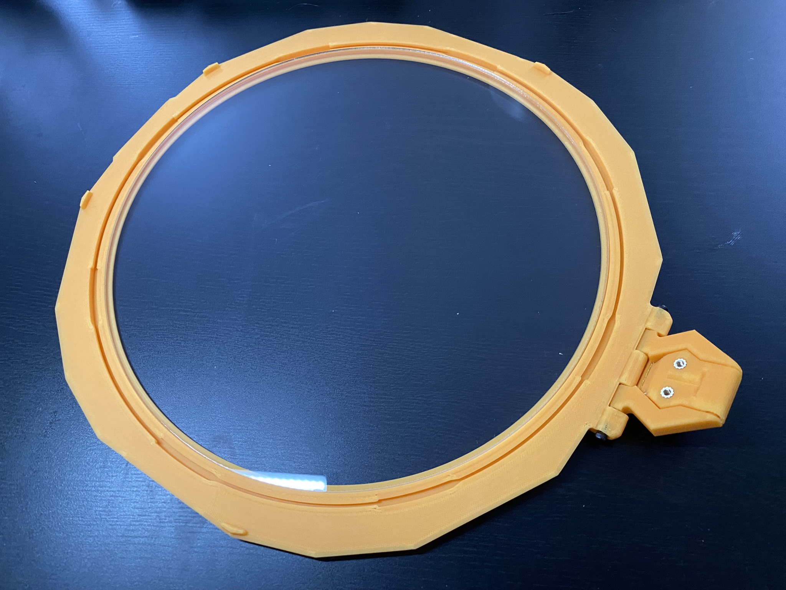
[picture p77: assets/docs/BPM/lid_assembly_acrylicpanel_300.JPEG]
Acrylic Panel insert into Lid Panel Holder


3. Insert [M_3.0_LidFrame.stl](../../STLs/3_Lid/StealthMax/M_3.0_LidFrame.stl) into [M_3.1_LidPanelHolder.stl](../../STLs/3_Lid/StealthMax/M_3.1_LidPanelHolder.stl), aligning the notches so it sits flush.

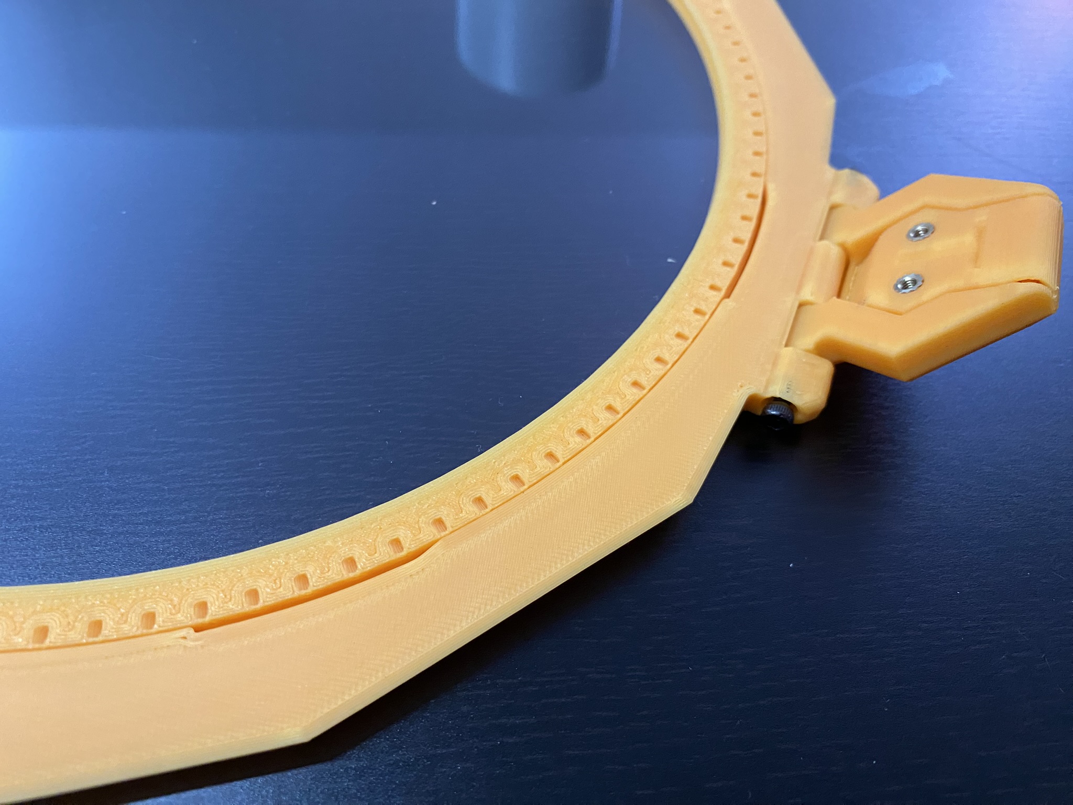
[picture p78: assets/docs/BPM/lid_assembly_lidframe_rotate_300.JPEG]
Lid Frame insert into Lid Panel Holder


4. Rotate [M_3.0_LidFrame.stl](../../STLs/3_Lid/StealthMax/M_3.0_LidFrame.stl) so it becomes locked into [M_3.1_LidPanelHolder.stl](../../STLs/3_Lid/StealthMax/M_3.1_LidPanelHolder.stl).

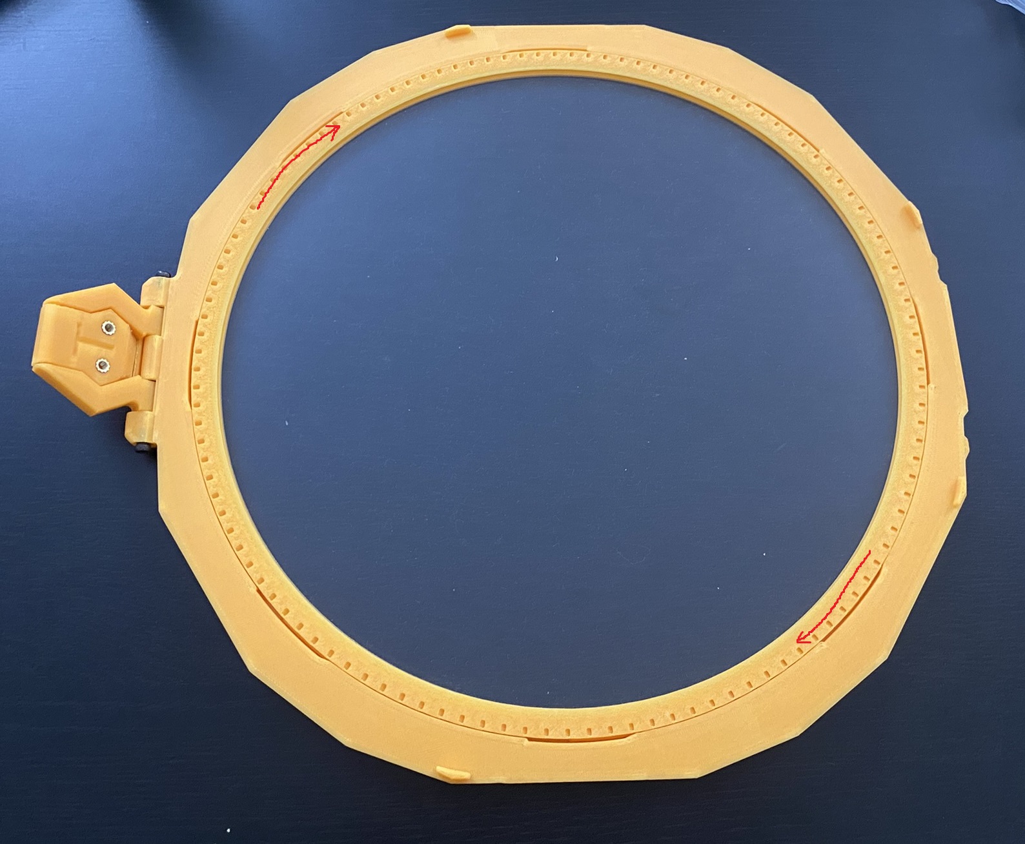
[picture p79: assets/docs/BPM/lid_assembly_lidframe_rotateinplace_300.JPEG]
Lid Frame insert locking


[Next: Main Chamber Assembly >](Main_Chamber_Assembly.md)

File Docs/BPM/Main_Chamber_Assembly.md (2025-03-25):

# Main Chamber Assembly

These are instructions for the StealthMax (300) Back Panel Mount (BPM) or Direct On Panel Mount (DOPM). The majority of this part is borrowed from the DOPM documentation but with replaced images for continuity.

## Parts Required

Printed parts:
- 1x [M_2.0_MainChamber.stl](../../STLs/2_MainChamber/StealthMax/M_2.0_MainChamber.stl)
- 3x [3.3_LidLatch.stl](../../STLs/3_Lid/3.3_LidLatch.stl)

Hardware:
- 6x M3x6 BHCS
- 3mm sponge cord
- Super glue

## Main Chamber Assembly

1. Ensure your 3x [3.3_LidLatch.stl](../../STLs/3_Lid/3.3_LidLatch.stl) are able to freely rotate after gently snapping them loose according to the [instructions on the Wiki](https://github.com/nevermore3d/StealthMax/wiki/Assembly#compression-latches).

2. Attach [3.3_LidLatch.stl](../../STLs/3_Lid/3.3_LidLatch.stl) to the three sides of [M_2.0_MainChamber.stl](../../STLs/2_MainChamber/StealthMax/M_2.0_MainChamber.stl) with the double M3 heat-set inserts near the top, using 2x M3x6 BHCS for each latch. Do not overtighten.

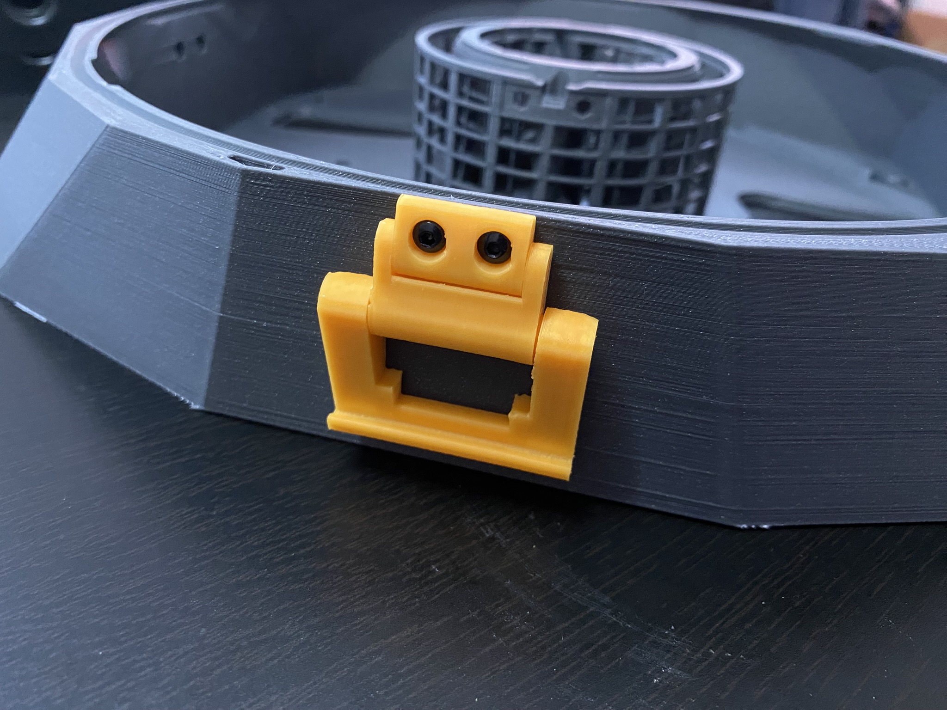
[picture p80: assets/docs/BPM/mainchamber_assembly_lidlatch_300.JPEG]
Lid Latch attach to Main Chamber


3. Attach the 3mm sponge cord all around [M_2.0_MainChamber.stl](../../STLs/2_MainChamber/StealthMax/M_2.0_MainChamber.stl) using a thin layer of super glue, according to the [instructions on the Wiki](https://github.com/nevermore3d/StealthMax/wiki/Assembly#lid).

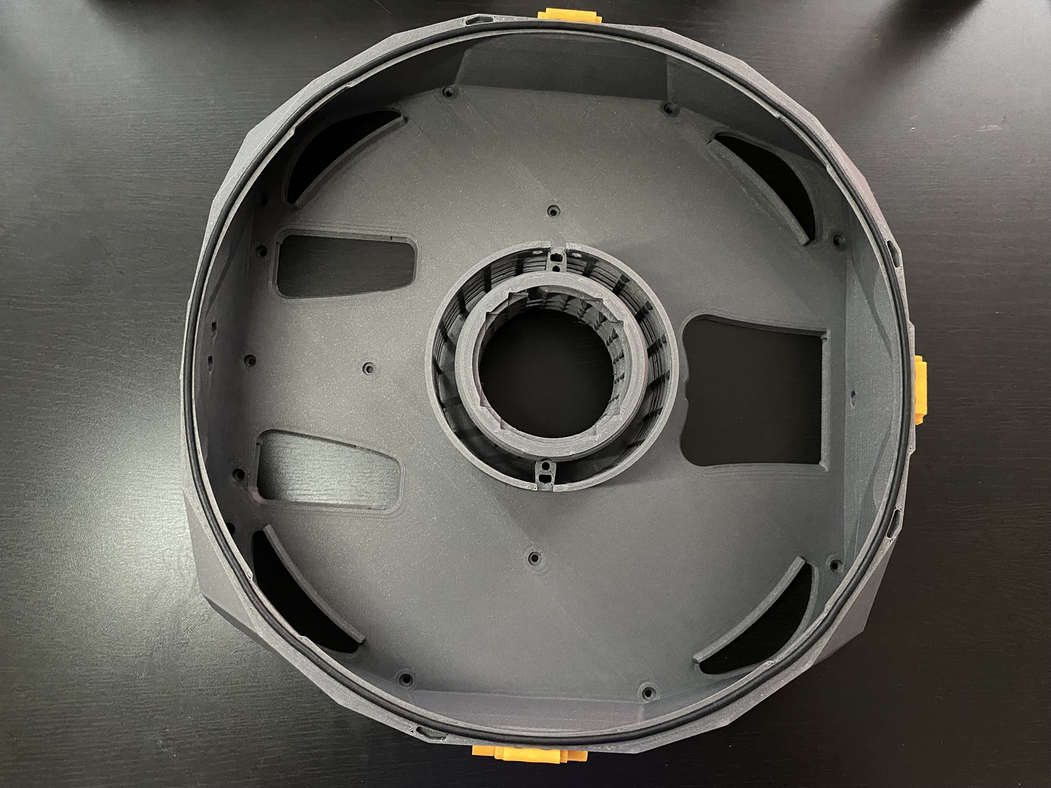
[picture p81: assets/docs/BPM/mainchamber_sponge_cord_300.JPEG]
Sponge cord attached to Main Chamber


4. Optional: Dry-fit the [lid assembly](Lid_Assembly.md) on top of [M_2.0_MainChamber.stl](../../STLs/2_MainChamber/StealthMax/M_2.0_MainChamber.stl) to ensure all latches properly close. Note that [3.2_LidFrontHinge.stl](../../STLs/3_Lid/3.2_LidFrontHinge.stl) will be attached to [M_2.0_MainChamber.stl](../../STLs/2_MainChamber/StealthMax/M_2.0_MainChamber.stl) in a later step.

Main Chamber dry fit

[Next: Back Panel Mount (BPM) Electronics Preparation >](BPM_Electronics_Preparation.md)

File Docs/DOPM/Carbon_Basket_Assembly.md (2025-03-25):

# Carbon Basket Assembly

These are instructions for the StealthMax (300) Back Panel Mount (BPM) or Direct On Panel Mount (DOPM).

## Parts Required

Printed parts:
- 1x [M_2.1_CarbonBasket.stl](/STLs/2_MainChamber/StealthMax/M_2.1_CarbonBasket.stl)
- 1x [M_2.2b_CarbonBasketLid_noHandles.stl](/STLs/2_MainChamber/StealthMax/M_2.2b_CarbonBasketLid_noHandles.stl)
- 2x [2.9_CarbonBasketLidHandle_Spare.stl](/STLs/2_MainChamber/2.9_CarbonBasketLidHandle_Spare.stl)

Hardware:
- 1.75mm 3D printing filament

## Carbon Basket Assembly

1. Insert a [2.9_CarbonBasketLidHandle_Spare.stl](/STLs/2_MainChamber/2.9_CarbonBasketLidHandle_Spare.stl) into a corresponding slot on [M_2.2b_CarbonBasketLid_noHandles.stl](/STLs/2_MainChamber/StealthMax/M_2.2b_CarbonBasketLid_noHandles.stl) and flip it over.
Carbon basket lid handle inserted
Carbon basket lid handle inserted back

2. Use some 1.75mm 3D printing filament to lock the handle in place from the back, cutting off the excess.
Carbon basket lid handle filament inserted

3. Insert the [M_2.2b_CarbonBasketLid_noHandles.stl](/STLs/2_MainChamber/StealthMax/M_2.2b_CarbonBasketLid_noHandles.stl) on top of the [M_2.1_CarbonBasket.stl](/STLs/2_MainChamber/StealthMax/M_2.1_CarbonBasket.stl) using the orientation indicators for alignment.
Carbon basket lid orientation
Carbon basket lid inserted

[Next: Direct On Panel Mount (DOPM) Main Chamber Assembly Continued >](DOPM_Main_Chamber_Assembly_Continued.md)

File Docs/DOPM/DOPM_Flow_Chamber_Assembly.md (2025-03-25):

# Direct On Panel Mount (DOPM) Flow Chamber Assembly

These are instructions for the StealthMax (300) Smart Direct On Panel Mount (DOPM).

## Parts Required

Printed parts:
- 1x [M_1b.0_FlowChamber_DOPM.stl](/STLs/1_FlowChamber/1b_DirectOnPanelMount/StealthMax/M_1b.0_FlowChamber_DOPM.stl)
- 4x [1.6_PCBSpacer.stl](/STLs/1_FlowChamber/1.6_PCBSpacer.stl)
- 1x [M_1b.1_RemovableAirDuct_DOPM.stl](/STLs/1_FlowChamber/1b_DirectOnPanelMount/StealthMax/M_1b.1_RemovableAirDuct_DOPM.stl)
- 1x [1.2_AirExhaustSlider.stl](/STLs/1_FlowChamber/1.2_AirExhaustSlider.stl)
- Optional: 1x [1.5_FanWirePin_Spare.stl](/STLs/1_FlowChamber/1.5_FanWirePin_Spare.stl)

Hardware:
- Raspberry Pi Pico W
- Female Dupont pins
- 1x 5-pin female DuPont connector housing
- 1x Delta BFB0712HF (fan)
- 1x M3x10 (or M3x8) BHCS
- 3x M2x4 FHCS

## Direct On Panel Mount (DOPM) Smart Electronics

1. Route the power harness from preparation step 14 through the [M_1b.0_FlowChamber_DOPM.stl](/STLs/1_FlowChamber/1b_DirectOnPanelMount/StealthMax/M_1b.0_FlowChamber_DOPM.stl) as follows, and connect the Matek Systems MBEC6S/MBEC2A buck converter.
DOPM power harness routed

2. Push in the [1.4a_CableEntryCap_M8Barrel.stl](/STLs/1_FlowChamber/1.4a_CableEntryCap_M8Barrel.stl) into the slot.
   - If the cable entry cap doesn't push in easily, carefully shave off 0.3-0.5mm of plastic from the [M_1b.0_FlowChamber_DOPM.stl](/STLs/1_FlowChamber/1b_DirectOnPanelMount/StealthMax/M_1b.0_FlowChamber_DOPM.stl) on both sides of the inside of the hole marked below.
DOPM cable entry cap assembly

3. Route the sensor-in harness from [electronics preparation](/Docs/DOPM_Electronics_Preparation.md) step 7 through the [M_1b.0_FlowChamber_DOPM.stl](/STLs/1_FlowChamber/1b_DirectOnPanelMount/StealthMax/M_1b.0_FlowChamber_DOPM.stl) as follows.
DOPM sensor-in harness routed

4. Route the sensor-out harness from [electronics preparation](/Docs/DOPM_Electronics_Preparation.md) step 8 through the [M_1b.0_FlowChamber_DOPM.stl](/STLs/1_FlowChamber/1b_DirectOnPanelMount/StealthMax/M_1b.0_FlowChamber_DOPM.stl) as follows.
DOPM sensor-out harness routed

5. Crimp 2 DuPont female pins to the remaining uncrimped black and green wires from step 9. Two wires into one DuPont pin is a tight fit, but it can be done with some patience.
DOPM Black/Green DuPont connector

6. Insert the double-crimped green wires into the 4-pin DuPont connector from [electronics preparation](/Docs/DOPM_Electronics_Preparation.md) step 14, and the double-crimped black wires into a 5-pin DuPont connector, together with the pink, yellow, gray, and blue wires of the sensor-in and sensor-out harnesses.
DOPM Black/Green DuPont connector

7. Connect the 2 4-pin and single 5-pin DuPont connector to the Raspberry Pi Pico W and route the cables underneath the Pico W while fastening the Pico W to the [M_1b.0_FlowChamber_DOPM.stl](/STLs/1_FlowChamber/1b_DirectOnPanelMount/StealthMax/M_1b.0_FlowChamber_DOPM.stl) using 4 [1.6_PCBSpacer.stl](/STLs/1_FlowChamber/1.6_PCBSpacer.stl) and 4 M2x6 self-tapping screws. Do not overtighten, as you are threading directly into plastic.
   - It helps to tape down the wires so they all sit flush underneath the Pico W. Fastening the Pico W can be a bit finicky, so be patient.
DOPM Black/Green DuPont connector

8. Fasten the sensor-in PCBs to the [M_1b.0_FlowChamber_DOPM.stl](/STLs/1_FlowChamber/1b_DirectOnPanelMount/StealthMax/M_1b.0_FlowChamber_DOPM.stl) using an M3x10 (or M3x8) BHCS. Do not overtighten, as you are threading directly into plastic.
DOPM sensor-in fastened

9. Place the Delta BFB0712HF fan in the center of the [M_1b.0_FlowChamber_DOPM.stl](/STLs/1_FlowChamber/1b_DirectOnPanelMount/StealthMax/M_1b.0_FlowChamber_DOPM.stl) and hold it down securely while flipping over the flow chamber to attach the Delta BFB0712HF fan using 3x M2x4 FHCS. Do not overtighten, as M2 screws are very fragile.
DOPM Delta BFB0712HF fan placed
DOPM Delta BFB0712HF fan fastened

10. Connect the Delta BFB0712HF fan connector to the 4-pin JST-PH 2.0 male pin/female connector.
DOPM Delta BFB0712HF fan connected

11. Route the Delta BFB0712HF fan cable through the passage on the [M_1b.0_FlowChamber_DOPM.stl](/STLs/1_FlowChamber/1b_DirectOnPanelMount/StealthMax/M_1b.0_FlowChamber_DOPM.stl) and secure it down using the fan wire pin that was printed in the center of the flow chamber. Do not push down on the fan wire pin too hard, as you may damage the cable.
   - If you misplaced the printed fan wire pin, you can reprint it: [1.5_FanWirePin_Spare.stl](/STLs/1_FlowChamber/1.5_FanWirePin_Spare.stl).
DOPM Delta BFB0712HF fan routed

12. Slide the [M_1b.1_RemovableAirDuct_DOPM.stl](/STLs/1_FlowChamber/1b_DirectOnPanelMount/StealthMax/M_1b.1_RemovableAirDuct_DOPM.stl) into the [M_1b.0_FlowChamber_DOPM.stl](/STLs/1_FlowChamber/1b_DirectOnPanelMount/StealthMax/M_1b.0_FlowChamber_DOPM.stl).
DOPM air duct inserted

1.  Slide the [1.2_AirExhaustSlider.stl](/STLs/1_FlowChamber/1.2_AirExhaustSlider.stl) into the [M_1b.0_FlowChamber_DOPM.stl](/STLs/1_FlowChamber/1b_DirectOnPanelMount/StealthMax/M_1b.0_FlowChamber_DOPM.stl).
DOPM exhaust slider inserted

1.  Double-check that all the electronics and wiring matches the picture below before proceeding to the next step.
DOPM flow chamber electronics complete

[Next: Carbon Basket Assembly >](Carbon_Basket_Assembly.md)

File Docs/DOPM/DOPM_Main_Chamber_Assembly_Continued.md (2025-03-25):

# Direct On Panel Mount (DOPM) Main Chamber Assembly Continued

These are instructions for the StealthMax (300) Smart Back Panel Mount (BPM).

## Parts Required

Printed parts:
- 1x [M_2.0_MainChamber.stl](/STLs/2_MainChamber/StealthMax/M_2.0_MainChamber.stl)
- 1x [M_3.0_LidFrame.stl](/STLs/3_Lid/StealthMax/M_3.0_LidFrame.stl)
- 1x [M_2.7_IntakeSensorStackAccessLatch.stl](/STLs/2_MainChamber/StealthMax/M_2.7_IntakeSensorStackAccessLatch.stl)
- 1x [M_2.8_BowdenTubeAccessLatch.stl](/STLs/2_MainChamber/StealthMax/M_2.8_BowdenTubeAccessLatch.stl)
- 1x [M_2.6a_PicoAccessLatch.stl](/STLs/2_MainChamber/StealthMax/M_2.6a_PicoAccessLatch.stl)
- 1x [M_2.5a_LogoCap.stl](/STLs/2_MainChamber/StealthMax/M_2.5a_LogoCap.stl)
- 1x [M_2.3_HEPACover.stl](/STLs/2_MainChamber/StealthMax/M_2.3_HEPACover.stl)
- 2x [1.3a_BowdenCap_Closed.stl](/STLs/1_FlowChamber/1.3a_BowdenCap_Closed.stl)

Hardware:
- ??x M3x6 BHCS
- 1x M3x10 (or M3x8) BHCS
- 2x HEPA filters (for Xiaomi Mijia G1)

## Direct On Panel Mount (DOPM) Main Chamber Assembly Continued

1. Route the sensor-out harness through the bottom of [M_2.0_MainChamber.stl](/STLs/2_MainChamber/StealthMax/M_2.0_MainChamber.stl) and into the center area.
Main chamber sensor-out routed bottom
Main chamber sensor-out routed

2. Insert the [M_2.7_IntakeSensorStackAccessLatch.stl](/STLs/2_MainChamber/StealthMax/M_2.7_IntakeSensorStackAccessLatch.stl), [M_2.8_BowdenTubeAccessLatch.stl](/STLs/2_MainChamber/StealthMax/M_2.8_BowdenTubeAccessLatch.stl), and [M_2.6a_PicoAccessLatch.stl](/STLs/2_MainChamber/StealthMax/M_2.6a_PicoAccessLatch.stl), and fasten the [M_2.0_MainChamber.stl](/STLs/2_MainChamber/StealthMax/M_2.0_MainChamber.stl) to the [M_1b.0_FlowChamber_DOPM.stl](/STLs/1_FlowChamber/1b_DirectOnPanelMount/StealthMax/M_1b.0_FlowChamber_DOPM.stl) using 12 M3x6 BHCS.
Main chamber fastened

3. Gentle loosen the [3.2_LidFrontHinge.stl](/STLs/3_Lid/3.2_LidFrontHinge.stl) attached to the [M_3.0_LidFrame.stl](/STLs/3_Lid/StealthMax/M_3.0_LidFrame.stl) so it can freely move.
Main chamber front hinge

4. Fasten the [3.2_LidFrontHinge.stl](/STLs/3_Lid/3.2_LidFrontHinge.stl) to the [M_2.0_MainChamber.stl](/STLs/2_MainChamber/StealthMax/M_2.0_MainChamber.stl) using 2x M3x6 BHCS.
Main chamber front hinge fastened

5. Insert the [M_2.1_CarbonBasket.stl](/STLs/2_MainChamber/StealthMax/M_2.1_CarbonBasket.stl) into the [M_2.0_MainChamber.stl](/STLs/2_MainChamber/StealthMax/M_2.0_MainChamber.stl) at an angle, aligning the protrusions of the carbon basket with the notches of the main chamber. Then rotate the carbon basket to lock it in place.
Main chamber carbon basket inserted angle
Main chamber carbon basket inserted

6. Fasten the sensor-out PCBs to the [M_2.5a_LogoCap.stl](/STLs/2_MainChamber/StealthMax/M_2.5a_LogoCap.stl) using an M3x10 (or M3x8) BHCS. Do not overtighten, as you are threading directly into plastic.
Sensor-out fastened

7. Flip the [M_2.5a_LogoCap.stl](/STLs/2_MainChamber/StealthMax/M_2.5a_LogoCap.stl) and insert it into the center of the [M_2.0_MainChamber.stl](/STLs/2_MainChamber/StealthMax/M_2.0_MainChamber.stl).
Main chamber logo cap inserted

8. Insert the 2x HEPA filters (for Xiaomi Mijia G1) into the center area of the [M_2.0_MainChamber.stl](/STLs/2_MainChamber/StealthMax/M_2.0_MainChamber.stl).
Main chamber filter inserted
Main chamber both filters inserted

9. Snap in the [M_2.3_HEPACover.stl](/STLs/2_MainChamber/StealthMax/M_2.3_HEPACover.stl) and fasten the [M_2.2b_CarbonBasketLid_noHandles.stl](/STLs/2_MainChamber/StealthMax/M_2.2b_CarbonBasketLid_noHandles.stl) to the [M_2.1_CarbonBasket.stl](/STLs/2_MainChamber/StealthMax/M_2.1_CarbonBasket.stl) with 2x M3x6 BHCS.
Main chamber HEPA cover inserted
Carbon chamber lid fastened

10. Snap in the 2x [1.3a_BowdenCap_Closed.stl](/STLs/1_FlowChamber/1.3a_BowdenCap_Closed.stl) to the front of the [M_1b.0_FlowChamber_DOPM.stl](/STLs/1_FlowChamber/1b_DirectOnPanelMount/StealthMax/M_1b.0_FlowChamber_DOPM.stl).
Flow chamber bowden caps inserted

11. Connect the StealthMax to power and continue software configuration according to the [Nevermore Controller Setup Guide](https://github.com/SanaaHamel/nevermore-controller#guide-setup).

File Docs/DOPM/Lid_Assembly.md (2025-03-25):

# Lid Assembly

These are instructions for the StealthMax (300) Back Panel Mount (BPM) or Direct On Panel Mount (DOPM).

## Parts Required

Printed parts:
- 1x [M_3.0_LidFrame.stl](/STLs/3_Lid/StealthMax/M_3.0_LidFrame.stl)
- 1x [M_3.1_LidPanelHolder.stl](/STLs/3_Lid/StealthMax/M_3.1_LidPanelHolder.stl)
- 1x [3.2_LidFrontHinge.stl](/STLs/3_Lid/3.2_LidFrontHinge.stl)

Hardware:
- 1x 250x3mm round acrylic panel (or Ghetto Panel mod)
- 2x M3x25 SHCS

## Lid Assembly

1. Attach [3.2_LidFrontHinge.stl](/STLs/3_Lid/3.2_LidFrontHinge.stl) to the hinge location on [M_3.1_LidPanelHolder.stl](/STLs/3_Lid/StealthMax/M_3.1_LidPanelHolder.stl) using 2x M3x25 SHCS. Do not overtighten, as you are threading directly into plastic.

Lid Front Hinge attach to Lid Panel Holder

2. Flip [M_3.1_LidPanelHolder.stl](/STLs/3_Lid/StealthMax/M_3.1_LidPanelHolder.stl) over and fully insert the 250x3mm round acrylic panel (or Ghetto Panel mod) in the center.

Acrylic Panel insert into Lid Panel Holder

3. Insert [M_3.0_LidFrame.stl](/STLs/3_Lid/StealthMax/M_3.0_LidFrame.stl) into [M_3.1_LidPanelHolder.stl](/STLs/3_Lid/StealthMax/M_3.1_LidPanelHolder.stl), aligning the notches so it sits flush.

Lid Frame insert into Lid Panel Holder

4. Rotate [M_3.0_LidFrame.stl](/STLs/3_Lid/StealthMax/M_3.0_LidFrame.stl) so it becomes locked into [M_3.1_LidPanelHolder.stl](/STLs/3_Lid/StealthMax/M_3.1_LidPanelHolder.stl).

Lid Frame insert locking

[Next: Main Chamber Assembly >](Main_Chamber_Assembly.md)

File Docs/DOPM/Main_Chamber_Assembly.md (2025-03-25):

# Main Chamber Assembly

These are instructions for the StealthMax (300) Back Panel Mount (BPM) or Direct On Panel Mount (DOPM).

## Parts Required

Printed parts:
- 1x [M_2.0_MainChamber.stl](/STLs/2_MainChamber/StealthMax/M_2.0_MainChamber.stl)
- 3x [3.3_LidLatch.stl](/STLs/3_Lid/3.3_LidLatch.stl)

Hardware:
- 6x M3x6 BHCS
- 3mm sponge cord
- Super glue

## Main Chamber Assembly

1. Ensure your 3x [3.3_LidLatch.stl](/STLs/3_Lid/3.3_LidLatch.stl) are able to freely rotate after gently snapping them loose according to the [instructions on the Wiki](https://github.com/nevermore3d/StealthMax/wiki/Assembly#compression-latches).

2. Attach [3.3_LidLatch.stl](/STLs/3_Lid/3.3_LidLatch.stl) to the three sides of [M_2.0_MainChamber.stl](/STLs/2_MainChamber/StealthMax/M_2.0_MainChamber.stl) with the double M3 heat-set inserts near the top, using 2x M3x6 BHCS for each latch. Do not overtighten.

Lid Latch attach to Main Chamber

Lid Latches attached to Main Chamber

3. Attach the 3mm sponge cord all around [M_2.0_MainChamber.stl](/STLs/2_MainChamber/StealthMax/M_2.0_MainChamber.stl) using a thin layer of super glue, according to the [instructions on the Wiki](https://github.com/nevermore3d/StealthMax/wiki/Assembly#lid).

Sponge cord attached to Main Chamber

4. Optional: Dry-fit the [lid assembly](Lid_Assembly.md) on top of [M_2.0_MainChamber.stl](/STLs/2_MainChamber/StealthMax/M_2.0_MainChamber.stl) to ensure all latches properly close. Note that [3.2_LidFrontHinge.stl](/STLs/3_Lid/3.2_LidFrontHinge.stl) will be attached to [M_2.0_MainChamber.stl](/STLs/2_MainChamber/StealthMax/M_2.0_MainChamber.stl) in a later step.

Main Chamber dry fit

[Next: Direct On Panel Mount (DOPM) Electronics Preparation >](DOPM_Electronics_Preparation.md)

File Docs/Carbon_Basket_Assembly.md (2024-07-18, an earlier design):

# Carbon Basket Assembly

These are instructions for the StealthMax (300) Back Panel Mount (BPM) or Direct On Panel Mount (DOPM).

## Parts Required

Printed parts:
- 1x [M_2.1_CarbonBasket.stl](/STLs/2_MainChamber/StealthMax/M_2.1_CarbonBasket.stl)
- 1x [M_2.2b_CarbonBasketLid_noHandles.stl](/STLs/2_MainChamber/StealthMax/M_2.2b_CarbonBasketLid_noHandles.stl)
- 2x [2.9_CarbonBasketLidHandle_Spare.stl](/STLs/2_MainChamber/2.9_CarbonBasketLidHandle_Spare.stl)

Hardware:
- 1.75mm 3D printing filament

## Carbon Basket Assembly

1. Insert a [2.9_CarbonBasketLidHandle_Spare.stl](/STLs/2_MainChamber/2.9_CarbonBasketLidHandle_Spare.stl) into a corresponding slot on [M_2.2b_CarbonBasketLid_noHandles.stl](/STLs/2_MainChamber/StealthMax/M_2.2b_CarbonBasketLid_noHandles.stl) and flip it over.
Carbon basket lid handle inserted
Carbon basket lid handle inserted back

2. Use some 1.75mm 3D printing filament to lock the handle in place from the back, cutting off the excess.
Carbon basket lid handle filament inserted

3. Insert the [M_2.2b_CarbonBasketLid_noHandles.stl](/STLs/2_MainChamber/StealthMax/M_2.2b_CarbonBasketLid_noHandles.stl) on top of the [M_2.1_CarbonBasket.stl](/STLs/2_MainChamber/StealthMax/M_2.1_CarbonBasket.stl) using the orientation indicators for alignment.
Carbon basket lid orientation
Carbon basket lid inserted

[Next: Direct On Panel Mount (DOPM) Main Chamber Assembly Continued >](DOPM_Main_Chamber_Assembly_Continued.md)

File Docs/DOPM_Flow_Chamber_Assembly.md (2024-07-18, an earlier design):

# Direct On Panel Mount (DOPM) Flow Chamber Assembly

These are instructions for the StealthMax (300) Smart Direct On Panel Mount (DOPM).

## Parts Required

Printed parts:
- 1x [M_1b.0_FlowChamber_DOPM.stl](/STLs/1_FlowChamber/1b_DirectOnPanelMount/StealthMax/M_1b.0_FlowChamber_DOPM.stl)
- 4x [1.6_PCBSpacer.stl](/STLs/1_FlowChamber/1.6_PCBSpacer.stl)
- 1x [M_1b.1_RemovableAirDuct_DOPM.stl](/STLs/1_FlowChamber/1b_DirectOnPanelMount/StealthMax/M_1b.1_RemovableAirDuct_DOPM.stl)
- 1x [1.2_AirExhaustSlider.stl](/STLs/1_FlowChamber/1.2_AirExhaustSlider.stl)
- Optional: 1x [1.5_FanWirePin_Spare.stl](/STLs/1_FlowChamber/1.5_FanWirePin_Spare.stl)

Hardware:
- Raspberry Pi Pico W
- Female Dupont pins
- 1x 5-pin female DuPont connector housing
- 1x Delta BFB0712HF (fan)
- 1x M3x10 (or M3x8) BHCS
- 3x M2x4 FHCS

## Direct On Panel Mount (DOPM) Smart Electronics

1. Route the power harness from preparation step 14 through the [M_1b.0_FlowChamber_DOPM.stl](/STLs/1_FlowChamber/1b_DirectOnPanelMount/StealthMax/M_1b.0_FlowChamber_DOPM.stl) as follows, and connect the Matek Systems MBEC6S/MBEC2A buck converter.
DOPM power harness routed

2. Push in the [1.4a_CableEntryCap_M8Barrel.stl](/STLs/1_FlowChamber/1.4a_CableEntryCap_M8Barrel.stl) into the slot.
   - If the cable entry cap doesn't push in easily, carefully shave off 0.3-0.5mm of plastic from the [M_1b.0_FlowChamber_DOPM.stl](/STLs/1_FlowChamber/1b_DirectOnPanelMount/StealthMax/M_1b.0_FlowChamber_DOPM.stl) on both sides of the inside of the hole marked below.
DOPM cable entry cap assembly

3. Route the sensor-in harness from [electronics preparation](/Docs/DOPM_Electronics_Preparation.md) step 7 through the [M_1b.0_FlowChamber_DOPM.stl](/STLs/1_FlowChamber/1b_DirectOnPanelMount/StealthMax/M_1b.0_FlowChamber_DOPM.stl) as follows.
DOPM sensor-in harness routed

4. Route the sensor-out harness from [electronics preparation](/Docs/DOPM_Electronics_Preparation.md) step 8 through the [M_1b.0_FlowChamber_DOPM.stl](/STLs/1_FlowChamber/1b_DirectOnPanelMount/StealthMax/M_1b.0_FlowChamber_DOPM.stl) as follows.
DOPM sensor-out harness routed

5. Crimp 2 DuPont female pins to the remaining uncrimped black and green wires from step 9. Two wires into one DuPont pin is a tight fit, but it can be done with some patience.
DOPM Black/Green DuPont connector

6. Insert the double-crimped green wires into the 4-pin DuPont connector from [electronics preparation](/Docs/DOPM_Electronics_Preparation.md) step 14, and the double-crimped black wires into a 5-pin DuPont connector, together with the pink, yellow, gray, and blue wires of the sensor-in and sensor-out harnesses.
DOPM Black/Green DuPont connector

7. Connect the 2 4-pin and single 5-pin DuPont connector to the Raspberry Pi Pico W and route the cables underneath the Pico W while fastening the Pico W to the [M_1b.0_FlowChamber_DOPM.stl](/STLs/1_FlowChamber/1b_DirectOnPanelMount/StealthMax/M_1b.0_FlowChamber_DOPM.stl) using 4 [1.6_PCBSpacer.stl](/STLs/1_FlowChamber/1.6_PCBSpacer.stl) and 4 M2x6 self-tapping screws. Do not overtighten, as you are threading directly into plastic.
   - It helps to tape down the wires so they all sit flush underneath the Pico W. Fastening the Pico W can be a bit finicky, so be patient.
DOPM Black/Green DuPont connector

8. Fasten the sensor-in PCBs to the [M_1b.0_FlowChamber_DOPM.stl](/STLs/1_FlowChamber/1b_DirectOnPanelMount/StealthMax/M_1b.0_FlowChamber_DOPM.stl) using an M3x10 (or M3x8) BHCS. Do not overtighten, as you are threading directly into plastic.
DOPM sensor-in fastened

9. Place the Delta BFB0712HF fan in the center of the [M_1b.0_FlowChamber_DOPM.stl](/STLs/1_FlowChamber/1b_DirectOnPanelMount/StealthMax/M_1b.0_FlowChamber_DOPM.stl) and hold it down securely while flipping over the flow chamber to attach the Delta BFB0712HF fan using 3x M2x4 FHCS. Do not overtighten, as M2 screws are very fragile.
DOPM Delta BFB0712HF fan placed
DOPM Delta BFB0712HF fan fastened

10. Connect the Delta BFB0712HF fan connector to the 4-pin JST-PH 2.0 male pin/female connector.
DOPM Delta BFB0712HF fan connected

11. Route the Delta BFB0712HF fan cable through the passage on the [M_1b.0_FlowChamber_DOPM.stl](/STLs/1_FlowChamber/1b_DirectOnPanelMount/StealthMax/M_1b.0_FlowChamber_DOPM.stl) and secure it down using the fan wire pin that was printed in the center of the flow chamber. Do not push down on the fan wire pin too hard, as you may damage the cable.
   - If you misplaced the printed fan wire pin, you can reprint it: [1.5_FanWirePin_Spare.stl](/STLs/1_FlowChamber/1.5_FanWirePin_Spare.stl).
DOPM Delta BFB0712HF fan routed

12. Slide the [M_1b.1_RemovableAirDuct_DOPM.stl](/STLs/1_FlowChamber/1b_DirectOnPanelMount/StealthMax/M_1b.1_RemovableAirDuct_DOPM.stl) into the [M_1b.0_FlowChamber_DOPM.stl](/STLs/1_FlowChamber/1b_DirectOnPanelMount/StealthMax/M_1b.0_FlowChamber_DOPM.stl).
DOPM air duct inserted

1.  Slide the [1.2_AirExhaustSlider.stl](/STLs/1_FlowChamber/1.2_AirExhaustSlider.stl) into the [M_1b.0_FlowChamber_DOPM.stl](/STLs/1_FlowChamber/1b_DirectOnPanelMount/StealthMax/M_1b.0_FlowChamber_DOPM.stl).
DOPM exhaust slider inserted

1.  Double-check that all the electronics and wiring matches the picture below before proceeding to the next step.
DOPM flow chamber electronics complete

[Next: Carbon Basket Assembly >](Carbon_Basket_Assembly.md)

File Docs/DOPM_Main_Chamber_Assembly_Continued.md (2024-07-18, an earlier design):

# Direct On Panel Mount (DOPM) Main Chamber Assembly Continued

These are instructions for the StealthMax (300) Smart Direct On Panel Mount (DOPM).

## Parts Required

Printed parts:
- 1x [M_2.0_MainChamber.stl](/STLs/2_MainChamber/StealthMax/M_2.0_MainChamber.stl)
- 1x [M_3.0_LidFrame.stl](/STLs/3_Lid/StealthMax/M_3.0_LidFrame.stl)
- 1x [M_2.7_IntakeSensorStackAccessLatch.stl](/STLs/2_MainChamber/StealthMax/M_2.7_IntakeSensorStackAccessLatch.stl)
- 1x [M_2.8_BowdenTubeAccessLatch.stl](/STLs/2_MainChamber/StealthMax/M_2.8_BowdenTubeAccessLatch.stl)
- 1x [M_2.6a_PicoAccessLatch.stl](/STLs/2_MainChamber/StealthMax/M_2.6a_PicoAccessLatch.stl)
- 1x [M_2.5a_LogoCap.stl](/STLs/2_MainChamber/StealthMax/M_2.5a_LogoCap.stl)
- 1x [M_2.3_HEPACover.stl](/STLs/2_MainChamber/StealthMax/M_2.3_HEPACover.stl)
- 2x [1.3a_BowdenCap_Closed.stl](/STLs/1_FlowChamber/1.3a_BowdenCap_Closed.stl)

Hardware:
- ??x M3x6 BHCS
- 1x M3x10 (or M3x8) BHCS
- 2x HEPA filters (for Xiaomi Mijia G1)

## Direct On Panel Mount (DOPM) Main Chamber Assembly Continued

1. Route the sensor-out harness through the bottom of [M_2.0_MainChamber.stl](/STLs/2_MainChamber/StealthMax/M_2.0_MainChamber.stl) and into the center area.
Main chamber sensor-out routed bottom
Main chamber sensor-out routed

2. Insert the [M_2.7_IntakeSensorStackAccessLatch.stl](/STLs/2_MainChamber/StealthMax/M_2.7_IntakeSensorStackAccessLatch.stl), [M_2.8_BowdenTubeAccessLatch.stl](/STLs/2_MainChamber/StealthMax/M_2.8_BowdenTubeAccessLatch.stl), and [M_2.6a_PicoAccessLatch.stl](/STLs/2_MainChamber/StealthMax/M_2.6a_PicoAccessLatch.stl), and fasten the [M_2.0_MainChamber.stl](/STLs/2_MainChamber/StealthMax/M_2.0_MainChamber.stl) to the [M_1b.0_FlowChamber_DOPM.stl](/STLs/1_FlowChamber/1b_DirectOnPanelMount/StealthMax/M_1b.0_FlowChamber_DOPM.stl) using 12 M3x6 BHCS.
Main chamber fastened

3. Gentle loosen the [3.2_LidFrontHinge.stl](/STLs/3_Lid/3.2_LidFrontHinge.stl) attached to the [M_3.0_LidFrame.stl](/STLs/3_Lid/StealthMax/M_3.0_LidFrame.stl) so it can freely move.
Main chamber front hinge

4. Fasten the [3.2_LidFrontHinge.stl](/STLs/3_Lid/3.2_LidFrontHinge.stl) to the [M_2.0_MainChamber.stl](/STLs/2_MainChamber/StealthMax/M_2.0_MainChamber.stl) using 2x M3x6 BHCS.
Main chamber front hinge fastened

5. Insert the [M_2.1_CarbonBasket.stl](/STLs/2_MainChamber/StealthMax/M_2.1_CarbonBasket.stl) into the [M_2.0_MainChamber.stl](/STLs/2_MainChamber/StealthMax/M_2.0_MainChamber.stl) at an angle, aligning the protrusions of the carbon basket with the notches of the main chamber. Then rotate the carbon basket to lock it in place.
Main chamber carbon basket inserted angle
Main chamber carbon basket inserted

6. Fasten the sensor-out PCBs to the [M_2.5a_LogoCap.stl](/STLs/2_MainChamber/StealthMax/M_2.5a_LogoCap.stl) using an M3x10 (or M3x8) BHCS. Do not overtighten, as you are threading directly into plastic.
Sensor-out fastened

7. Flip the [M_2.5a_LogoCap.stl](/STLs/2_MainChamber/StealthMax/M_2.5a_LogoCap.stl) and insert it into the center of the [M_2.0_MainChamber.stl](/STLs/2_MainChamber/StealthMax/M_2.0_MainChamber.stl).
Main chamber logo cap inserted

8. Insert the 2x HEPA filters (for Xiaomi Mijia G1) into the center area of the [M_2.0_MainChamber.stl](/STLs/2_MainChamber/StealthMax/M_2.0_MainChamber.stl).
Main chamber filter inserted
Main chamber both filters inserted

9. Snap in the [M_2.3_HEPACover.stl](/STLs/2_MainChamber/StealthMax/M_2.3_HEPACover.stl) and fasten the [M_2.2b_CarbonBasketLid_noHandles.stl](/STLs/2_MainChamber/StealthMax/M_2.2b_CarbonBasketLid_noHandles.stl) to the [M_2.1_CarbonBasket.stl](/STLs/2_MainChamber/StealthMax/M_2.1_CarbonBasket.stl) with 2x M3x6 BHCS.
Main chamber HEPA cover inserted
Carbon chamber lid fastened

10. Snap in the 2x [1.3a_BowdenCap_Closed.stl](/STLs/1_FlowChamber/1.3a_BowdenCap_Closed.stl) to the front of the [M_1b.0_FlowChamber_DOPM.stl](/STLs/1_FlowChamber/1b_DirectOnPanelMount/StealthMax/M_1b.0_FlowChamber_DOPM.stl).
Flow chamber bowden caps inserted

11. Connect the StealthMax to power and continue software configuration according to the [Nevermore Controller Setup Guide](https://github.com/SanaaHamel/nevermore-controller#guide-setup).

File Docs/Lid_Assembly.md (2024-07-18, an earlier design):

# Lid Assembly

These are instructions for the StealthMax (300) Back Panel Mount (BPM) or Direct On Panel Mount (DOPM).

## Parts Required

Printed parts:
- 1x [M_3.0_LidFrame.stl](/STLs/3_Lid/StealthMax/M_3.0_LidFrame.stl)
- 1x [M_3.1_LidPanelHolder.stl](/STLs/3_Lid/StealthMax/M_3.1_LidPanelHolder.stl)
- 1x [3.2_LidFrontHinge.stl](/STLs/3_Lid/3.2_LidFrontHinge.stl)

Hardware:
- 1x 250x3mm round acrylic panel (or Ghetto Panel mod)
- 2x M3x25 SHCS

## Lid Assembly

1. Attach [3.2_LidFrontHinge.stl](/STLs/3_Lid/3.2_LidFrontHinge.stl) to the hinge location on [M_3.1_LidPanelHolder.stl](/STLs/3_Lid/StealthMax/M_3.1_LidPanelHolder.stl) using 2x M3x25 SHCS. Do not overtighten, as you are threading directly into plastic.

Lid Front Hinge attach to Lid Panel Holder

2. Flip [M_3.1_LidPanelHolder.stl](/STLs/3_Lid/StealthMax/M_3.1_LidPanelHolder.stl) over and fully insert the 250x3mm round acrylic panel (or Ghetto Panel mod) in the center.

Acrylic Panel insert into Lid Panel Holder

3. Insert [M_3.0_LidFrame.stl](/STLs/3_Lid/StealthMax/M_3.0_LidFrame.stl) into [M_3.1_LidPanelHolder.stl](/STLs/3_Lid/StealthMax/M_3.1_LidPanelHolder.stl), aligning the notches so it sits flush.

Lid Frame insert into Lid Panel Holder

4. Rotate [M_3.0_LidFrame.stl](/STLs/3_Lid/StealthMax/M_3.0_LidFrame.stl) so it becomes locked into [M_3.1_LidPanelHolder.stl](/STLs/3_Lid/StealthMax/M_3.1_LidPanelHolder.stl).

Lid Frame insert locking

[Next: Main Chamber Assembly >](Main_Chamber_Assembly.md)

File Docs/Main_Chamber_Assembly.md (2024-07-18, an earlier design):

# Main Chamber Assembly

These are instructions for the StealthMax (300) Back Panel Mount (BPM) or Direct On Panel Mount (DOPM).

## Parts Required

Printed parts:
- 1x [M_2.0_MainChamber.stl](/STLs/2_MainChamber/StealthMax/M_2.0_MainChamber.stl)
- 3x [3.3_LidLatch.stl](/STLs/3_Lid/3.3_LidLatch.stl)

Hardware:
- 6x M3x6 BHCS
- 3mm sponge cord
- Super glue

## Main Chamber Assembly

1. Ensure your 3x [3.3_LidLatch.stl](/STLs/3_Lid/3.3_LidLatch.stl) are able to freely rotate after gently snapping them loose according to the [instructions on the Wiki](https://github.com/nevermore3d/StealthMax/wiki/Assembly#compression-latches).

2. Attach [3.3_LidLatch.stl](/STLs/3_Lid/3.3_LidLatch.stl) to the three sides of [M_2.0_MainChamber.stl](/STLs/2_MainChamber/StealthMax/M_2.0_MainChamber.stl) with the double M3 heat-set inserts near the top, using 2x M3x6 BHCS for each latch. Do not overtighten.

Lid Latch attach to Main Chamber

Lid Latches attached to Main Chamber

3. Attach the 3mm sponge cord all around [M_2.0_MainChamber.stl](/STLs/2_MainChamber/StealthMax/M_2.0_MainChamber.stl) using a thin layer of super glue, according to the [instructions on the Wiki](https://github.com/nevermore3d/StealthMax/wiki/Assembly#lid).

Sponge cord attached to Main Chamber

4. Optional: Dry-fit the [lid assembly](Lid_Assembly.md) on top of [M_2.0_MainChamber.stl](/STLs/2_MainChamber/StealthMax/M_2.0_MainChamber.stl) to ensure all latches properly close. Note that [3.2_LidFrontHinge.stl](/STLs/3_Lid/3.2_LidFrontHinge.stl) will be attached to [M_2.0_MainChamber.stl](/STLs/2_MainChamber/StealthMax/M_2.0_MainChamber.stl) in a later step.

Main Chamber dry fit

[Next: Direct On Panel Mount (DOPM) Electronics Preparation >](DOPM_Electronics_Preparation.md)

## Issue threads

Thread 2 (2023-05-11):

Wich fan to use with the stealth max

Switch-Witch, 2023-05-11:
Hi,

wich fan could be used with the stealth max? I didn`t find any notice in the description.

bartlammers, 2023-05-11:
Delta bfb0712hf, try to find one with a silver label.
They are sold on AliExpress and the likes, it's a round 65mm fan

Switch-Witch, 2023-05-11:
Thank you - I`ll try to find a silver label

KepleRPL, 2023-05-18:
What about Sanyo 9TD12P6G001 (70x20mm)?

0ndsk4, 2023-05-18:
Once everything works well with the delta, a sanyo variant is a simple cut and paste mod. But it’s a pain maintaining different versions at a stage where stuff still changes.
The sanyo is a superior fan, but since the main point of stealthmax was to make everything simpler and cheaper, it made sense starting out with the fan that can be had in the 5-20$ range instead of 45-65$.

Closed 2023-05-18.

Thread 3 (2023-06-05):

Which parts to print?

fabikroeger, 2023-06-05:
Hello there,

i want to print the StealthMax but i am not sure which parts to print neither if the offered parts in the .3mf are complete .
A list of parts which needed to be printed would be awesome.

Greetings
Fabian

0ndsk4, 2023-06-05:
Hey! Thanks for the interest! Stealthmax is still being worked on, and as such there’s no official bom or build guide quite yet. I did post a few stls to make it easier to test print the large parts with success.
If you’re interested in trying the early build please join Nevermore discord to see where stuff is at and share stealthmax experiences. Hoping to get this to a public beta stage within a few weeks.

https://discord.gg/UbsMA7gb

Closed 2023-06-05.

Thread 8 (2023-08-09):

What is this pin for?

SarcasmRules, 2023-08-09:
What is this pin for in the Flow_Chamber.stl?
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

0ndsk4, 2023-08-09:
It’s a spacer for when stacking the VOC sensors. Makes it a bit more stable.

SarcasmRules, 2023-08-09:
Thx, much appreciated.
One more question, there are 2 of each sensors on the BOM but only one of each is in the CAD, assuming both are intake. In the controller section by SanaaHamel there is an intake and exhaust sensor(s); where are the other two installed?

0ndsk4, 2023-08-09:
There are two sensor pairs. A BME280 and a SGP40 are stacked on top of each other - one pair at the intake (flow chamber), one pair at the exhaust (center hub next to the pico).

SarcasmRules, 2023-08-10:
That's what I was missing, thanks! :) I'm printing one up, have the flow and main chamber done, printing the basket now.
It looks nice but way bigger than I thought (TWSS!).

mrzottel, 2023-11-24:
So just to be sure - those two holes left and right of the pico are used for mounting the exhaust sensors?

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

0ndsk4, 2023-11-25:
Yes. Both are not needed tho, most would do a dual sensor stack using a single mounting hole. Saves on wiring.

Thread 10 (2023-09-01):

Nevermore BFB0712HF 65mm Fan

Magneticrob1, 2023-09-01:
What is or how do i find the pinout for this fan Nevermore BFB0712HF 65mm Fan

0ndsk4, 2023-09-01:
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

it has the same standard pinout as a regular 4-pin fan, see which wire is which in the connector in the pic top right!

Magneticrob1, 2023-09-01:
Thank you so much for that info

Sent from Outlook for Android<https://aka.ms/AAb9ysg>
________________________________
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

mrzottel, 2023-12-19:
Just be careful - for some reason, ground of the output sensors is connected to fan control in the picture - I guess it should be connected to the common ground as well... ;)

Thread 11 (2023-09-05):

Half the parts too big to print on my printer

Draegon366, 2023-09-05:
In what way could I slice the large parts to be able to fit on a 220x220mm print bed?

0ndsk4, 2023-09-05:
Stealthmax is a large-scale filter made for larger machines. It will not fit on a 220 bed unfortunately.

The new smaller size is made to fit 250x250, but it’s hard to make it much smaller than that. Regular version needs a 300mm bed even. Sorry :/

Closed 2023-09-05.

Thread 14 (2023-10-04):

Questions about 1-Flow_Chamber.stl

viacheslav-s, 2023-10-04:
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
1. I need to remove it?
2. Is this slot for step-down regulator?

0ndsk4, 2023-10-04:
1. No. It’s an extra wire path for later additions (like a n exhaust servo), currently unused and no need to open it.
2. No again. It fits a pin that seems to have disappeared from the flow chamber stl. You can export the pin from the “for print pin.stp” in the main directory.

Micro BEC goes here:
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

viacheslav-s, 2023-10-06:
@0ndsk4 got it, thanks
I want to record assembling video of Stealthmax, If I have enough time

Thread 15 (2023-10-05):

SGP40 'Unable write i2c device'

Luix333, 2023-10-05:
Hi, I'm trying to set up an SGP40 on klipper. ([following this](https://github.com/nevermore3d/Nevermore_Max/tree/master/Software/Klipper))

I'm getting this error: Unable write i2c device
I also can't find it with a sudo i2cdetect (raspberry pi), but I know it's working because I'm able to get reading from it running some [example scripts](https://github.com/itsnils/Sensirion_SGP40)

my config: (the HTU21D is working fine, the error happens just when I uncomment the SGP40 config section)

[temperature_sensor tvoc_temp_humidity]
sensor_type:        HTU21D
i2c_address:        64
i2c_mcu:            rpi
i2c_bus:            i2c.3
i2c_speed:          400000
htu21d_resolution:  TEMP14_HUM12
htu21d_report_time: 5

[sgp40]

[temperature_sensor tvoc_sensor]
sensor_type:            SGP40
i2c_mcu:                    rpi
i2c_bus:                     i2c.0
i2c_speed:                400000
ref_temp_sensor:           htu21d tvoc_temp_humidity
ref_humidity_sensor:    htu21d tvoc_temp_humidity

Any advice would be appreciated.

stansfie, 2023-11-14:
Hi Luix333,

I'm no expert but I had the same problem using a cheap SGP40 chip from AE and am not sure if the same problem is observed elsewhere on better quality chips.

I ended up changing some of sgp40.py to add an INITIALIZE command I saw in some of the examples and removed the feature queries later in the init procedure which I think reset the device and result in subsequent queries from i2cdetect failing after running klipper:

`SGP40_CMD = {
    "INITIALIZE" : [0x36, 0x82],
    "SOFT_RESET" : [0x00, 0x06],
    "FEATURE_SET" : [0x20, 0x2F],
    "SELF_TEST" : [0x28, 0x0E],
    "MEASURE_RAW_NO_COMP" : [0x26, 0x0F, 0x80, 0x00, 0xA2, 0x66, 0x66, 0x93]
}`

and

`def _init_sgp40(self):
        # Check serial number
        serial_number = self._read_and_check(SGP40_CMD["INITIALIZE"], wait_time_s = 0.5)
        if serial_number[0] != 0x0000:
            logging.exception("sgp40: Serial number does not match")

        # Feature set
        # feature_set = self._read_and_check(SGP40_CMD["FEATURE_SET"], wait_time_s = 0.5)
        # if feature_set[0] & 0xFF00 != 0x3200:
        #    logging.exception("sgp40: wrong feature set returned by sensor")

        # Self test
        # self_test = self._read_and_check(SGP40_CMD["SELF_TEST"], wait_time_s = 0.5)
        # if self_test[0] != 0xD400:
        #    logging.exception("sgp40: Self test error")

        # Reset
        # self._read_and_check(SGP40_CMD["SOFT_RESET"], read_len = 0, wait_time_s = 0.5)

        self.sample_timer = self.reactor.register_timer(self._sample_sgp40)
`

Please note that the feature set output in the above is different to the original as per some of the discussion forums on adafruit. It shouldn't matter since it's commented out :)

Hope that helps.

stansfie, 2023-11-15:
Just a correction - you can probably leave in the #self_set section - just remove the Reset from _init_sgp40

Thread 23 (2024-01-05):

recommended print settings

slaesh, 2024-01-05:
hey there, great project - thanks!

I am planning to build a stealthmax s..
first (maybe not last.. ;D) question: **any recommended print settings?**

wall counts?
infill?
etc.. :)

slaesh, 2024-01-05:
thanks for that quick response! =) will let this issue open, until I created a PR for adding this somewhere into the README.. ;)

itay-grudev, 2024-01-24:
@slaesh There is a WIP [Wiki](https://github.com/nevermore3d/StealthMax/wiki/Print-Settings) page now.

Closed 2024-01-24.

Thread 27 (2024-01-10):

L Shaped Flow chamber support adhesion

itay-grudev, 2024-01-10:
L Shaped Flow chamber support suffers from poor bed adhesion and is very likely to be clipped by the printer head and just moved around during printing. I found mine on the other side of the print bed and glued it back in place hoping it would work even with a few layers missing.

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

If instead it is designed with its own skirt, I think it would be much easier to print. It doesn't even have to be symmetric, as long as it has slightly more surface area.

I suppose the same argument applies to the other rectangular support, although it seems to be much more stable.

kenny00111, 2024-02-01:
Yes I agree, same problem for me

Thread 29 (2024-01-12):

StealthMax S - missing part

theminjus, 2024-01-12:
Hello, where did the missing part for mounting VOC go?
Weird-shaped 3 part, really tiny it clicked into Main_Chamber middle.

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

theminjus, 2024-01-12:
I see, it's waiting to be added in the pull request.
https://github.com/nevermore3d/StealthMax/pull/26

Closed 2024-01-12.

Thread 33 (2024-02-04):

Easy to print Carbon Basket?

hillerpa, 2024-02-04:
So the Carbon Baselt is not that easy to print and needs huge time due to this.
For Silica gel I had used this print [Silica Gel Box](https://www.printables.com/de/model/669387-silica-gel-box-optimized-for-super-fast-print)
It is really stable - I think this could be also an option for the basket to improve the print time alot (inside and outside) vs the current comb Structure due to it is still a straight line.
Unfortunately I'm not able to draw this in CAD but maybe somebody here is a good CAD guy...

Thank you for the Awesome work!!
I'm currently still in the printing procedure but this is really awesome.

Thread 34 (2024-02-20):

Would printing in PETG be a good idea?

OXERY, 2024-02-20:
As the title says, I was thinking about printing all parts in PETG, as it's rather cheap and the parts are outside the case.
What would you say? Nevertheless, I do have asa/abs on hand, but as it's 8€/kg vs 20€/kg.. I simply wanted to ask.

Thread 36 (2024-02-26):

STL's potentailly in incorrect place

Dark360, 2024-02-26:
I am currently printing my Stealthmax for my Voron and after chatting with someone on Discord who is printing the Direct option they noticied that they were missing the supports my Main Chamber.

When I said the supports were built in, they said they had to export the STEP files of the Main Chamber directly from the F3D as there were no STL's for the direct option. (I understand that the supports are in the F3D, but these are hidden by default.)

I think the issues lies with this statement:

_"Try these modded files. They replace the files with the same numbers from the regular STL directory."_

**2-Main_Chamber.stl** and **2-Main_Chamber_HEPA_Cover.stl** are not in the **STL** directory, but in **STL/Voron-Back-Panel-Cutout_Mount** directory

Can these STL's be moved into the **STL** directoy or copies added to the **STL/Direct-On-Panel_Mount** subdirectory?

FatalBulletHit, 2024-03-13:
Should be fixed with #37 and #39 and will be improved for the StealthMax S soonTM as well.

Closed 2024-03-17.

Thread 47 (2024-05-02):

Can this be used as an unmounted enclosure air scrubber for print farms?

PupperooX, 2024-05-02:

PupperooX, 2024-05-02:
Would it still work effectively at filtering and recirculating the air in a 1m³ enclosure?

0ndsk4, 2024-05-31:
it will work well for a 1m3 enclosure!

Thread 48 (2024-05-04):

Printing Hinges

jetcat-bob, 2024-05-04:
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
How well does printing in air work for the hinge pins? Am I doing something wrong?

Using SS with recommended settings. Haven't printed yet!

jetcat-bob, 2024-05-04:
May have answered my own question. Print exterior perimeter first, inside only.

0ndsk4, 2024-05-04:
No, that’s positioned upside down. Will fix!

jetcat-bob, 2024-05-04:
Thanks!

igiannakas, 2024-05-30:
> No, that’s positioned upside down. Will fix!

hi there

Has this been corrected? What is the right orientation to print these? Struggling with print failures on them :(

jetcat-bob, 2024-05-30:
It is still not correct. You will need to flip it over.

On Thu, May 30, 2024 at 2:55 AM Ioannis Giannakas ***@***.***>
wrote:

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

--

Bob Wilcox

0ndsk4, 2024-05-31:
Sorry, i re-oriented the file 27 days ago but for some reason it never pushed. Now its correct. Cherck the stealthmax wiki for latch print instructions!

Closed 2024-05-31.

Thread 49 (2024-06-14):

Expand Aliexpress links on BOM Table

TexZeTech, 2024-06-14:
I run pihole & it breaks the url shorteners from AliExpress could you please change the links here

https://github.com/nevermore3d/StealthMax/tree/main/assets/_unsorted/PCO#bom-and-materials-for-an-alpha-unit

to their expanded form?

https://www.aliexpress.com/item/1005005801651041.html

https://www.aliexpress.com/item/1005001645522380.html

https://www.aliexpress.com/item/1005005171204012.html

https://www.aliexpress.com/item/1005005210228166.html

https://www.aliexpress.com/item/32879506129.html

https://www.aliexpress.com/item/1005002413652525.html

https://www.aliexpress.com/item/1005001847189640.html

https://www.aliexpress.com/item/1005004974934366.html

I believe these are all the links however I could have missed one please verify.

Have a good one.

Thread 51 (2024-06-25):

Fan control is not linear

nfettinger, 2024-06-25:
Delta BFB0712HF
When controlling the fan duty cycle from the Mainsail page, the fan seems to only respond in RPM changes when using 80-100%
IMO, the scale needs to be adjusted since the lower end deadspace is so large.

Relevant settings in printer.cfg:
```
[nevermore]
bt_address: 28
# These `fan_power_*` entries are for a DELTA BFB0712HF (StealthMax BOM)
# If you have a different fan then play with these numbers to your satisfaction.
# See full config documentation for details.

# Various settings for the fan.
# float \in [0, 1] - Fan power used when the automatic policy nor overridden
fan_power_passive: 0

# float \in [0, 1] - Fan power used when the automatic fan policy is active.
fan_power_automatic: 1

# float \in [0, 1] - Coefficient applied to the fan power.
# i.e. Limits the maximum speed of the fan. Useful for things like managing noise.
# e.g. At 0.75, requesting 100% power will run the fan at 75% power.
fan_power_coefficient: 1

# seconds, how long to keep filtering after the policy would otherwise stop
fan_policy_cooldown: 120
# voc index, 0 to disable, filter if any sensor meets this threshold
# NB: if < 200 then fan will engage when in the 'nominal' region (see VOC guide)
fan_policy_voc_passive_max: 0
# voc index, 0 to disable, filter if the intake exceeds exhaust by at least this much
fan_policy_voc_improve_min: 0

# Fan Policy - Thermal Limit
# Controls how/when the fan power is throttled down if the temperature is too high.
# See Fan Control section for details.

# float, Celsius, temperature at which point thermal limiting starts being applied
fan_thermal_limit_temperature_min: 55
# float, Celsius, temperature at which point thermal limiting is fully applied
fan_thermal_limit_temperature_max: 65
# float \in [0, 1], 1 to disable the thermal limiter
# 0 to disable the fan at max temp
# 0.5 to half the fan speed at max temp
# 1 to effectively disable the thermal limiter (no scaling at max temp)
fan_thermal_limit_coefficient: 0

# Optional
# This 'temperature' sensor only serves to draw the intake VOC index on
# Mainsail's temperature plot.
[temperature_sensor nevermore_intake_VOC]
sensor_type: NevermoreSensor
sensor_kind: intake
#plot_voc: true

[temperature_sensor nevermore_exhaust_VOC]
sensor_type: NevermoreSensor
sensor_kind: exhaust
#plot_voc: true
```

nfettinger, 2024-06-28:
I have verified the output of the Pico is performing the duty cycle appropriately. I am measuring a 500mV Peek to Peek voltage across the pin at a frequency of 25khz. I believe a level shifter is what may be needed.

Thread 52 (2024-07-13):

Compression latch has mid-air features

m-schubert, 2024-07-13:
I'm having a lot of print failures on the compression latches. There are a few layers in there that are expected to be printed in thin air (not bridged). Any hints? Should I be using supports?

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

I'm using SuperSlicer, 0.25mm first layer, 0.2mm layers from there.

kellybyrd, 2024-07-13:
These mid-air features are intentional. They're print-in-place hinges and seams.
In order to get this to work, I changed my first layer height to 0.2mm.

kellybyrd, 2024-07-14:
Agree the slice will look the same with 0.2 first layer. What I meant was this:

I had all the latches fail several times, with 0.25 first layer using SuperSlicer. I tried several different fixes, brims, more squish, slower printing speeds, etc. I changed the first layer height to 0.2 and they all succeeded

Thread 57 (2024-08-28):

Stealthn Max 250 DOPM - Flow chamber, two of the mounting nut threads are reversed

jetcat-bob, 2024-08-28:
The two nut threads by the output port are reversed thread. I fixed it by mirroring two of the S_0b.0_ChamberExhaustConnection_DOPM.stl. Probably better if it was fixed in the flow chamber stl ( S_1b.0_FlowChamber_DOPM.stl )

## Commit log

2023-04-17 Correctly oriented hinges and main latch for stealthmax. 0.2mm layers, 4+ walls
    [Hinges_cura_export.3mf]
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2023-04-17 Update Hinges_cura_export.3mf
    removed small non-essential 3mf object
    [Hinges_cura_export.3mf]
2023-05-01 warp protectors and slider bottom layer safety
    ensures a higher success rate, adding material at the remaining corners that could lift. also adds some filament near the slider path that will need to be removed (ensures two bottom lines at a key position where one line might fail more easily)
2023-05-03 edited flowchamber by blamm
    added bracing and fixed too thin parts
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2023-05-22 Add files via upload
    hinge that supports up to 8 walls @ 0.4mm for less breakability
    [heavy_duty_hinge.stl]
2023-06-21 if print-in-place-handle breaks, replace it!
    ...using a few 1.75mm filament pieces as shafts to pivot around
    [Replacement_Lid_Handle(insert_1,75mm_filament).stl]
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2023-07-03 latches connected 0.2mm at bottom layer
    lessens risk of them coming loose, runing the print.
    [Basket_Lid3.stl]
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2023-07-12 Update README.md
    Fixed missing inserts and foam cord
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2023-07-17 fixed faulty lid tab
    lid tab had been walled up for some reason, tab slot is now cleared
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2023-07-21 Fixes
    1. Cable hole between flow and main chamber now fits an entire usb c connector (>10,5x7mm).
    2. Two insert holes at the chamber mount was widened to correct 4,7mm size.
    3. Added punch-out bolt positions to rotate the GPU fan 60 degrees for easier wiring as fan makes differ.
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2023-07-28 directory name change
    [2-Main_Chamber_HEPA_Cover.stl, 2-Main_Chamber_Voron_Hub_Cap.stl, Basket_Lid3.stl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]
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2023-08-28 minor fixes
    seal cutout was missing on main chamber, alignment was off on two holes in the flow chamber
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2023-09-15 fixed latches, fix fan mount, fix back panel holes
2023-09-18 fixed: main chamber mirrored the wrong way
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2023-09-28 feat: extended vent cover track fix: aligned lower chamber to upper chamber
2023-10-01 mounting holes correct size, added punch-out mslider bottom for easier serial plaque installation
2023-10-07 naming schema and PCO filter
    [2-Main_Chamber_HEPA_Cover.stl, 2-Main_Chamber_Voron_Hub_Cap.stl, 3_LID_Basket_250.stl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]
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2023-10-09 added bracing to avoid knocking the legs of the filter over
    [TiO2_HEPA_Filter_Holder.stl]
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2023-10-13 added panel mount to cad
    [MicroFit_5_pin_byeverydaybludger.stl]
2023-10-13 pure m8 dc barrel connector
    [M8_DC_barrel_by_Ark.stl]
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2023-10-23 thin main chamber wall fixed
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2023-11-04 customs flow chamber isiks tech sensor mount
    [Isiks_Tech_Dual_Sensor_PCB_v5.stl]
2023-11-07 removes pico, adds a QtPy rp2040 behind the dc connector port
    will likely work for other usb-c rp2040 zeros too
    [Cable_Entry_QtPy_holder_by_fboc.stl, cable_entry_QtPy_by_fboc.step]
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2023-12-06 added on-panel-mounting option to f3d
    added on-panel-mounting option to f3d
    [Cable_Entry_QtPy_holder_by_fboc.stl, Isiks_Tech_Dual_Sensor_PCB.stl, Spare_Sensor_holder(Original).stl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]
2023-12-09 parametric_exhaust fitting
    allows for different panel thicknesses other than the standard 4mm
    [10mm_Voron_Exhaust_Fitting.stl, 11mm_Voron_Exhaust_Fitting.stl, 12mm_Voron_Exhaust_Fitting.stl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]
2023-12-10 position your ercf above the stealthmax.
    [ercf_halter__by_BO_Andy.stl, ercf_holder_by_BO_Andy.f3d]
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2023-12-24 Added S Moniker to lid design as per Exerqtors design
    [3_LID_Basket_250.stl.stl]
2023-12-25 longer fan slot pin
    Extended version of the fan slot pin to better fix the cable. STEP file was extra created for customizations.
    [fan_slot_pin.step, fan_slot_pin_longer.stl]
2023-12-25 Microfit 3pin fit adapted
    Microfit 3pin connector housing adapted for better assembly.
    [MicroFit_3_pin_12V_5V_by_Sanaa.3mf, MicroFit_3_pin_12V_5V_by_Sanaa.stl]
2023-12-25 fan hole plug fan alternative position
    fan hole plug for alternative position.
    [fan_hole_plug_alternative_ position.stl]
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2023-12-30 Fix: Wire channel overhang; Thicker exhaust swivel; Minor fixes
2023-12-30 Fix: Updated exhaust wheel to fit with the latest flow chamber
2023-12-30 Minor Flow Chamber / Exhaust Wheel fixes
2024-01-10 Add missing sensor_holder STL
    [6-Sensor_Holder.stl]
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2024-01-11 Add files via upload
    Longer Screws for the Direct Mount SMS
    [SMS_DPMount_Screws_P3mm_P6mm_P9mm.3mf]
2024-01-17 Flip sensor_holder to correct orientation
    To match the optimal orientation of the actual sensor on the SGP facing outwards when slid into the holder
    [6-Sensor_Holder.stl]
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2024-02-16 nevermore hepa basket update
    [3_Carbon_Basket_HEPA_Cap_and_Pin.stl, 3_LID_Basket_250.stl, 3_LID_Basket_250.stl.stl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]
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2024-03-07 Rename 1-Flow_Chamber.stl to 1_0 Flow Chamber.stl
    [1_0 Flow Chamber.stl]
2024-03-07 Rename 2-Main_Chamber.stl to 2_0 Main Chamber.stl
    [2_0 Main Chamber.stl]
2024-03-07 Rename 2-Main_Chamber_HEPA_Cover.stl to 2_1 HEPA Cover.stl
    [2-Main_Chamber_HEPA_Cover.stl, 2_1 HEPA Cover.stl]
2024-03-07 Rename 2-Main_Chamber_Voron_Hub_Cap.stl to 2_3 Logo Cap.stl
    [2_3 Logo Cap.stl]
2024-03-07 Rename 4-Voron_Chamber_Connection_and_Exhaust.stl to 0_0 Back Panel Mount.stl
    [0_0 Back Panel Mount.stl]
2024-03-07 Rename [a]Hinge_and_Latches.stl to 3_1 Lid Front Hinge.stl
    [3_1 Lid Front Hinge.stl]
2024-03-07 Rename [a]Slider_and_Plugs.stl to 1_1 Air Exhaust Slider.stl
    [1_1 Air Exhaust Slider.stl]
2024-03-07 Rename Carbon_Basket.3mf to 2_1 Carbon Basket.3mf
    [2_1 Carbon Basket.3mf]
2024-03-07 Rename Carbon_Basket.stl to 2_1 Carbon Basket.stl
    [2_1 Carbon Basket.stl]
2024-03-07 Rename Basket_Lid3.stl to 2_2 Carbon Basket Lid.stl
    [2_2 Carbon Basket Lid.stl, Basket_Lid3.stl]
2024-03-07 Update and rename 2_1 HEPA Cover.stl to 2_3 HEPA Cover.stl
    [2_3 HEPA Cover.stl]
2024-03-07 Rename 2_3 Logo Cap.stl to 2_5 Logo Cap.stl
    [2_5 Logo Cap.stl]
2024-03-07 Rename Lid_3mm_250mm.stl to 3_0 Lid.stl
    [3_0 Lid.stl, Lid_3mm_250mm.stl]
2024-03-07 Rename Panel_Holder_3mm_250mm.stl to 3_3 Window Holder.stl
    [3_3 Window Holder.stl]
2024-03-07 Reworked electronics placement and wire routing
    [0_0 Back Panel Mount.stl, 0_1 Back Panel Mount Cover.stl, 0_2 Voron Exhaust Fitting.stl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]
2024-03-07 adds direct och panel mounting for stealthmax S
    [4-Chamber_Connection_and_Exhaust.3mf]
2024-03-13 Minor QOL improvements and repo restructure pt. 1
    [0_0 Back Panel Mount.stl, 0_1 Back Panel Mount Cover.stl, 0_2 Voron Exhaust Fitting.stl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]
2024-03-18 Minor QOL improvementes and repo restructure pt. 2
    [0a.1_BackPanelMount_BPM.stl, 0a.2_BackPanelMountCover_BPM.stl, 0b.2_ExhaustPipe_DOPM.stl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]
2024-03-22 Fixed File Names
    [S_3.0_LidFrame.stl]
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2024-03-26 Minor QOL improvements and fixes
    [M_2.5a_LogoCap.stl, M_2.5b_LogoCap_MMU.3mf]
2024-03-27 Fixed 2.9_CarbonBasketLidHandle_Spare.stl
    [2.9_CarbonBasketLidHandle_Spare.stl]
2024-04-01 Added Bowden Cap PG7
    [Bowden Cap PG7 (by FatalBulletHit).step, BowdenCap_PG7.stl]
2024-04-14 renamed Carbon Basket Lid STL variants
    [M_2.2b_CarbonBasketLid_noHandles.stl, M_2.2c_CarbonBasketLid_MMU.3mf, M_2.2d_CarbonBasketLid_MMU_noHandles.3mf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]
2024-04-14 removed spaces from folder names
    [S_1b.1_RemovableAirDuct_DOPM.stl]
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2024-04-19 fixed appearances in .f3d and updated dopm
    [M_3.0_LidFrame.stl, S_3.0_LidFrame.stl]
2024-04-25 Umbilical entry to the chamber via the flow chamber
    [StealthMax 300 flow chamber for umbilical.stl]
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2024-07-19 Fixed orientation of two images to avoid confusion about cable order in connectors
2024-08-18 updated cpap, no longer WIP
    [4.0.0_IntakeAdapterLeft.stl, 4.0.1_IntakeAdapterRight.stl, 4.0.2_IntakeLeft.stl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]
2024-10-07 fixed mirrored panel screw holes
    all screws should now turn the right direction
2024-10-08 fixed threads and intake sensor mount
2024-10-08 orientation fix + intake sensor separate/sandwhich
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2024-10-18 Adding User Mod, Vinny (#61)
    * Create CADs
    * Adding User Mod, VIN-y
    [10_NM_StealthMax_Mod-FlowChamber_Mod.step, 10_NM_StealthMax_Mod-Intake_Funnel_x4.step, 10_NM_StealthMax_Mod-Output_Funnel.step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]
2024-10-31 Added ECAS Bowden Cap usermod (#62)
    [BowdenCap_ECAS.stl]
2024-12-13 add umbilical mount BPM usermod (#63)
    [umbilical-mount-bpm.stl]
2025-01-29 Usermods add Voronexhaustfitting_BPM with a btt smart filament sensor bracket (#64)
    * Add files via upload
    * updated usermods
    [bowdencap_ptfe.stl]
2025-03-25 add documentation for back panel mount stealthmax (#65)
    * move dopm files to dopm folder
    * chamber assembly drafted
    * add all images renamed
    * add supports and heatset pictures
    * fixed some links
    * finish first draft pass, missing links for mounting
    * finished mounting section
    * final draft
